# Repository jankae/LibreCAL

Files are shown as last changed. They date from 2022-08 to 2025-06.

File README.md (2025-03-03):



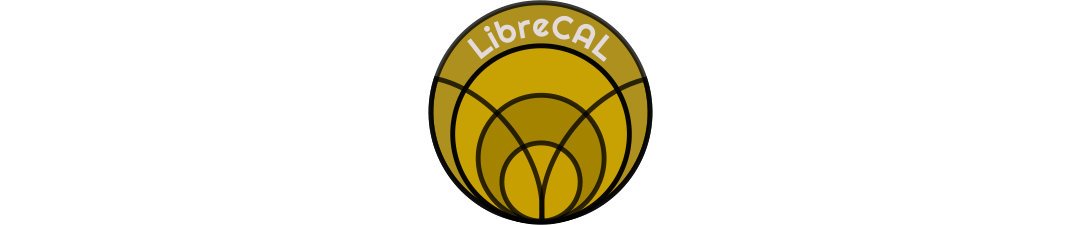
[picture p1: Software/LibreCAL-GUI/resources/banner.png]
LibreVNA


# LibreCAL
**4-port, 9kHz to 6GHz eCal module for VNAs**

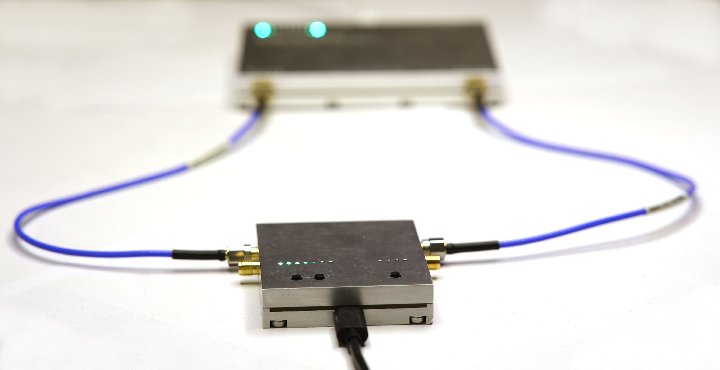
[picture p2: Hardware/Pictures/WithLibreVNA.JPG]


<p float="center">
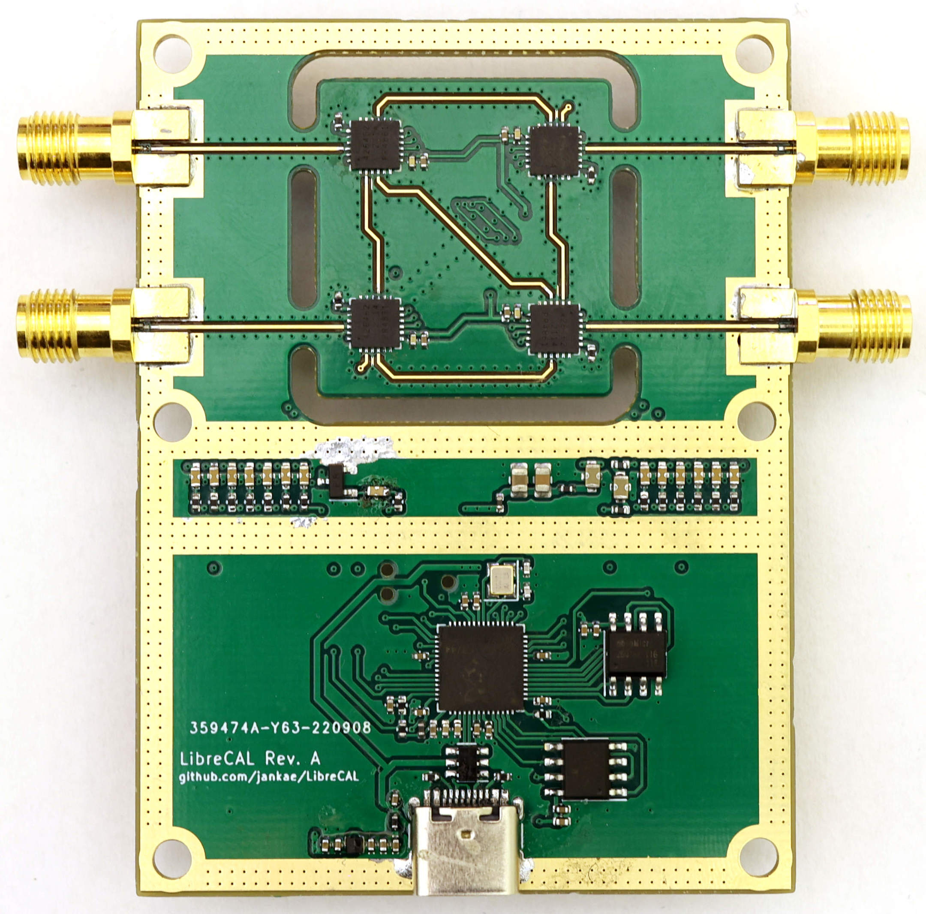
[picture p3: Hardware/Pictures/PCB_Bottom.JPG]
  
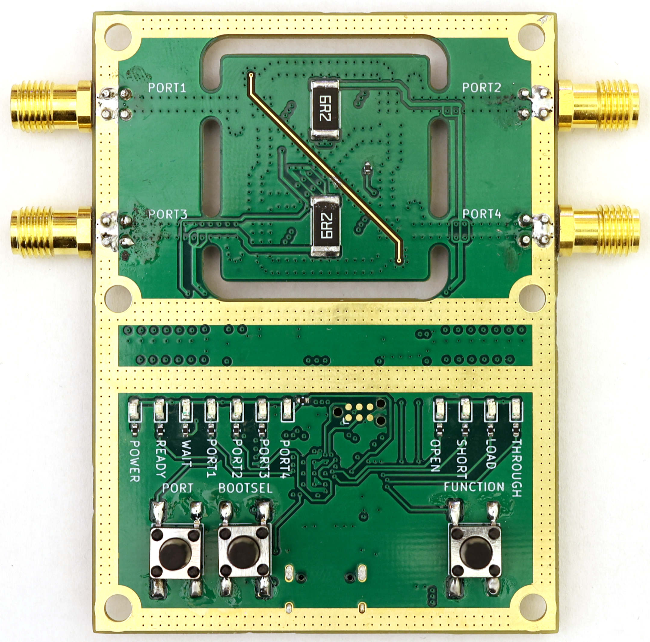
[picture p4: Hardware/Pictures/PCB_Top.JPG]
   
</p>

## Quick Start
* You can find released versions of the GUI application and the device firmware [here](https://github.com/jankae/LibreCAL/releases).
* You do *not* need the LibreCAL-GUI if you are controlling the device manually, via a script or through the [LibreVNA-GUI](https://github.com/jankae/LibreVNA).
* If you would like to try out the newest features, the compiled versions of each commit can be found [here](https://github.com/jankae/LibreCAL/actions) (but keep in mind that some features might be unstable or incomplete).
* Please see the [user manual](Documentation/manual.pdf) for details of operation.
* If you would like to control the LibreCAL with a script, see the [SCPI API](Documentation/SCPI_API.pdf).

## Factory calibration
* All LibreCAL devices are preprogrammed with individually measured factory calibration coefficients (if you build one yourself, you need a way to measure them)
* These coefficients are important, without them the LibreCAL is nothing more than an ordinary RF switch matrix
* If the coefficients have been lost, you can download them [here](https://librecal.kaeberich.com/) (based on the serial number of your LibreCAL). If no coefficients for your LibreCAL are available, it could be a clone (not produced through official channels)

## Installation

All of the following steps are only required if you plan to use the LibreCAL-GUI. If you plan to control the LibreCAL manually with the buttons, through a script or the LibreVNA-GUI, there is no need to download the LibreCAL-GUI (but you should still install the udev rule on Linux systems).

### Windows
* Download the latest [Release](https://github.com/jankae/LibreCAL/releases) and unpack the zip file
* Start the included LibreCAL-GUI.exe
* No installation or driver is required, simply move the extracted folder somewhere convenient

### Ubuntu
* Download the latest [Release](https://github.com/jankae/LibreCAL/releases) and unpack the zip file
* Install the required libraries:
```console
sudo apt install libqt6widgets6 libqt6charts6 libqt6svg6
```
* Install the udev rule (otherwise you don't have the permissions to access the USB device):
```console
wget https://raw.githubusercontent.com/jankae/LibreCAL/main/Software/52-LibreCAL.rules
sudo cp 52-LibreCAL.rules /etc/udev/rules.d
```
* Either reboot or reload the udev rules manually:
```console
sudo udevadm control --reload-rules
sudo udevadm trigger
```
* You can now start GUI:
```console
cd $UNPACKED_ZIP_FOLDER$
./LibreCAL-GUI
```

### MacOS
* Download the latest [Release](https://github.com/jankae/LibreCAL/releases)
  * If you are using MacOS 14+ use the release with `latest` in the name.
  * If you are using MacOS >13.7 use the release with  `13.7` in the name.
* Unpack the zip file and move LibreCAL-GUI.app to your `/Applications` folder.
* Start LibreCAL-GUI.app and add a security exception to allow the Mac to run the app with an "untrusted" signing key.
* Launch app again.

## How does it work?
The LibreCAL is just a switch-matrix with additional options to terminate each port into an open, short or 50 Ohm connection:



While the blockdiagram is small and simple, the tricky part of any eCal module is repeatability. The LibreCAL contains an integrated heater and temperature sensor to keep the critical parts at a constant temperature during operation. Furthermore, high quality SMA connectors are used to ensure good return loss.

The coefficients of the calibration standards are stored in standard touchstone format on the device. They must be measured and written once after assembling the PCB and housing.

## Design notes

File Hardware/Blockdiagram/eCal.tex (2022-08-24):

\documentclass[border=10pt]{standalone}  
\usepackage{tikz}
\usepackage[european,siunitx,rotatelabels]{circuitikzgit}
\usetikzlibrary{arrows,calc,positioning}
\usetikzlibrary{arrows.meta,decorations.markings}

  \tikzset{
         Heat/.style={
         draw=none,
         inner color=red,%you can erase this line
         outer color=yellow, %you can erase this line
            postaction={
                decorate,
                rounded corners=2pt,
                decoration={
                    markings,
                    mark=between positions 6pt and 55pt step 9pt
                    with {
                        \draw[-Triangle,red,line width=0.5pt](0,0)
                            --++(0.1,0.1)
                            --++(-0.2,0.1)
                            --++(0.1,0.1)
                            --++(0,0.2);
                    }
                }
            }
      }
  }

\begin{document} 

\begin{circuitikz}
% switches
\node[rotary switch <->=6 in 90 wiper 0, anchor=out 1](switch1) at (-3,3) {};
\node[rotary switch <->=6 in 90 wiper 0, anchor=out 1, xscale =-1](switch2) at (3,3){};
\node[rotary switch <->=6 in 90 wiper 0, anchor=out 1](switch3) at (-3,-3){};
\node[rotary switch <->=6 in 90 wiper 0, anchor=out 1, xscale =-1](switch4) at (3,-3){};
\node at (1.6,-0.75){4x PE426462};

% Ports
\draw (switch1.in) to[short,-o] ++(-2,0) node[left]{Port 1};
\draw (switch2.in) to[short,-o] ++(2,0) node[right]{Port 2};
\draw (switch3.in) to[short,-o] ++(-2,0) node[left]{Port 3};
\draw (switch4.in) to[short,-o] ++(2,0) node[right]{Port 4};

% Throughs
\draw (switch1.out 6)--(switch3.out 1);
\draw (switch2.out 6)--(switch4.out 1);
\draw (switch1.out 1)|-++(0,0.5)-|(switch2.out 1);
\draw (switch3.out 6)|-++(0,-0.5)-|(switch4.out 6);
\draw (switch1.out 5)--(switch4.out 2);
\draw (switch2.out 5)--(switch3.out 2);

% Shorts
\draw (switch1.out 3)-|++(0.5, -0.5) node[ground]{};
\draw (switch2.out 3)-|++(-0.5, -0.5) node[ground]{};
\draw (switch3.out 4)-|++(0.5, -0.1) node[ground]{};
\draw (switch4.out 4)-|++(-0.5, -0.1) node[ground]{};

% Loads
\draw (switch1.out 2) to[R, l=$50\Omega$] ++(2,0) -| ++(0,-0.2) node[ground]{};
\draw (switch2.out 2)++(-2,-0.2) node[ground]{}|-++(0,0.2) to[R, l=$50\Omega$] ++(2,0);
\draw (switch3.out 3) to[R, l=$50\Omega$] ++(2,0) -| ++(0,-0.2) node[ground]{};
\draw (switch4.out 3)++(-2,-0.2) node[ground]{}|-++(0,0.2) to[R, l=$50\Omega$] ++(2,0);

% Thermal control
\node[draw,dashed, minimum width=8cm,minimum height=12cm](thermal) at (0,-2){};
\node[anchor=south] at (thermal.north) {Dashed part is thermally isolated};
\node[draw,minimum width=8cm, minimum height=2cm](rp) at (0,-10){RP2040/Flash/Power supply};
\draw (rp.north)++(-3,0)--++(0,2) to[thRn=$NTC$] ++(2,0) --++(0,-2);
\draw (rp.north)++(1,0)--++(0,2) to[R,l_=$Heater$,n=heater] ++(2,0) --++(0,-2);
\draw[Heat](heater.north west) -- (heater.north east);

% USB
\draw (rp.south) to[short,-o]++(0,-1) node[below]{USB};

\end{circuitikz}
\end{document}

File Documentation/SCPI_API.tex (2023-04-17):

\documentclass[a4paper,11pt]{article}

\usepackage[utf8]{inputenc}
\usepackage[T1]{fontenc} % LY1 also works
\usepackage[margin=1in]{geometry}

%% Font settings suggested by fbb documentation.
\usepackage{textcomp} % to get the right copyright, etc.
\usepackage[lining,tabular]{fbb} % so math uses tabular lining figures
\usepackage[scaled=.95,type1]{cabin} % sans serif in style of Gill Sans
\usepackage[varqu,varl]{zi4}% inconsolata typewriter
\useosf % change normal text to use proportional oldstyle figures
%\usetosf would provide tabular oldstyle figures in text

\usepackage{svg}

\usepackage{enumitem}
\usepackage{longtable}
\setitemize{noitemsep,topsep=0pt,parsep=0pt,partopsep=0pt}
\setlist{leftmargin=*}
\usepackage{listings}
\definecolor{darkgreen}{RGB}{0,140,0}
\lstset{
	basicstyle=\ttfamily,
	frame=single,
	breaklines=true,
	morecomment=[l][\color{darkgreen}]{\#},
}
\lstnewenvironment{example}{\lstset{
    ,frame=single
    ,xleftmargin=2em
    ,xrightmargin=2em
   % ,backgroundcolor=\color{lightgray}
    ,title=Example
}}{}
\usepackage{makecell}
\usepackage{hyperref}

\newcommand{\dev}{LibreCAL}
\newcommand{\gui}{\dev{}-GUI}

\newcommand{\screenshot}[2]{\begin{center}

\end{center}}

\newcommand{\event}[3]{
\noindent\textbf{Event:}
\begin{longtable}{p{.15\textwidth} | p{.80\textwidth} } 
\hline
\textbf{Effect:} & #1 \\ \hline
\textbf{Syntax:} & #2 \\ \hline 
\textbf{Parameters:} & \makecell[Xl]{#3} \\ \hline
\end{longtable}
}
\newcommand{\query}[4]{
\noindent\textbf{Query:}
\begin{longtable}{p{.15\textwidth} | p{.80\textwidth} } 
\hline
\textbf{Effect:} & #1 \\ \hline
\textbf{Syntax:} & #2 \\ \hline 
\textbf{Parameters:} & \makecell[tl]{#3} \\ \hline
\textbf{Return value:} & \makecell[tl]{#4} \\ \hline
\end{longtable}
}

\title{\dev{} SCPI Programming Guide}
\begin{document}
\maketitle

\setcounter{tocdepth}{3}
\tableofcontents

\clearpage

\section{Introduction}
The \dev{} firmware contains its own SCPI parser. The \gui{} is not necessary to use the SCPI commands.

There are two ways to send SCPI commands:
\begin{itemize}
\item \textbf{Virtual COM Port (VCP):} The \dev{} implements a VCP over which SCPI commands can be received.
\item \textbf{Custom USB interface:} The \dev{} implements a custom USB interface over which SCPI commands can be received.
\end{itemize}
Only one of these options should be used at a time. The advantage of the VCP is ease of use (any terminal will work), while the custom interface provides easier device identification (no need to manually assign COM ports) and is used by the \gui{}.

\section{General Syntax}
The syntax follows most SCPI rules:
\begin{itemize}
\item Arguments are case \textbf{sensitive}. While non-standard, this allows for more flexibility when naming coefficients. The command is still case \textbf{insensitive}.
\item The command tree is organized in branches, separated by a colon:
\begin{lstlisting}
:TEMPerature:STABLE?
\end{lstlisting}
\item Branches and commands can be abbreviated by using only the uppercase part of their name, the following commands are identical:
\begin{lstlisting}
:HEATer:POWer?
:HEAT:POW?
\end{lstlisting}
\item Every command generates a (possibly empty) response, terminated with a newline character.
\item Some commands require additional arguments that have to be passed after the command (separated by spaces):
\begin{lstlisting}
:TEMPerature 35
\end{lstlisting}
\item Two types of commands are available:
\begin{itemize}
\item \textbf{Events} change a setting or trigger an action. They usually have an empty response (unless there was an error).
\item \textbf{Queries} request information. They end with a question mark.
\end{itemize}
Some commands are both events and queries, depending on whether the question mark is present:
\begin{lstlisting}
:PORT? 1 # Returns the currently used standard at port 1
:PORT 1 OPEN # Configures port 1 to use the OPEN standard
\end{lstlisting}
\item Multiple commands per line (separated by a semicolon) are \textbf{not} supported.
\end{itemize}
\section{Commands}
\subsection{General Commands}
\subsubsection{*IDN}
\query{Returns the identifications string}{*IDN?}{None}{LibreCAL,LibreCAL,<serial>,<firmware\_version>}
\subsubsection{*LST}
\query{Lists all available commands}{*LST?}{None}{List of commands, separated by newline}
\subsubsection{:FIRMWARE}
\query{Returns the firmware version}{:FIRMWARE?}{None}{<major>.<minor>.<patch>}
\subsubsection{:BOOTloader}
\event{Reboots and enters the bootloader mode}{:BOOTloader}{None}
This is equivalent to pressing the "BOOTSEL" button when applying power.

\subsubsection{:DATE\_TIME}
\event{Sets local Date Time with UTC offset}{:DATE\_TIME <DATE> <TIME> <UTC>}{<DATE>Format YYYY/MM/DD\\<TIME>Format hh:mm:ss\\<UTC>Format UTC+/-hh:mm}
\query{Returns the local Date Time with UTC offset}{:DATE\_TIME?}{NONE}{local Date Time with UTC offset}

Example: Date Time with UTC offset(France):
\begin{lstlisting}
2023/03/20 17:06:58 UTC+01:00
\end{lstlisting}

\subsection{Port Control Commands}
This section contains commands to control and check the configuration of the ports.
\subsubsection{:PORTS}
\query{Returns the number of available ports}{:PORTS?}{None}{Number of ports, usually 4}
\subsubsection{:PORT}
\event{Set a port standard}{:PORT <port> <standard> [<dest>]}{<port> Port number, 1-4\\<standard> Selected standard, one of:\\OPEN\\SHORT\\LOAD\\THROUGH\\NONE\\<dest> Destination port of other the end, 1-4 (only required for THROUGH)\\}
When a port is set to through, <dest> is automatically also set to through (with <port> as its <dest>). Setting a port that is currently set to through to any other standard, sets the <dest> of that port to NONE.

Example:
\begin{lstlisting}
# Sets port 1 to LOAD standard
:PORT 1 LOAD
# Creates a through between port 2 and 3. This configures both ports
# as THROUGH with each other as the destination ports
:PORT 2 THROUGH 3 
# Returns "THROUGH 2" because port 3 was also configured by the
# previous command
:PORT? 3
# Sets port 2 to SHORT standard. Because it was previously
# configured as THROUGH to port 3, port 3 will be set to NONE
:PORT 2 SHORT
# Returns "NONE"
:PORT? 3
\end{lstlisting}
\query{Returns the currently used standard at a port}{:PORT? <port>}{<port> Port number}{Standard, one of:\\OPEN\\SHORT\\LOAD\\THROUGH <dest>\\NONE}

\subsection{Temperature Control Commands}
This section contains commands related to the temperature regulation of the \dev{}. While it is possible to change the target temperature, this is not recommended as calibration coefficients will no longer be accurate due to temperature drift.
\subsubsection{:TEMPerature}
\event{Sets the target temperature}{:TEMPerature <temp>}{<temp> Target temperature in celsius}
\query{Returns the measured temperature}{:TEMPerature?}{NONE}{float value, current temperature in celsius}
\subsubsection{:TEMPerature:STABLE}
\query{Checks whether the target temperature has been reached}{:TEMPerature:STABLE?}{NONE}{TRUE or FALSE}
\subsubsection{:HEATer:POWer}
\query{Returns the currently used power by the heater}{:HEATer:POWer?}{NONE}{float value, heater power in watt}

\subsection{Coefficient Commands}
This section containg commands related to reading, creating and deleting calibration coefficients.

Some definitions:
\begin{itemize}
\item \textbf{Coefficient data:} S parameters for a specific standard at a given port and selected frequency. It consists of one complex value for reflection standards (open, short, load) and four complex values for transmission standards (through).
\item \textbf{Coefficient:} A list of coefficient data, containing multiple points over a frequency range. Each coefficient within a coefficient set is identified by its coefficient name. This name can be any of the following:
\begin{itemize}
\item P1\_OPEN
\item P1\_SHORT
\item P1\_LOAD
\item P2\_OPEN
\item P2\_SHORT
\item P2\_LOAD
\item P3\_OPEN
\item P3\_SHORT
\item P3\_LOAD
\item P4\_OPEN
\item P4\_SHORT
\item P4\_LOAD
\item P12\_THROUGH
\item P13\_THROUGH
\item P14\_THROUGH
\item P23\_THROUGH
\item P24\_THROUGH
\item P34\_THROUGH
\end{itemize}
\item \textbf{Coefficient set:} A named set of coefficients, contains all the different coefficients that are required to cover every port setting. The coefficient set is identified by its set name.
\end{itemize}
\subsubsection{:COEFFicient:LIST}
\query{Returns the names of all available coefficient sets}{:COEFFicient:LIST?}{NONE}{comma-separated list of coefficient set names}
\subsubsection{:COEFFicient:DELete}
\event{Deletes a calibration coefficient}{:COEFFicient:DELete <set name> <coefficient name>}{<set name> Name of the coefficient set\\<coefficient name> Name of the coefficient}
\subsubsection{:COEFFicient:NUMber}
\query{Returns the number of data points within a coefficient}{:COEFFicient:NUMber? <set name> <coefficient name>}{<set name> Name of the coefficient set\\<coefficient name> Name of the coefficient>}{Integer, number of data points in coefficient}
\subsubsection{:COEFFicient:GET}
\query{Returns coefficient data from a coefficient}{:COEFFicient:GET? <set name> <coefficient name> <index>}{<set name> Name of the coefficient set\\<coefficient name> Name of the coefficient>\\<index> Data point number}{comma-separated list of float values}
The first value returned is the frequency (in GHz), followed by the S parameters. Each S parameter is split into two float values, the first value is the real part, the second value the imaginary part. For reflection standards, only one S parameter is returned (S11). For transmission standards, four S parameters are returned in S11, S21, S12, S22 order.
\subsubsection{:COEFFicient:CREATE}
\event{Creates a new calibration coefficient}{:COEFFicient:CREATE <set name> <coefficient name>}{<set name> Name of the coefficient set\\<coefficient name> Name of the coefficient}
If the coefficient already exists, it will be deleted first (along with all its coefficient data). Afterwards, a new and empty coefficient will be created.

This command should be used in conjunction with :COEFFicient:ADD\_COMMENT, :COEFFicient:ADD and :COEFFicient:FINish.
\subsubsection{:COEFFicient:ADD\_COMMENT}
\event{Add ASCII text comment before to add coefficient datapoint}{:COEFFicient:ADD\_COMMENT <ASCII text comment>}{<ASCII text comment> add an ASCII text comment with size up to 120chars\\if the comment exceed 120 characters it will be truncated to 120 characters}

This command should be used only after :COEFFicient:CREATE as it is intended to add comment before to add any datapoint (:COEFFicient:ADD).

There is a limitation of maximum 100 comments per calibration coefficient (:COEFFicient:CREATE)(if there is more comment the command will return an error and comment will be not added).
\subsubsection{:COEFFicient:ADD}
\event{Add a datapoint to an existing coefficient}{:COEFFicient:ADD <frequency> <S parameters>}{<frequency> Frequency of the datapoint, in GHz\\
<S parameters> S parameters, split into real and imaginary parts}
This command should be used in conjunction with :COEFFicient:CREATE and :COEFFicient:FINish. It must only be used after a coefficient has been created using :COEFFicient:CREATE and before the coefficient has been completed by :COEFFicient:FINish.

The order of values in the S parameter argument is the same as for the :COEFFicient:GET command, except that values are separated by spaces instead of a comma. Reflection standard require one S parameter (two arguments), transmission standards require four S parameters (eight arguments).
\subsubsection{:COEFFicient:FINish}
\event{Completes the creation of a coefficient}{:COEFFicient:FINish}{None}
This command should be used in conjunction with :COEFFicient:CREATE and :COEFFicient:Add. It must be used after all data has been added to the coefficient.

\subsubsection{:FACTory:ENABLEWRITE}
The default coefficient set ("FACTORY") is read-only to prevent accidentally overwriting or deleting these important coefficients. Unless you are building your own \dev{}, you should never change these coefficients!

This command makes all coefficient sets writable. DO NOT USE UNLESS YOU KNOW WHAT YOU ARE DOING!

Once issued, the default coefficient set stays writable until the next reboot.

\event{Make all coefficient sets writable}{:FACTory:ENABLEWRITE <key>}{<key> Prevents accidental usage, set to "I\_AM\_SURE"}
\end{document}

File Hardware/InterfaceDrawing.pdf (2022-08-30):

1 A 2 3 4 5 6 7 8 1 2 3 4 5 6 7 8 FEDCB FEDCBA Dept. Technical reference Created by Approved by Title DWG No. Document type Document status Rev. Date of issue Sheet 30/08/2022 1/1 LibreCAL Jan Käberich Port 4 Port 2 Port 1 Port 3 Bootsel: Press while connecting USB to enter bootloader USB connector (open, short, load, through) at the selected port Function select: Press to toggle between modes Port select: Press to toggle between ports when manually selecting the switch state Port 2 LED: on when port 2 is selected Port 1 LED: on when port 1 is selected Port 4 LED: on when port 4 is selected Port 3 LED: on when port 3 is selected Power LED: on whenever USB power is available Ready LED: on when stable temperature has been reached Wait LED: on while temperature is unstable active at the selected port Load LED: on when "load" standard is is active at the selected port Through LED: on when "through" standard active at the selected port Short LED: on when "short" standard is active at the selected port Open LED: on when "open" standard is

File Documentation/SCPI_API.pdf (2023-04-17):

## LibreCAL SCPI Programming Guide

March 21, 2023

## Contents

1 Introduction | 2
2 General Syntax | 2
3 Commands | 2

## 1 Introduction

The LibreCAL firmware contains its own SCPI parser. The LibreCAL-GUI is not necessary to use the SCPI commands.
There are two ways to send SCPI commands:
- Virtual COM Port (VCP): The LibreCAL implements a VCP over which SCPI commands can be received.
- Custom USB interface: The LibreCAL implements a custom USB interface over which SCPI commands can be received.
Only one of these options should be used at a time. The advantage of the VCP is ease of use (any terminal will work), while the custom interface provides easier device identification (no need to manually assign COM ports) and is used by the LibreCAL-GUI.

## 2 General Syntax

The syntax follows most SCPI rules:
- Arguments are case sensitive. While non-standard, this allows for more flexibility when naming coefficients. The command is still case insensitive.
- The command tree is organized in branches, separated by a colon:

: TEMPerature : STABLE ?

- Branches and commands can be abbreviated by using only the uppercase part of their name, the following commands are identical:

: HEATer : POWer ?
: HEAT : POW ?
- Every command generates a (possibly empty) response, terminated with a newline character.
- Some commands require additional arguments that have to be passed after the command (separated by spaces):

: TEMPerature 35

- Two types of commands are available:
– Events change a setting or trigger an action. They usually have an empty response (unless there was an error).
– Queries request information. They end with a question mark.
Some commands are both events and queries, depending on whether the question mark is present:

: PORT ? 1 # Returns the currently used standard at port 1
: PORT 1 OPEN # Configures port 1 to use the OPEN standard
- Multiple commands per line (separated by a semicolon) are not supported.

## 3 Commands

### 3.1 General Commands

3.1.1 *IDN
Query:
Effect: | Returns the identifications string
Syntax: | *IDN?

Parameters: | None
Return value: | LibreCAL,LibreCAL,<serial>,<firmware_version>

3.1.2 *LST
Query:
Effect: | Lists all available commands
Syntax: | *LST?
Parameters: | None
Return value: | List of commands, separated by newline

3.1.3 :FIRMWARE
Query:
Effect: | Returns the firmware version
Syntax: | :FIRMWARE?
Parameters: | None
Return value: | <major>.<minor>.<patch>

3.1.4 :BOOTloader
Event:
Effect: | Reboots and enters the bootloader mode
Syntax: | :BOOTloader
Parameters: | None

This is equivalent to pressing the "BOOTSEL" button when applying power.

3.1.5 :DATE_TIME
Event:
Effect: | Sets local Date Time with UTC offset
Syntax: | :DATE_TIME <DATE> <TIME> <UTC>
Parameters: | <DATE>Format YYYY/MM/DD <TIME>Format hh:mm:ss <UTC>Format UTC+/-hh:mm

Query:

Effect: | Returns the local Date Time with UTC offset
Syntax: | :DATE_TIME?
Parameters: | NONE
Return value: | local Date Time with UTC offset

Example: Date Time with UTC offset(France):

2023/03/20 17:06:58 UTC +01:00

### 3.2 Port Control Commands

This section contains commands to control and check the configuration of the ports.

3.2.1 :PORTS
Query:
Effect: | Returns the number of available ports
Syntax: | :PORTS?
Parameters: | None
Return value: | Number of ports, usually 4

3.2.2 :PORT
Event:
Effect: | Set a port standard
Syntax: | :PORT <port> <standard> [<dest>]

Parameters:

<port> Port number, 1-4
<standard> Selected standard, one of: OPEN
SHORT
LOAD
THROUGH
NONE
<dest> Destination port of other the end, 1-4 (only required for THROUGH)

When a port is set to through, <dest> is automatically also set to through (with <port> as its <dest>). Setting a port that is currently set to through to any other standard, sets the <dest> of that port to NONE.
Example:

# Sets port 1 to LOAD standard

: PORT 1 LOAD
# Creates a through between port 2 and 3. This configures both ports # as THROUGH with each other as the destination ports

: PORT 2 THROUGH 3
# Returns " THROUGH 2" because port 3 was also configured by the

# previous command

: PORT ? 3
# Sets port 2 to SHORT standard . Because it was previously

# configured as THROUGH to port 3 , port 3 will be set to NONE : PORT 2 SHORT

# Returns " NONE "

: PORT ? 3

Query:

Effect: | Returns the currently used standard at a port
Syntax: | :PORT? <port>
Parameters: | <port> Port number

Return value: | Standard, one of:
| OPEN SHORT LOAD THROUGH <dest>
| NONE

### 3.3 Temperature Control Commands

This section contains commands related to the temperature regulation of the LibreCAL. While it is possible to change the target temperature, this is not recommended as calibration coefficients will no longer be accurate due to temperature drift.

3.3.1 :TEMPerature
Event:
Effect: | Sets the target temperature
Syntax: | :TEMPerature <temp>
Parameters: | <temp> Target temperature in celsius

Query:

Effect: | Returns the measured temperature
Syntax: | :TEMPerature?
Parameters: | NONE
Return value: | float value, current temperature in celsius

3.3.2 :TEMPerature:STABLE
Query:
Effect: | Checks whether the target temperature has been reached
Syntax: | :TEMPerature:STABLE?
Parameters: | NONE
Return value: | TRUE or FALSE

3.3.3 :HEATer:POWer
Query:
Effect: | Returns the currently used power by the heater
Syntax: | :HEATer:POWer?
Parameters: | NONE
Return value: | float value, heater power in watt

### 3.4 Coefficient Commands

This section containg commands related to reading, creating and deleting calibration coefficients. Some definitions:
- Coefficient data: S parameters for a specific standard at a given port and selected frequency. It consists of one complex value for reflection standards (open, short, load) and four complex values for transmission standards (through).
- Coefficient: A list of coefficient data, containing multiple points over a frequency range. Each coefficient within a coefficient set is identified by its coefficient name. This name can be any of the following:
– P1_OPEN
– P1_SHORT
– P1_LOAD
– P2_OPEN
– P2_SHORT
– P2_LOAD
– P3_OPEN
– P3_SHORT
– P3_LOAD
– P4_OPEN
– P4_SHORT
– P4_LOAD
– P12_THROUGH
– P13_THROUGH
– P14_THROUGH
– P23_THROUGH
– P24_THROUGH
– P34_THROUGH
- Coefficient set: A named set of coefficients, contains all the different coefficients that are required to cover every port setting. The coefficient set is identified by its set name.

3.4.1 :COEFFicient:LIST
Query:
Effect: | Returns the names of all available coefficient sets
Syntax: | :COEFFicient:LIST?
Parameters: | NONE
Return value: | comma-separated list of coefficient set names

3.4.2 :COEFFicient:DELete
Event:
Effect: | Deletes a calibration coefficient
Syntax: | :COEFFicient:DELete <set name> <coefficient name>
Parameters: | <set name> Name of the coefficient set <coefficient name> Name of the coefficient

3.4.3 :COEFFicient:NUMber
Query:
Effect: | Returns the number of data points within a coefficient
Syntax: | :COEFFicient:NUMber? <set name> <coefficient name>
Parameters: | <set name> Name of the coefficient set <coefficient name> Name of the coefficient>
Return value: | Integer, number of data points in coefficient

3.4.4 :COEFFicient:GET
Query:
Effect: | Returns coefficient data from a coefficient
Syntax: | :COEFFicient:GET? <set name> <coefficient name> <index>
Parameters: | <set name> Name of the coefficient set <coefficient name> Name of the coefficient> <index> Data point number
Return value: | comma-separated list of float values

The first value returned is the frequency (in GHz), followed by the S parameters. Each S parameter is split into two float values, the first value is the real part, the second value the imaginary part. For reflection standards, only one S parameter is returned (S11). For transmission standards, four S parameters are returned in S11, S21, S12, S22 order.

3.4.5 :COEFFicient:CREATE
Event:
Effect: | Creates a new calibration coefficient
Syntax: | :COEFFicient:CREATE <set name> <coefficient name>
Parameters: | <set name> Name of the coefficient set <coefficient name> Name of the coefficient

If the coefficient already exists, it will be deleted first (along with all its coefficient data). Afterwards, a new and empty coefficient will be created.
This command should be used in conjunction with :COEFFicient:ADD_COMMENT, :CO-EFFicient:ADD and :COEFFicient:FINish.

3.4.6 :COEFFicient:ADD_COMMENT
Event:
Effect: | Add ASCII text comment before to add coefficient datapoint
Syntax: | :COEFFicient:ADD_COMMENT <ASCII text comment>
Parameters: | <ASCII text comment> add an ASCII text comment with size up to 120chars if the comment exceed 120 characters it will be truncated to 120 characters

This command should be used only after :COEFFicient:CREATE as it is intended to add comment before to add any datapoint (:COEFFicient:ADD).
There is a limitation of maximum 100 comments per calibration coefficient (:COEFFicient:CREATE)(if there is more comment the command will return an error and comment will be not added).

3.4.7 :COEFFicient:ADD
Event:
Effect: | Add a datapoint to an existing coefficient
Syntax: | :COEFFicient:ADD <frequency> <S parameters>
Parameters: | <frequency> Frequency of the datapoint, in GHz <S parameters> S parameters, split into real and imaginary parts

This command should be used in conjunction with :COEFFicient:CREATE and :COEFFicient:FINish. It must only be used after a coefficient has been created using :COEFFicient:CREATE and before the coefficient has been completed by :COEFFicient:FINish.
The order of values in the S parameter argument is the same as for the :COEFFicient:GET command, except that values are separated by spaces instead of a comma. Reflection standard require one S parameter (two arguments), transmission standards require four S parameters (eight arguments).

3.4.8 :COEFFicient:FINish
Event:
Effect: | Completes the creation of a coefficient
Syntax: | :COEFFicient:FINish
Parameters: | None

This command should be used in conjunction with :COEFFicient:CREATE and :COEFFicient:Add. It must be used after all data has been added to the coefficient.

3.4.9 :FACTory:ENABLEWRITE

The default coefficient set ("FACTORY") is read-only to prevent accidentally overwriting or deleting these important coefficients. Unless you are building your own LibreCAL, you should never change these coefficients!
This command makes all coefficient sets writable. DO NOT USE UNLESS YOU KNOW WHAT YOU ARE DOING!
Once issued, the default coefficient set stays writable until the next reboot.
Event:
Effect: | Make all coefficient sets writable
Syntax: | :FACTory:ENABLEWRITE <key>
Parameters: | <key> Prevents accidental usage, set to "I_AM_SURE"

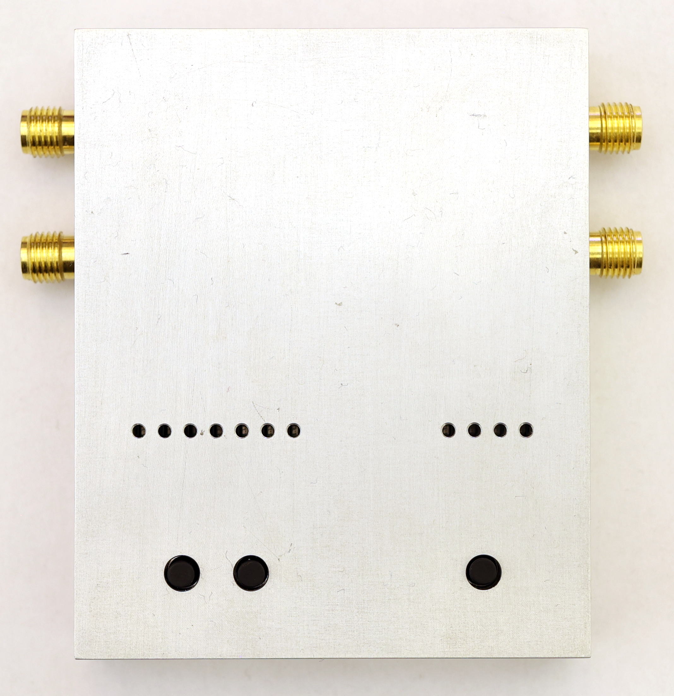
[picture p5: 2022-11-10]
Hardware/Pictures/Top.JPG

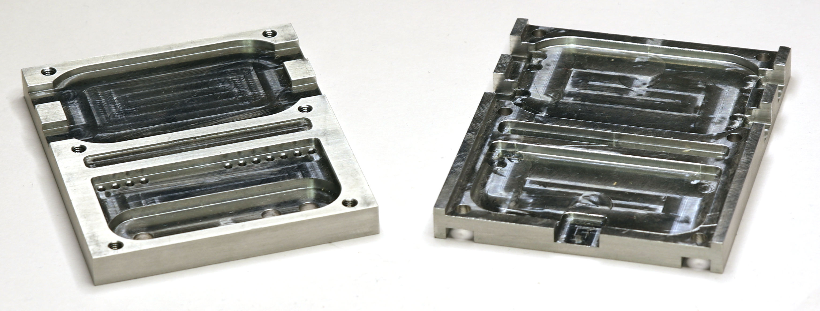
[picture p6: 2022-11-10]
Hardware/Pictures/Cover.JPG

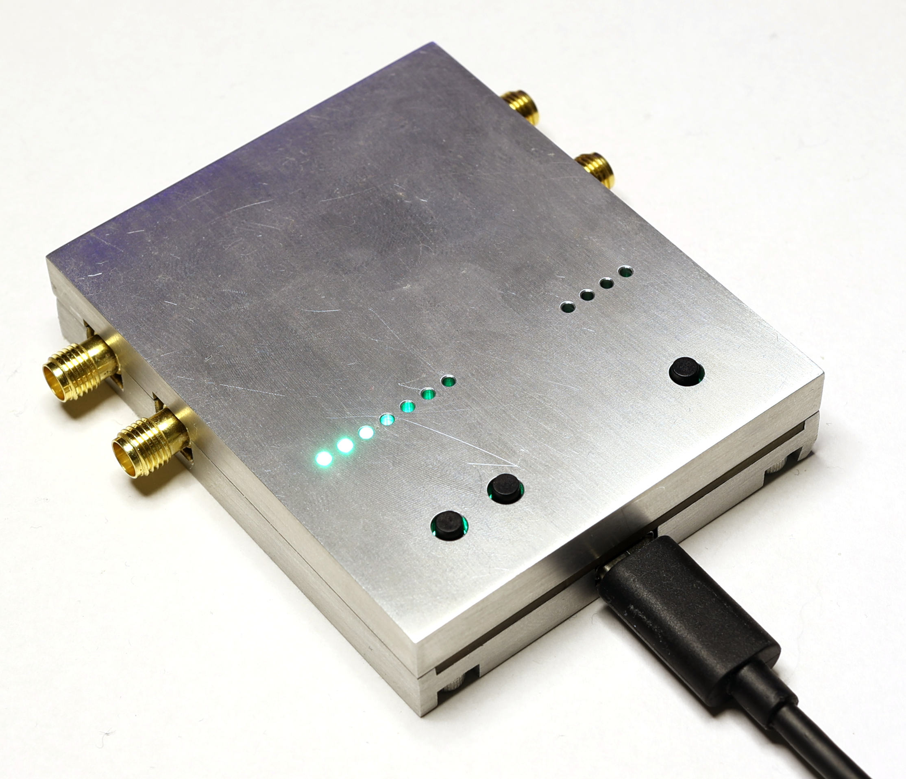
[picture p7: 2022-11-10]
Hardware/Pictures/Top2.JPG

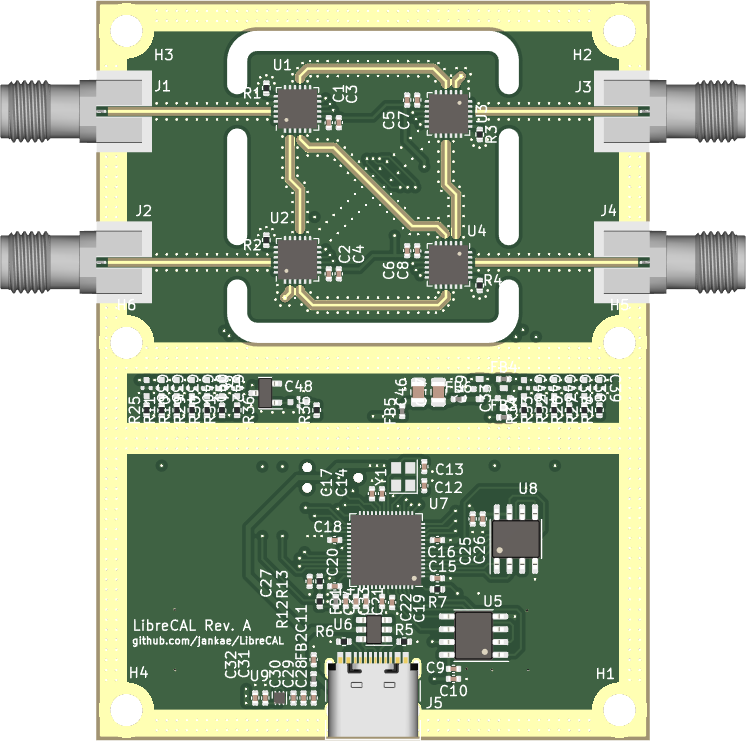
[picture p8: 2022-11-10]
Hardware/LibreCAL.png

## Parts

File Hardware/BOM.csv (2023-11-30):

Source: | /home/jan/Projekte/LibreCAL/Hardware/LibreCAL/LibreCAL.kicad_sch
Date: | Do 30 Nov 2023 18:18:11 CET
Tool: | Eeschema 7.0.8-7.0.8~ubuntu22.04.1
Generator: | /usr/share/kicad/plugins/bom_csv_grouped_by_value_with_fp.py
Component Count: | 123
Ref | Qnty | Value | Cmp name | Footprint | Description | Vendor | DNP
C1, C2, C7, C8 | 4 | 10n | C | Capacitor_SMD:C_0402_1005Metric | Unpolarized capacitor
C3, C4, C5, C6, C9, C11, C14, C15, C16, C17, C18, C19, C20, C22, C26, C30, C31 | 17 | 100n | C | Capacitor_SMD:C_0402_1005Metric | Unpolarized capacitor
C10, C21, C23, C24, C25, C27, C28, C29, C32 | 9 | 2u2 | C | Capacitor_SMD:C_0402_1005Metric | Unpolarized capacitor
C12, C13 | 2 | 12p | C | Capacitor_SMD:C_0402_1005Metric | Unpolarized capacitor
C33, C49 | 2 | NFM21PC475B1A3D | C_Feedthrough | LibreCAL:NFM21PC | Feedthrough capacitor
C34, C35, C36, C37, C38, C39, C40, C41, C42, C43, C44, C45, C48, C50 | 14 | NFM18CC223R1C3D | C_Feedthrough | LibreCAL:NFM18CC | Feedthrough capacitor
C46, C47 | 2 | 22u | C | Capacitor_SMD:C_0805_2012Metric | Unpolarized capacitor
D1, D2, D4, D5, D6, D7, D8, D9, D10, D11 | 10 | Green | LED | LED_SMD:LED_0603_1608Metric | Light emitting diode
D3 | 1 | Red | LED | LED_SMD:LED_0603_1608Metric | Light emitting diode
FB1, FB2, FB5, FB6 | 4 | MMZ1005S121CTD25 | FerriteBead_Small | Inductor_SMD:L_0402_1005Metric | Ferrite bead, small symbol
FB3, FB4 | 2 | MMZ1005A222ET000 | FerriteBead_Small | Inductor_SMD:L_0402_1005Metric | Ferrite bead, small symbol
J1, J2, J3, J4 | 4 | 901-10510-2 | 901-10510-2 | LibreCAL:901-10510-2 | High quality SMA connector, Amphenol
J5 | 1 | USB_C_Receptacle_USB2.0 | USB_C_Receptacle_USB2.0 | Connector_USB:USB_C_Receptacle_HRO_TYPE-C-31-M-12 | USB 2.0-only Type-C Receptacle connector
Q1 | 1 | IRLML2060 | IRLML2060 | Package_TO_SOT_SMD:SOT-23 | 1.2A Id, 60V Vds, 480mOhm Rds, N-Channel HEXFET Power MOSFET, SOT-23
R1, R2, R3, R4 | 4 | CH0402-50RGFTA | R | Resistor_SMD:R_0402_1005Metric | Resistor
R5, R6 | 2 | 5k1 | R | Resistor_SMD:R_0402_1005Metric | Resistor
R7 | 1 | 1k | R | Resistor_SMD:R_0402_1005Metric | Resistor
R8, R9 | 2 | 6R2 | R | Resistor_SMD:R_2512_6332Metric | Resistor
R10, R11, R25, R26, R27, R28, R29, R30, R31, R32, R33, R34, R35 | 13 | 47k | R | Resistor_SMD:R_0402_1005Metric | Resistor
R12, R13 | 2 | 10k | R | Resistor_SMD:R_0402_1005Metric | Resistor
R14, R15, R16, R17, R18, R19, R20, R21, R22, R23, R24 | 11 | 330 | R | Resistor_SMD:R_0402_1005Metric | Resistor
R36 | 1 | 100 | R | Resistor_SMD:R_0402_1005Metric | Resistor
SW1 | 1 | TL3301NF160QG | SW_MEC_5E | LibreCAL:TL3301N-J | MEC 5E single pole normally-open tactile switch
SW2, SW3 | 2 | TL3301CF160QG | SW_MEC_5E | LibreCAL:TL3301C-J | MEC 5E single pole normally-open tactile switch
TH1 | 1 | ERT-J0ER103J | Thermistor_NTC | Resistor_SMD:R_0402_1005Metric | Temperature dependent resistor, negative temperature coefficient
U1, U2, U3, U4 | 4 | PE426462 | PE426462 | Package_DFN_QFN:QFN-24-1EP_4x4mm_P0.5mm_EP2.7x2.7mm
U5 | 1 | W25Q16JVSNIQ | W25Q16JVSNIQ | Package_SO:SOIC-8_3.9x4.9mm_P1.27mm
U6 | 1 | IP4234CZ6 | IP4234CZ6 | Package_TO_SOT_SMD:SOT-23-6
U7 | 1 | RP2040 | RP2040 | LibreCAL:RP2040 | A microcontroller by Raspberry Pi
U8 | 1 | W25Q128JVSIQ | W25Q16JVSNIQ | Package_SO:SOIC-8_5.23x5.23mm_P1.27mm
U9 | 1 | MIC5528-3.3YMT-TR | MIC5528 | LibreCAL:DFN-6-1EP_1.2x1.2mm_P0.4mm_EP0.3x0.94mm | LDO
Y1 | 1 | ECS-120-8-36-CKM-TR3 | Crystal_GND24 | Crystal:Crystal_SMD_2520-4Pin_2.5x2.0mm | Four pin crystal, GND on pins 2 and 4

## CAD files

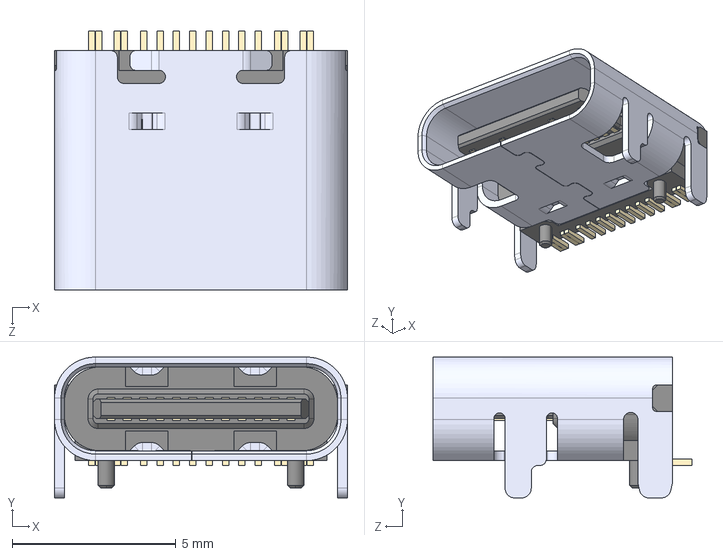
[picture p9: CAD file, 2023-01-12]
Hardware/LibreCAL/KiCad3DFiles/HRO_TYPE-C-31-M-12.step
8.94 x 4.30 x 7.90 mm

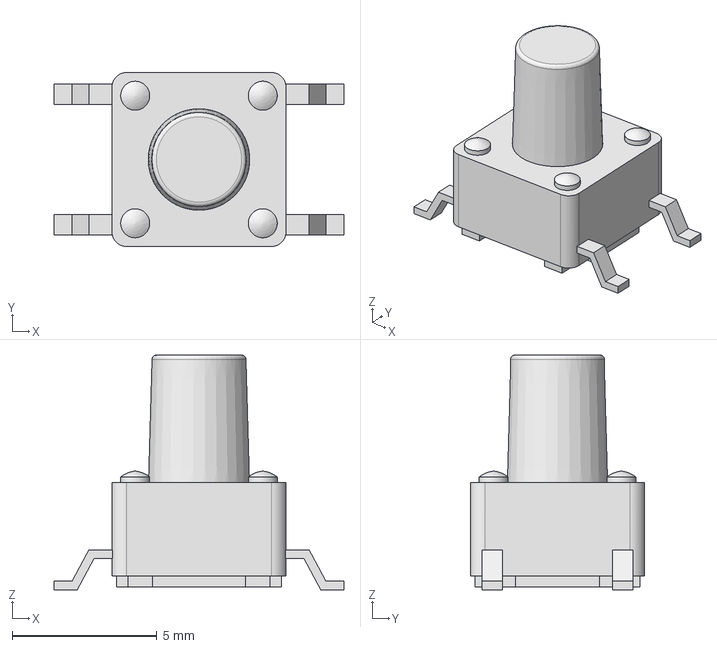
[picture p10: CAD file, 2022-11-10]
Hardware/LibreCAL/KiCad3DFiles/TactileSwitch8mm.stp
10.00 x 6.00 x 8.10 mm

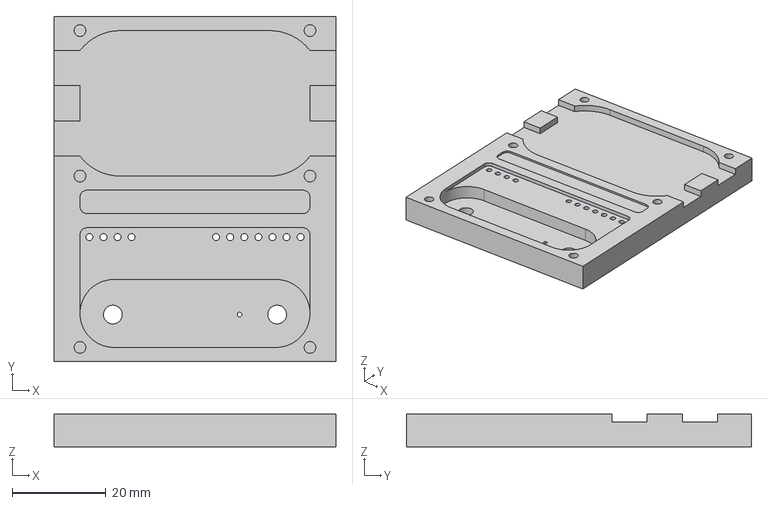
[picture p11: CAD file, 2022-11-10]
Hardware/TopCover.step
60.0 x 73.5 x 7.00 mm

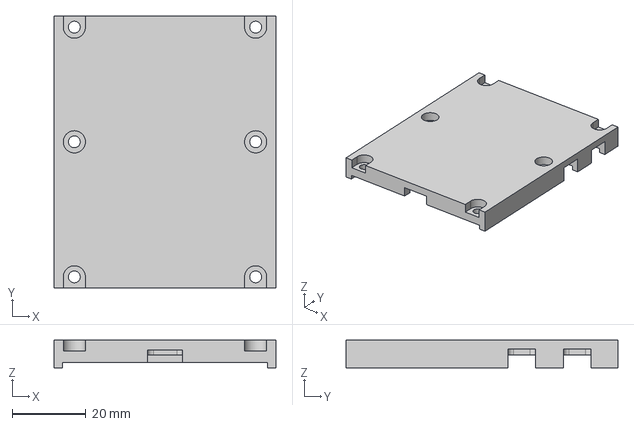
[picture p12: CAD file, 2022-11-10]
Hardware/BottomCover.step
60.0 x 73.5 x 7.50 mm

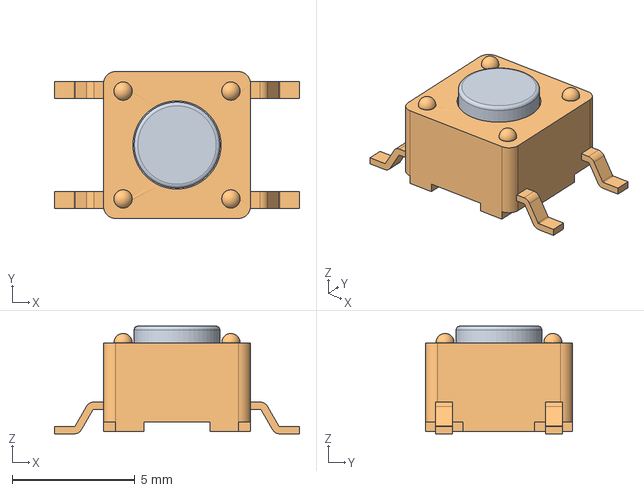
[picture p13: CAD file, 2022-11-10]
Hardware/LibreCAL/KiCad3DFiles/TactileSwitch4_3mm.stp
10.0 x 6.00 x 4.40 mm

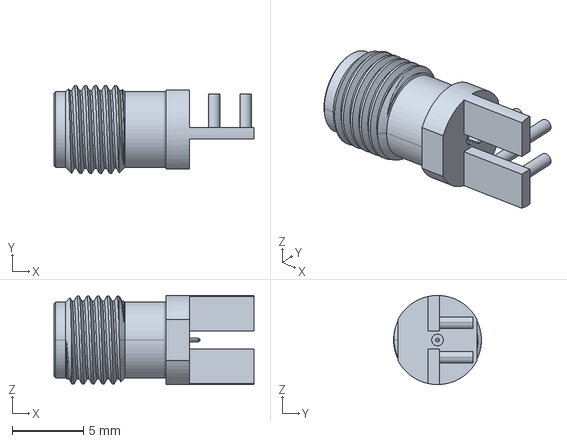
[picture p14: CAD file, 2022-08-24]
Hardware/LibreCAL/KiCad3DFiles/901-10510-2.stp
14.1 x 6.19 x 6.27 mm

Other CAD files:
Hardware/TopCover_2D_TextLaserEngraving.FCStd
Hardware/TopCover_2D_TextLaserEngraving.dxf

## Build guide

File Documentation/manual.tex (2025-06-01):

\documentclass[a4paper,11pt]{article}

\usepackage[utf8]{inputenc}
\usepackage[T1]{fontenc} % LY1 also works
\usepackage[margin=1in]{geometry}

%% Font settings suggested by fbb documentation.
\usepackage{textcomp} % to get the right copyright, etc.
\usepackage[lining,tabular]{fbb} % so math uses tabular lining figures
\usepackage[scaled=.95,type1]{cabin} % sans serif in style of Gill Sans
\usepackage[varqu,varl]{zi4}% inconsolata typewriter
\useosf % change normal text to use proportional oldstyle figures
%\usetosf would provide tabular oldstyle figures in text

\usepackage{microtype}
\usepackage{siunitx}
\DeclareSIUnit{\belmilliwatt}{Bm}
\DeclareSIUnit{\dBm}{\deci\belmilliwatt}
\sisetup{range-phrase=--, range-units=single, binary-units = true}
\usepackage{graphicx}
\usepackage{tikz}
\usepackage{svg}
\usetikzlibrary{arrows, shadows}
\tikzset{%
  cascaded/.style = {%
    general shadow = {%
      shadow scale = 1,
      shadow xshift = -1ex,
      shadow yshift = 1ex,
      draw,
      thick,
      fill = white},
    general shadow = {%
      shadow scale = 1,
      shadow xshift = -.5ex,
      shadow yshift = .5ex,
      draw,
      thick,
      fill = white},
    fill = white, 
    draw,
    thick,
    minimum width = 1.5cm,
    minimum height = 2cm}}
    
\usepackage{enumitem}
\setitemize{noitemsep,topsep=0pt,parsep=0pt,partopsep=0pt}
\setlist{leftmargin=*}
\usepackage{listings}
\definecolor{darkgreen}{RGB}{0,140,0}
\lstset{
	basicstyle=\ttfamily,
	frame=single,
	breaklines=true,
	morecomment=[l][\color{darkgreen}]{\#},
}
\usepackage[os=win]{menukeys}
\renewmenumacro{\keys}[+]{shadowedroundedkeys}

\usepackage{booktabs,caption}
\usepackage[flushleft]{threeparttable}
\newcolumntype{L}[1]{>{\raggedright\let\newline\\\arraybackslash\hspace{0pt}}m{#1}}
\newcolumntype{C}[1]{>{\centering\let\newline\\\arraybackslash\hspace{0pt}}m{#1}}
\newcolumntype{R}[1]{>{\raggedleft\let\newline\\\arraybackslash\hspace{0pt}}m{#1}}
\usepackage{tabularx} 

\usepackage{stackengine}
\usepackage{scalerel}
\usepackage{xcolor,mdframed}

\newcommand\danger[1][5ex]{%
  \renewcommand\stacktype{L}%
  \scaleto{\stackon[1.3pt]{\color{red}$\triangle$}{\tiny !}}{#1}%
}

\newenvironment{important}[1][]{%
   \begin{mdframed}[%
      backgroundcolor={red!15}, hidealllines=true,
      skipabove=0.7\baselineskip, skipbelow=0.7\baselineskip,
      splitbottomskip=2pt, splittopskip=4pt, #1]%
   \makebox[0pt]{% ignore the withd of !
      \smash{% ignor the height of !
         %\fontsize{32pt}{32pt}\selectfont% make the ! bigger
         \hspace*{-45pt}% move ! to the left
         \raisebox{-5pt}{% move ! up a little
            {\danger}% type the bold red !
         }%
      }%
   }%
}{\end{mdframed}}

\newcommand\info[1][5ex]{%
  \renewcommand\stacktype{L}%
  \scaleto{\stackon[1.2pt]{\color{blue}$\bigcirc$}{\raisebox{-1.5pt}{\small i}}}{#1}%
}

\newenvironment{information}[1][]{%
   \begin{mdframed}[%
      backgroundcolor={blue!15}, hidealllines=true,
      skipabove=0.7\baselineskip, skipbelow=0.7\baselineskip,
      splitbottomskip=2pt, splittopskip=4pt, #1]%
   \makebox[0pt]{% ignore the withd of !
      \smash{% ignor the height of !
         %\fontsize{32pt}{32pt}\selectfont% make the ! bigger
         \hspace*{-45pt}% move ! to the left
         \raisebox{-5pt}{% move ! up a little
            {\info}% type the bold red !
         }%
      }%
   }%
}{\end{mdframed}}

\usepackage{makecell}
\usepackage{hyperref}
\newcommand{\dev}{LibreCAL}

\newcommand{\screenshot}[2]{\begin{center}

\end{center}}

\title{\dev{} User Manual}
%\author{Jan Käberich (\url{j.kaeberich@gmx.de})}
\begin{document}
\maketitle

\setcounter{tocdepth}{3}
\tableofcontents
\clearpage

\section{Overview}

\begin{tikzpicture}
\begin{scope}[xshift=1.5cm]
    \node[anchor=south west,inner sep=0] (image) at (0,0) {};
    \begin{scope}[x={(image.south east)},y={(image.north west)}]
		\node [anchor=east, align=center] (port1) at (-0.2,0.95) {Port 1};
		\node [anchor=west, align=center] (port2) at (1.2,0.95) {Port 2};
		\node [anchor=east, align=center] (port3) at (-0.2,0.7) {Port 3};
		\node [anchor=west, align=center] (port4) at (1.2,0.7) {Port 4};
		\node [anchor=west, align=center] (leds1) at (-0.3,0.3) {LEDs\\ \footnotesize Left-to-right:\\ \footnotesize Power\\ \footnotesize Ready\\ \footnotesize Wait\\ \footnotesize Port 1\\ \footnotesize Port 2\\ \footnotesize Port 3\\ \footnotesize Port 4};
		\node [anchor=north, align=center] (usb) at (0.5,-0.2) {USB};
		\node [anchor=north, align=center] (portsel) at (-0.25,-0.2) {Port Select};
		\node [anchor=north, align=center] (bootsel) at (0.25,-0.2) {Bootsel};
		\node [anchor=north, align=center] (functionsel) at (1,-0.2) {Function Select};
		\node [anchor=east, align=center] (leds2) at (1.3,0.3) {LEDs\\ \footnotesize Left-to-right:\\ \footnotesize Open\\ \footnotesize Short\\ \footnotesize Load\\ \footnotesize Through};

        \draw [-*, ultra thick, gray] (port1) to[] (0.02,0.85);
        \draw [-*, ultra thick, gray] (port2) to[] (0.98,0.85);
        \draw [-*, ultra thick, gray] (port3) to[] (0.02,0.64);
        \draw [-*, ultra thick, gray] (port4) to[] (0.98,0.64);
        \draw [-*, ultra thick, gray] (usb) to[] (0.5,0.02);
        \draw [-*, ultra thick, gray] (portsel) to[] (0.28,0.15);
        \draw [-*, ultra thick, gray] (bootsel) to[] (0.378,0.156);
        \draw [-*, ultra thick, gray] (functionsel) to[] (0.725,0.153);
        \draw [-*, ultra thick, gray] (leds1) to[] (0.18,0.36);
        \draw [-*, ultra thick, gray] (leds2) to[] (0.82,0.36);
    \end{scope}
\end{scope}
\end{tikzpicture}%

\subsection{Ports}
The four calibration ports use SMA connectors.

\subsection{Heater}
The critical components are kept at a constant temperature with a resistive heater. The heater is working whenever the \dev{} is powered and can not be disabled.

\subsection{Buttons}
There are three buttons available:
\begin{itemize}
\item \textbf{Port Select:} Selects the port when manually changing calibration standards.
\item \textbf{Bootsel:} When pressed while applying power, the \dev{} enters the bootloader mode for firmware updates.
\item \textbf{Function Select:} Selects the standard when manually changing calibration standards.
\end{itemize}

\subsection{LEDs}
\begin{itemize}
\item \textbf{Power:} Always on.
\item \textbf{Ready:} On or blinking when the heater has reached the required temperature.
\item \textbf{Wait:} On or blinking while temperature has not yet settled. Do not make calibration measurements while this LED is on.
\item \textbf{Port[1-4]:}
\begin{itemize}
\item \textbf{While manually changing settings:} The LED corresponding to the currently selected port flashes.
\item \textbf{Any other time:} LED is on for any port that is active (has a standard enabled)
\end{itemize}
\item \textbf{Open,Short,Load,Through:}
\begin{itemize}
\item \textbf{While manually changing settings:} The LEDs show the selected standard of the currently selected port.
\item \textbf{Any other time:} Each LED is on if the corresponding standard is used at any port.
\end{itemize}
\end{itemize}

\subsection{USB}
The \dev{} uses a USB-C connector as the power supply and for data transmission. It requires \SI{5}{\volt} and draws up to \SI{0.5}{\ampere} of current.

\section{Firmware Update}
The \dev{} uses the RP2040 microcontroller and its USB bootloader. To enter the bootloader, hold the "Bootsel" button pressed down while applying power. The \dev{} will show up as a mass storage device. Copy the firmware file to the mass storage and wait for \dev{} to reboot.

\section{Manual control}
The \dev{} is most useful when automatically controlled by the LibreVNA-GUI or a script. However, it is also possible to configure the calibration standards for each port manually using the "Port Select" and "Function Select" buttons.

\begin{enumerate}
\item Press "Port Select" to start the manual mode. The LED of the selected port will start flashing and if the port has a calibration standard defined, the corresponding LED will also light up.
\item Press "Port Select" to switch the port you want to change.
\item Press "Function Select" to change the calibration standard of the selected port.
\item After not pressing any button for 3 seconds, the \dev{} will leave manual mode. Changes made in the manual mode are persistent until they are overwritten through USB or a reboot is performed.
\end{enumerate}

\section{USB control}
Please see the SCPI API\footnote{\url{https://github.com/jankae/LibreCAL/blob/main/Documentation/SCPI_API.pdf}} for detailed information.

\section{Calibration coefficients}
For accurate calibrations, the \dev{} provides the calibration coefficients for all calibration standards. There is one default set of calibration coefficients ("FACTORY") as well as the option to add your own (useful if you have additional components permanently mounted to the \dev{} such as port savers).

Each coefficient set consists of a name and the calibration coefficients (as S-parameters) for every reflection and transmission standard. In total there are 18 different coefficients for every coefficient set:
\begin{itemize}
\item P1\_OPEN
\item P1\_SHORT
\item P1\_LOAD
\item P2\_OPEN
\item P2\_SHORT
\item P2\_LOAD
\item P3\_OPEN
\item P3\_SHORT
\item P3\_LOAD
\item P4\_OPEN
\item P4\_SHORT
\item P4\_LOAD
\item P12\_THROUGH
\item P13\_THROUGH
\item P14\_THROUGH
\item P23\_THROUGH
\item P24\_THROUGH
\item P34\_THROUGH
\end{itemize}

\paragraph{There are three ways to read calibration coefficients:}
\begin{itemize}
\item Read them through the SCPI API.
\item Use the \dev{}-GUI to extract them and export them as touchstone files (uses the SCPI API internally).
\item Read the touchstone files directly from the \dev{}.
\end{itemize}

For the last option, the \dev{} shows up as two mass storage devices: "\mbox{LIBRECAL\_R}" and "\mbox{LIBRECAL\_R}W". \mbox{LIBRECAL\_R} is read-only and is reserved for the factory calibration coefficient set. User-defined calibration coefficient sets can be found in \mbox{LIBRECAL\_R}W. 

\subsection{Adding user-defined coefficients}
User-defined calibration coefficient sets can be added in the \mbox{LIBRECAL\_R}W mass storage device. Each coefficient set must reside in its own folder. The name of the folder will be used as the coefficient set name and the folder must be in the root directory of \mbox{LIBRECAL\_R}W.

The coefficient set folder should include all required coefficients as touchstone files, file naming must follow these names:
\begin{itemize}
\item P1\_OPEN.s1p
\item P1\_SHORT.s1p
\item P1\_LOAD.s1p
\item P2\_OPEN.s1p
\item P2\_SHORT.s1p
\item P2\_LOAD.s1p
\item P3\_OPEN.s1p
\item P3\_SHORT.s1p
\item P3\_LOAD.s1p
\item P4\_OPEN.s1p
\item P4\_SHORT.s1p
\item P4\_LOAD.s1p
\item P12\_THROUGH.s2p
\item P13\_THROUGH.s2p
\item P14\_THROUGH.s2p
\item P23\_THROUGH.s2p
\item P24\_THROUGH.s2p
\item P34\_THROUGH.s2p
\end{itemize}

\begin{information}
Files may be omitted if the corresponding ports are never going to be used (e.g. when only using two ports of the \dev{}).
\end{information}

\begin{important}
The touchstone format of all files must use the following settings:
\begin{itemize}
\item Frequency in GHz
\item S-parameters
\item S-parameter data in real/imag form
\item 50 Ohm reference impedance
\end{itemize}
\end{important}
In other words, the touchstone option line must be
\begin{lstlisting}
# GHz S RI R 50.0
\end{lstlisting}
If the touchstone file uses any other format, it must either be converted before copying it to \mbox{LIBRECAL\_R}W or the \dev{}-GUI must be used to import the touchstone file and create the coefficient from that.

\section{USB modes}
The \dev{} is primarely used to calibrate the LibreVNA with the functions and protocol described in this document. VNAs from other manufacturers usually have their own proprietary protocol and will not detect the \dev{}. However, for some VNAs and protocols it is possible to reverse engineer their functions and add an emulation mode to the \dev{}. That way, it can be used to automatically calibrate these VNAs as well.

To enable an emulation mode, the calibration coefficients must be stored on the LibreCAL in the reverse engineered format. This can be achieved with the supplied scripts\footnote{\url{https://github.com/jankae/LibreCAL/blob/main/Software/Scripts}}.

When the \dev{} starts and detects this data, it will automatically enter the corresponding emulation mode. This is indicated by a blinking wait or ready LED (which would be constantly on in the default mode). When an emulation mode is active, the \dev{} will not be recognized by the \dev{}-GUI or LibreVNA-GUI anymore. You can press and hold the function button while applying power to force the \dev{} into its default mode.

Currently emulation modes for the following VNAs from other manufacturers are supported:
\begin{itemize}
\item Siglent SVA1000X series
\item Siglent SNA5000A series
\end{itemize}
If you have access to electronic calibration modules from unsupported manufacturers and the capability to reverse engineer their protocols please get in touch to extend this list.

\end{document}

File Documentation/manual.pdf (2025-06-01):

## LibreCAL User Manual

June 1, 2025

## Contents

1 Overview | 2
2 Firmware Update | 3
3 Manual control | 3
4 USB control | 3
5 Calibration coefficients | 3
6 USB modes | 5

## 1 Overview

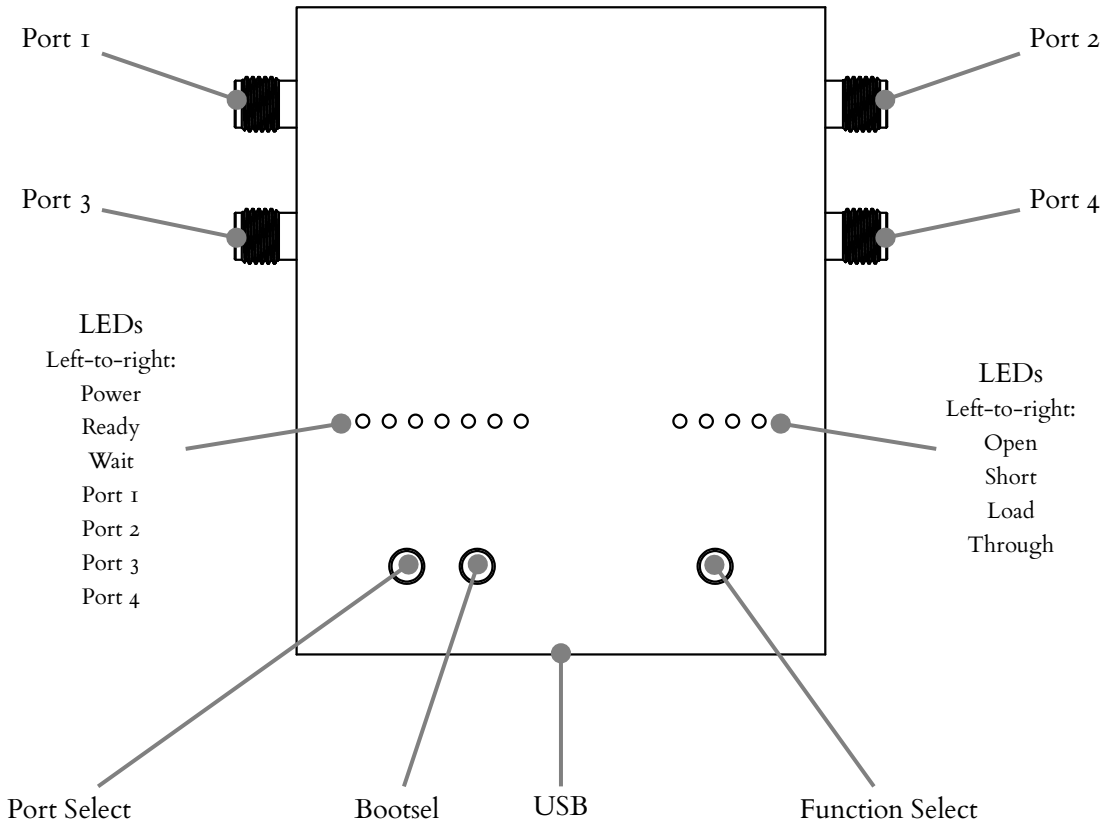
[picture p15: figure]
Port 1; Port 2; Port 3; Port 4; LEDs; Left-to-right:; Power Ready; Wait Port 1; Port Select; Bootsel; USB; Function Select; Open Short; Load; Through

### 1.1 Ports

The four calibration ports use SMA connectors.

### 1.2 Heater

The critical components are kept at a constant temperature with a resistive heater. The heater is working whenever the LibreCAL is powered and can not be disabled.

### 1.3 Buttons

There are three buttons available:
- Port Select: Selects the port when manually changing calibration standards.
- Bootsel: When pressed while applying power, the LibreCAL enters the bootloader mode for firmware updates.
- Function Select: Selects the standard when manually changing calibration standards.

### 1.4 LEDs

- Power: Always on.
- Ready: On or blinking when the heater has reached the required temperature.
- Wait: On or blinking while temperature has not yet settled. Do not make calibration measurements while this LED is on.
- Port[1-4]:

– While manually changing settings: The LED corresponding to the currently selected port flashes.
– Any other time: LED is on for any port that is active (has a standard enabled)
- Open,Short,Load,Through:
– While manually changing settings: The LEDs show the selected standard of the currently selected port.
– Any other time: Each LED is on if the corresponding standard is used at any port.

### 1.5 USB

The LibreCAL uses a USB-C connector as the power supply and for data transmission. It requires 5 V and draws up to 0.5 A of current.

## 2 Firmware Update

The LibreCAL uses the RP2040 microcontroller and its USB bootloader. To enter the bootloader, hold the "Bootsel" button pressed down while applying power. The LibreCAL will show up as a mass storage device. Copy the firmware file to the mass storage and wait for LibreCAL to reboot.

## 3 Manual control

The LibreCAL is most useful when automatically controlled by the LibreVNA-GUI or a script. However, it is also possible to configure the calibration standards for each port manually using the "Port Select" and "Function Select" buttons.

1. Press "Port Select" to start the manual mode. The LED of the selected port will start flashing and if the port has a calibration standard defined, the corresponding LED will also light up.
2. Press "Port Select" to switch the port you want to change.
3. Press "Function Select" to change the calibration standard of the selected port.
4. After not pressing any button for 3 seconds, the LibreCAL will leave manual mode. Changes made in the manual mode are persistent until they are overwritten through USB or a reboot is performed.

## 4 USB control

Please see the SCPI API¹
for detailed information.

## 5 Calibration coefficients

For accurate calibrations, the LibreCAL provides the calibration coefficients for all calibration standards. There is one default set of calibration coefficients ("FACTORY") as well as the option to add your own (useful if you have additional components permanently mounted to the LibreCAL such as port savers).
Each coefficient set consists of a name and the calibration coefficients (as S-parameters) for every reflection and transmission standard. In total there are 18 different coefficients for every coefficient set:

1
https://github.com/jankae/LibreCAL/blob/main/Documentation/SCPI_API.pdf

- P1_OPEN
- P1_SHORT
- P1_LOAD
- P2_OPEN
- P2_SHORT
- P2_LOAD
- P3_OPEN
- P3_SHORT
- P3_LOAD
- P4_OPEN
- P4_SHORT
- P4_LOAD
- P12_THROUGH
- P13_THROUGH
- P14_THROUGH
- P23_THROUGH
- P24_THROUGH
- P34_THROUGH

There are three ways to read calibration coefficients:
- Read them through the SCPI API.
- Use the LibreCAL-GUI to extract them and export them as touchstone files (uses the SCPI API internally).
- Read the touchstone files directly from the LibreCAL.
For the last option, the LibreCAL shows up as two mass storage devices: "LIBRECAL_R" and "LIBRECAL_RW". LIBRECAL_R is read-only and is reserved for the factory calibration coefficient set. User-defined calibration coefficient sets can be found in LIBRECAL_RW.

### 5.1 Adding user-defined coefficients

User-defined calibration coefficient sets can be added in the LIBRECAL_RW mass storage device. Each coefficient set must reside in its own folder. The name of the folder will be used as the coefficient set name and the folder must be in the root directory of LIBRECAL_RW.
The coefficient set folder should include all required coefficients as touchstone files, file naming must follow these names:
- P1_OPEN.s1p
- P1_SHORT.s1p
- P1_LOAD.s1p
- P2_OPEN.s1p
- P2_SHORT.s1p
- P2_LOAD.s1p
- P3_OPEN.s1p
- P3_SHORT.s1p
- P3_LOAD.s1p
- P4_OPEN.s1p
- P4_SHORT.s1p
- P4_LOAD.s1p
- P12_THROUGH.s2p
- P13_THROUGH.s2p
- P14_THROUGH.s2p
- P23_THROUGH.s2p

- P24_THROUGH.s2p
- P34_THROUGH.s2p
⃝i
Files may be omitted if the corresponding ports are never going to be used (e.g. when only using two ports of the LibreCAL).

△! The touchstone format of all files must use the following settings: • Frequency in GHz • S-parameters • S-parameter data in real/imag form • 50 Ohm reference impedance In other words, the touchstone option line must be # GHz S RI R 50.0 If the touchstone file uses any other format, it must either be converted before copying it to LIBRECAL_RW or the LibreCAL-GUI must be used to import the touchstone file and create the coefficient from that.

## 6 USB modes

| The LibreCAL is primarely used to calibrate the LibreVNA with the functions and protocol described in this document. VNAs from other manufacturers usually have their own proprietary protocol and will not detect the LibreCAL. However, for some VNAs and protocols it is possible to reverse engineer their functions and add an emulation mode to the LibreCAL. That way, it can be used to automatically calibrate these VNAs as well. To enable an emulation mode, the calibration coefficients must be stored on the LibreCAL in the reverse engineered format. This can be achieved with the supplied scripts²
| When the LibreCAL starts and detects this data, it will automatically enter the corresponding emulation mode. This is indicated by a blinking wait or ready LED (which would be constantly on in the default mode). When an emulation mode is active, the LibreCAL will not be recognized by the LibreCAL-GUI or LibreVNA-GUI anymore. You can press and hold the function button while applying power to force the LibreCAL into its default mode. Currently emulation modes for the following VNAs from other manufacturers are supported: • Siglent SVA1000X series • Siglent SNA5000A series If you have access to electronic calibration modules from unsupported manufacturers and the capability to reverse engineer their protocols please get in touch to extend this list.

2
https://github.com/jankae/LibreCAL/blob/main/Software/Scripts

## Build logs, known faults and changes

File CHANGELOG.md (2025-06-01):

# Changelog

## v0.3.0

- add emulation mode for use with Siglent VNAs
- update to Pico SDK 2.1.1 (improves USB stability)
- fix intermittent deadlock during USB communication
- fix timing of CS pin to flash chip which can lead to failed writes
- accept \\r\\n and \\n as line endings for SCPI commands 

## v0.2.3

- minor error recovery improvements for USB connection problems
- add option to write factory coefficients (either from file or from server)
- format partition when deleting factory coefficients

## v0.2.2

- Replace forward slahes (`/`) in the serial number with `_` to fix factory calibration problems

## v0.2.1

First public release

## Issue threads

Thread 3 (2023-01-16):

Log RF switch cycle count

bvernoux, 2023-01-16:
A good feature could be to log RF switch cycle count for each switch

jankae, 2023-01-16:
What would be the reason for that? They are solid state switches, unlike relays they don't get "used up" by switching them.

Closed 2023-01-23.

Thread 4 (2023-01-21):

Questions about Manual control use case with Port Select Port1/2/3/4 & Function Select Through

bvernoux, 2023-01-21:
Today it is not very clear how work the Manual control towards Through Function selection and Port Select Port1/2/3/4 (checked also in latest documentation https://github.com/jankae/LibreCAL/blob/main/Documentation/manual.pdf October 3, 2022)
If I want to do manual calibration all is clear for Port Select of PORT1/2/3/4 and Function Select for Open/Short/Load
But it is not clear for Through especially as Through requires to know Source & Destination Port and it is not clear how we can select that in Manual control.

Could you clarify how it works with Manual control ?
Case Port1 & Through:
- I have Port Select => Port1
- I have Function Select => Through
- Does it imply Through is between Port1 and Port2 ? (I suspect it is default case to be confirmed)
- How does it is displayed with LEDs ?
  - Does Both Port1 & Port2 LEDs are blinking or fix... to clearly show that the Through will be between those 2 ports ?

Case Port2 & Through:
- I have Port Select => Port2
- I have Function Select => Through
- Does it imply Through is between Port2 and Port1 ? (I suspect it is default case to be confirmed)
- How does it is displayed with LEDs ?
  - Does Both Port1 & Port2 LEDs are blinking or fix... to clearly show that the Through will be between those 2 ports ?

Case Port3 & Through:
- I have Port Select => Port3
- I have Function Select => Through
- Does it imply Through is between Port3 and Port4 ? (I suspect it is default case to be confirmed)
- How does it is displayed with LEDs ?
  - Does Both Port3 & Port4 LEDs are blinking or fix... to clearly show that the Through will be between those 2 ports ?

Case Port4 & Through:
- I have Port Select => Port4
- I have Function Select => Through
- Does it imply Through is between Port4 and Port3 ? (I suspect it is default case to be confirmed)
- How does it is displayed with LEDs ?
  - Does Both Port3 & Port4 LEDs are blinking or fix... to clearly show that the Through will be between those 2 ports ?

Now the question does it is possible to select the Port Source & Port Destination for Through in Manual control ?
See following cases:
- Port1 => Through => Port3
- Port1 => Through => Port4
- Port2 => Through => Port3
- Port2 => Through => Port4
It can be interesting to use the eCal as a Switch or to calibrate manually 4 Ports VNA

jankae, 2023-01-21:
> Now the question does it is possible to select the Port Source & Port Destination for Through in Manual control ?

Yes, just set the two ports you wish to connect both to the through standard. As long as only one port is set to through, no connection will be made.

> How does it is displayed with LEDs ?

While in manual mode: the LED of the selected port is blinking and if the port is currently set to a standard, the corresponding standard LED is on.

While in normal operating mode (assuming a through connection between two ports and no other configured standards): through LED is on and the port LEDs of both ports as well.

> Port1 => Through => Port3

1. set port 1 to through
2. Set port 3 to through

You can also have two through connections at the same time, as long as there is no overlap between the ports (e.g. 1<->3 and 2<->4). Throughs are connected in the order they are created. So for this example:

1. Set port 1 to through (no actual switching yet)
2. Set port 3 to through (completes the connection between port 1 and 3)
3. Set port 2 to through (no actual switching yet)
4. Set port 4 to through (completes the connection between port 2 and 4)

bvernoux, 2023-01-21:
Thanks a lot for the clarification

Closed 2023-01-21.

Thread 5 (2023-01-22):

Is it possible to make a duplicate firmware for LibreCal in case of replacing pe426462 with pe42482?

YuryW, 2023-01-22:
Hi Jankae,
Judging by the layout of the printed circuit board, there will be physical changes only in the fact that in the case of the truth table Off, all switches will not be disabled, since V4 is connected to GND without reworking the board, and RFC needs to be switched to the RF1 output, which remains not connected anywhere.
The changes are as follows - instead of RF4 and RF6 in pe426462, you now need to switch RF6 and RF8 in pe42482, respectively. In the truth tables in the new version, it will look like this:

Connection P1V1 | P1V2 | P1V3 | P2V1 | P2V2 | P2V3 | P3V1 | P3V2 | P3V3 | P4V1 | P4V2 | P4V3
Through_12     0         1          0         1           0         1         X         X          X         X          X         X
Through_13     1         0          1         X           X         X         0         0          1         X          X         X
Through_14    0         0          1         X           X         X         X        X          X         0          0         1
Through_23     X         X         X         0           1         0          0         1          0         X          X         X
Through_24     X         X         X         0           0         1          X         X         X         1          0         1
Through_34     X         X         X         X           X         X         1         0          1         0          1         0

Instead of RF4 (011) now RF6 (101).

Connection | V1 | V2 | V3 |
Load               1     1     1  (instead of RF6 (101) now RF8 (111) )
Off                  0     0     0  (instead of disabling all switches (110) now switching RFC to RF1 (000) ).

Best regards.

jankae, 2023-01-23:
It is technically possible but I believe it would cause more confusion than it would solve problems:
- There are no plans to produce a version with PE426482
- If there were two different versions, the user needs to flash the correct firmware update (the hardware is unable to determine whether a PE4264**6**2 or PE4264**8**2 is populated). If the user flashes the wrong firmware by mistake, some functions would not work properly

If you yourself are building a version with the PE4264**8**2, I suggest you fork the repository and do the changes yourself for your special version of the device. You won't even have to set up the toolchain, just pushing the changes in your fork should get you a compiled firmware.

YuryW, 2023-01-23:
> I suggest you fork the repository and do the changes yourself for your special version of the device.

Hi Jankae,
Thanks a lot for developing LibreVNA and LibreCal. But I don’t have enough knowledge yet to do it myself or work fully with github. The main thing is that you have confirmed that such a replacement is, in principle, possible. Not in vain wasted time on datasheets. Perhaps this will someday help someone in the case when they assemble the device themselves or for some reason replace the switch chips. We close the question.
Best wishes.

Closed 2023-01-23.

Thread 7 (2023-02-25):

Update LibreCAL-GUI & firmware version to v0.1.1

bvernoux, 2023-02-25:
I see you have pushed some precious fixes / improvements in latest LibreCAL-GUI & LibreCAL firmware commit from Jan 23 & 24, 2023 but unfortunately the LibreCAL-GUI & firmware version have not changed and they are still v0.1.0
It will be great to update them to 0.1.1 to avoid confusion with previous firmware/LibreCAL-GUI ...

LibreCAL-GUI change:
- https://github.com/jankae/LibreCAL/commit/1f512ad95bb842af440e329ada94a683d7dc7734 "Fix expected *IDN? response"

LibreCAL firmware changes:
- https://github.com/jankae/LibreCAL/commit/2410e343ae689072236260943ba30a07f0889d49 "SCPI API adjustments"
- https://github.com/jankae/LibreCAL/commit/b41dedec7b12fbbe7c6b08205d45196db9a4527e "Allow higher I term for temperature control in colder environments"

Especially the firmware change https://github.com/jankae/LibreCAL/commit/b41dedec7b12fbbe7c6b08205d45196db9a4527e
- With that change it improve a lot the time to reach the 35°C temperature when the board is quite cold <= 20°C (or even outside case)

jankae, 2023-02-25:
I don't really intend to increase the version number for small changes in commits. I will however increase the version number for every release. Since this project does not have any releases yet (still in prototype stage), it is still at the starting version number of 0.1.0

The LibreCAL-GUI also shows the commit hash when checking the version, so there shouldn't be any confusion there. And if you have a different firmware than from a official release you must have either compiled it yourself or downloaded it from the action tab of the repository - in both cases I assume you know enough about what you are doing and specifically want a development version of the firmware that hasn't been released yet (and doesn't have a unique version number).

Closed 2023-02-25.

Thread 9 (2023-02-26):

Add SCPI command to READ/WRITE Date & Time

bvernoux, 2023-02-26:
A good improvement will be to add a SCPI command to retrieve and use PC date/time
This will be a great addition to have correct date/time on files created for example to create *.snp files for calibration (Factory or users)
As today we see file date time of 2020/01/01
It seems possible to use internal RTC for that
https://www.raspberrypi.com/documentation/pico-sdk/hardware.html#hardware_rtc
http://elm-chan.org/fsw/ff/doc/fattime.html

Even if after each power off of the LibreCAL the Date/Time will be lost the idea it to update it each time it is connected to the PC when required with the SCPI API

Proposal SCPI command `:DATE_TIME` with parameter format `YYYY/MM/DD HH:MM:SS UTC offset` ([UTC offset](https://en.wikipedia.org/wiki/UTC_offset))
- Example to set Date & Time over SCPI: `:DATE_TIME 2023/03/01 10:05:48 UTC+01:00` for France Time
- Example to get Date & Time over SCPI: `:DATE_TIME?` will return for example `2023/03/01 10:05:48 UTC+01:00`

bvernoux, 2023-03-14:
@jankae Are you ok for that proposal ? as I plan to implement it (and do a PR after)

bvernoux, 2023-03-22:
I'm waiting your feedback on my PR https://github.com/jankae/LibreCAL/pull/15

Closed 2023-03-28.

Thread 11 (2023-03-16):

LibreCAL EmbeddedFirmware USB issue with pico-sdk 1.5 (LibreCAL-GUI impossible to connect)

bvernoux, 2023-03-16:
With recent build of the firmware even on old code the LibreCAL GUI freeze during connection and USB connection is lost after few seconds.
Issue description on recent Firmware built:
- The issue can be clearly seen when launching official LibreCAL GUI on Windows10 [APP](https://github.com/jankae/LibreCAL/suites/10538920932/artifacts/523918071) when it connect to the LibreCAL it freeze and the USB connection is lost, so it is impossible to use the firmware with LibreCAL GUI on Windows10 (potentially also LibreCAL GUI for Linux to be tested)

Investigation comparison with working/reference LibreCAL Firmware:
- I have rebuilt the firmware with original source code from https://github.com/jankae/LibreCAL/tree/main/Software/LibreCAL (https://github.com/jankae/LibreCAL/commit/1f512ad95bb842af440e329ada94a683d7dc7734) and it is the same LibreCAL GUI on Windows10 freeze (it report 0 VNA port...) then USB connection is lost (It seems it is related to USB error/timeout), I cannot reproduce that issue when sending SCPI commands with Python3 script.
    - To build the Firmware I'm using Ubuntu 20.04 LTS and I'm following the steps done with the https://github.com/jankae/LibreCAL/blob/main/.github/workflows/Build.yml#L155 A strange things is my generated LibreCAL.uf2 have not the same size 368640 bytes
      - Reference working LibreCAL firmware is here https://github.com/jankae/LibreCAL/actions/runs/3991398790 (EmbeddedFirmware--v0.1.0-2023-01-23-23-14-27.zip / LibreCAL.uf2) with size 366592 bytes using git commit https://github.com/jankae/LibreCAL/commit/1f512ad95bb842af440e329ada94a683d7dc7734
        - Wireshark USB OK capture for reference [LibreCAL-GUI_Windows10_EmbeddedFirmware-v0.1.0-2023-01-23-23-14-27_USB_OK_pcapng.zip](https://github.com/jankae/LibreCAL/files/10998967/LibreCAL-GUI_Windows10_EmbeddedFirmware-v0.1.0-2023-01-23-23-14-27_USB_OK_pcapng.zip)

      - Build version done later 18 Feb 2022 the Firmware is built exactly with same steps and same source code but it is different and have issue see **Issue description on recent Firmware built** (like my own built version) see built version here https://github.com/bvernoux/LibreCAL/actions/runs/4210635144 (EmbeddedFirmware--v0.1.0-2023-02-18-09-54-00.zip) with exactly same git commit https://github.com/bvernoux/LibreCAL/commit/1f512ad95bb842af440e329ada94a683d7dc7734 (but build in February) size 368640 bytes this firmware have same issue as in Issue description.
        - Wireshark USB KO capture with SCPI FIRMWARE & IDN command with no answer [LibreCAL-GUI_Windows10_EmbeddedFirmware-v0.1.0-2023-02-18-09-54-00_USB_KO_pcapng.zip](https://github.com/jankae/LibreCAL/files/10998991/LibreCAL-GUI_Windows10_EmbeddedFirmware-v0.1.0-2023-02-18-09-54-00_USB_KO_pcapng.zip)

jankae, 2023-03-17:
So you are suspecting that something in the toolchain has changed and it breaks? Not sure if I understood everything correctly...
I'll try to replicate that.

bvernoux, 2023-03-17:
Could you just try to force rebuild to check the binary/uf2 output (on same actual code) ?
Do you reproduce the issue described (with latest pico-sdk) on your side too ?

jankae, 2023-03-17:
I didn't compare the binaries but with the 1.5.0 SDK I could reproduce the same problem

bvernoux, 2023-03-18:
I confirm that using pico-sdk 1.4.0 (sudo git -C /opt/pico-sdk checkout 1.4.0) fix the issue
For information on my side I have tried several intermediate pico-sdk version without success (with same USB issue) and I have not identified the commit which break the USB...
pico-sdk commit tested with USB broken:
- sudo git -C /opt/pico-sdk checkout -b c578422528d91da8f9ae80b8446889b6e3224d26
  - This corresponds to pico-sdk commit on **24 Jan 2023** Remove PLL postdiv assert. Fixes https://github.com/raspberrypi/pico-sdk/issues/1047 (https://github.com/raspberrypi/pico-sdk/pull/1189)

- sudo git -C /opt/pico-sdk checkout -b 8b8778c59b3db9fb201172d0837b5dac1cf8065e
  - This corresponds to pico-sdk commit on **20 Jan 2023** compile issue seems to have snuck thru (https://github.com/raspberrypi/pico-sdk/pull/1184)

- sudo git -C /opt/pico-sdk checkout -b 488bd66eb3977bb79d4e5891071a67437180dfc0
  - This corresponds to pico-sdk commit on **9 Jan 2023** Fix conflicting C++ linkage for pico_lwip panic() (https://github.com/raspberrypi/pico-sdk/pull/1167)

So it will be interesting to understand what happen (and which commit break the USB) between working USB on pico-sdk 14.0 up to pico-sdk 1.5.0 with non working USB.

bvernoux, 2024-02-12:
A new warning about that issue as I have discovered that if building LibreCAL with pico-sdk 1.4.0 on Ubuntu 22.04 LTS (instead of Ubuntu 20.04 LTS) produce broken Firmware which seems to be related to the GCC ARM of Ubuntu 22.04 LTS...

jankae, 2024-09-25:
It has been a while but I finally updated the SDK to the newest version (2.0.0 at the moment). Still not sure what the issue was with 1.5.0 but so far I have not detected any problems with 2.0.0

Closed 2024-09-25.

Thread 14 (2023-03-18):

LibreCAL Embedded Firmware improvement limit calibration points per file

bvernoux, 2023-03-18:
My proposal for LibreCAL Embedded Firmware is to add a limit of 10001 or 5001 calibration points per *.snp file.
That limit shall allow in worst case to create all 4 ports calibration files with enough space in flash (limited to 748KB today).

Actual limitation with default 16Mbits (2MBytes) SPI Flash for calibration:
- After some internal tests with actual default SPI Flash 16Mbits (2MBytes) with 1MBytes for each partition (LIBRECAL_R & LIBRECAL_RW) we do not have enough space to do a full calibration for the 4 ports with 1601pts and 100 comments per snp file.
  - With my test full 4 ports calibration create 18x snp files which requires a total of 1369626 bytes about 1.3MBytes when there is only 748KB available, so that means we are limited to max 801pts per *.snp file
  - For information with 1601 pts each s1p file size is about 47KB and s2p files are 131KB.

jankae, 2023-03-26:
I would rather not restrict the number of points to a specific value. Someone might want more points but e.g. only store coefficients for ports 1 and 2 (in case of a two port VNA). What I would much prefer is using a bigger SPI Flash. The software already supports up to 128Mbits (with the W25Q128JV). Even larger devices could be added in the future but I believe they would require a new layout (using a different package).

bvernoux, 2023-03-26:
Yes let's keep it like that, I have tested that in worst case during creation of the snp file if there is not enough space in SPI Flash that will return an error

Closed 2023-03-26.

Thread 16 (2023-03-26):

Expensive SMA connectors

sebgus, 2023-03-26:
Considering this design only goes up to 6 GHz, why not use cheaper SMA connectors?

E.g. the Linx CONSMA003.062 (18 GHz, €4) vs Amphenol 901-10510-2 (26.5 GHz, €11.5).

sebgus, 2023-03-26:
My apologies, I saw now that the return loss on the Amphenol connector is very good.

Maybe the 50 Ohm termination resistor could be replaced by a 0201 50 Ohm or two 0402 100 Ohm resistors in parallel to improve the design further? At 6 GHz the impedance of a regular 0402 50 Ohm could be as high as 60 Ohm due to parasitic inductance.

jankae, 2023-03-26:
Yes, I selected these connectors due to their good return loss (and the easy transition to GCPW in the layout due to the small center pin).
Maybe a 0201 termination resistor could improve things, but I have managed to get 20dB return loss with a 0402 as well and the additional return loss from the switches (and the layout surrounding them) dominate the return loss anyway. I don't think any significant return loss improvements are possible by adjusting the resistor.

But then again, this project is still in an early prototype state (I got distracted by other things for a while now), so I haven't done an extensive evaluation.

Closed 2024-09-25.

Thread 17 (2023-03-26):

LibreCAL-GUI Coefficient -> Load From Device crash at end

bvernoux, 2023-03-26:
How to reproduce the issue:

- When we have some coefficients in LibreCAL and we call in LibreCAL-GUI `Coefficient -> Load From Device` we have an application crash at end of the coefficient loading

This issue is triggered when `appwindow.cpp AppWindow::loadCoefficients()` => call the code `delete d;` due to the fact some threads are not finished and report updated progress ... to QProgressDialog and it is deleted.

- Quick fix for that is to avoid doing `delete d;` and create the QProgressDialog only one time (and destruct it when closing the application)

jankae, 2023-03-26:
Thank you very much for tracking down the issue. I couldn't replicate it and think the code should be working because all connected lambdas that are handling code for ```d``` also have ```d``` as the receiver for the slot. This should prevent the slot from being executed after ```d``` has been deleted.
But maybe I did miss something and depending on the thread timing it can still crash. I also think your proposed solution is an easy way to avoid this problem altogether, so I implemented it with 0ccba625
Please let me know if this fixes the crash for you.

Closed 2023-03-26.

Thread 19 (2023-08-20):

Transparent Emulation mode for common commercial e-Cal

bvernoux, 2023-08-20:
It will be great to study and implement an emulation mode for following commercial standard E-Cal:
- PicoVNA E-Cal 8.5 GHz Automated calibration kits, 2-Port (even if we are limited to <8GHz Max)
   - https://www.picotech.com/accessories/cal-and-check-standards/picovna-e-cal
- Keysight N7551A Electronic Calibration Module, DC to 6.5 GHz, 2-Port
   - https://www.keysight.com/fr/en/product/N7551A/electronic-calibration-module-ecal-dc-6-5-ghz-2-port.html
- Keysight N443x Electronic Calibration Module, DC to 13.5 GHz, 4-Port (even if we are limited to <8GHz Max)
   - https://www.keysight.com/fr/en/product/N4431D/rf-electronic-calibration-module-ecal-dc-13-5-ghz-4-ports.html
   - https://www.keysight.com/fr/en/product/N4432D/rf-electronic-calibration-module-ecal-dc-300-khz-18-ghz-4-ports.html
   - https://www.keysight.com/fr/en/product/N4433D/rf-electronic-calibration-module-ecal-dc-300khz-26-5ghz-4-ports.html
- Rohde & Schwarz R&S ZN-Z5x automatic calibration units Models up to 50 GHz,  with 2 and 4 ports, configurable ports
   - https://www.rohde-schwarz.com/us/products/test-and-measurement/electronic-and-inline-calibration-units/rs-zn-z5x-automatic-calibration-units_63493-418496.html
- Other TBD ? (the most used by priority with guys which can test / validate and own the hardware)

The immediate interest will be to fully emulate other e-CAL to replace them transparently with cheaper fully open source / open hardware LibreCAL which can support up to 4-Port e-CAL

jankae, 2023-09-05:
Hi, thanks for the suggestion. At the moment there are a couple of things that prevent me from even attempting this:

- I couldn't find the required documentation of the protocols used by these e-Cals (I would need a very detailed description of the USB protocol, down to the USB endpoints)
- I don't own any of these or any equipment that supports these e-Cals, so I wouldn't be able to test anything
- The companies might not react kindly to replicating their protocols and essentially pretending to be their e-Cal

So for now, I don't think there is anything that can be done here.

Closed 2023-09-05.

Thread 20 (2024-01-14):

Question about low frequency performance of the PE426462

miek, 2024-01-14:
Hi,

I'm looking to build a LibreCAL for myself and, looking through the bill of materials, I noticed that the PE426462 switch is only specified down to 10 MHz despite the overall project going down to 9 kHz. I wonder if that is an error, or do you find that the switch performs well at lower frequencies anyway despite its specs? Would you be able to share S-parameters for any prototypes, just to get an idea of how it performs?

Thanks!
Mike

jankae, 2024-01-14:
Yes, the PE426462 is used beyond its spec here. In my experience this is usually possible with a lot of switches and some tests have confirmed this so far. And of course I might adjust the spec if it turns out that 9 kHz was a bit too optimistic. Here are example measurements from a LibreCAL prototype:
[ExampleCoefficients.zip](https://github.com/jankae/LibreCAL/files/13932879/ExampleCoefficients.zip)
They are not ideal for this question because they cover 9 kHz to 8.5 GHz with only 1001 points -> frequency steps are too wide to really cover the region of interest between 9 kHz and 10 MHz. Also, ignore P2_SHORT which is obviously wrong (seems to be an OPEN, likely some issue with my prototype)

cstarkjp, 2024-01-16:
Would the PE42562 switch work? It spans 9kHz-8GHz. It's _almost_ pin compatible – just pin 7 VSS_EXT is different.

jankae, 2024-01-16:
Thanks for the partnumber, that could be a good alternative if the original part would degrade performance below 10 MHz too much (although it is a bit more expensive). I think this would even be completely pin compatible: Pin 7 of the PE426462 is GND and if you connect VSS_EXT to GND on the PE42562, it is using its integrated negative voltage generator.

miek, 2024-01-20:
Thanks! Sounds like it works well despite the spec so I'll go ahead and try it out, and report back if I have any interesting test results.
I was considering the PE426462 too, but it seemed to be quite a lot more expensive so it'd be nice to avoid if possible.

Closed 2024-01-20.

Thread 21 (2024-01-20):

GCPW dimensions don't match the net class specs due to zone clearance

miek, 2024-01-20:
I noticed that the GCPW is specified as 0.295/0.2mm trace/space (which is very to close to JLC's calculator), but in practice it comes out differently because the zone clearance is set to 0.36mm. I'm not sure if that'll cause a big difference and clearly it's worked so far, but I thought I'd just let you know.

I'm planning to go ahead and get boards with the 0.295/0.2 spec and I'll post TDR/VNA measurements when I get them.

jankae, 2024-01-21:
Yep, you are right that there is a difference to what the calculator says. I guess the data in the KiCad files is a bit confusing because of these PRs: #2 and #8

What I have observed experimentally is that the originally chosen width and distance (0.3mm and 0.36mm) works very well in the LibreVNA. #2 changed the trace width to 0.295 which I didn't mind (such a small change). I didn't merge #8 because I wanted to keep the distance to GND at 0.36mm (despite the calculator saying this is wrong). In the end it doesn't really matter here (at least in my opinion):
- traces are very short
- errors from transitions to connectors/switch ICs will dominate reflections and losses (never mind the inherent FR4 losses)
- the calibration standards are far from ideal anyway and this will be compensated for by the calibration coefficients

It really comes down to me being unwilling to change a proven and working design. Getting consistent trace impedances on FR4 is always a bit of a gamble.

miek, 2024-01-21:
Ah right, I didn't realise that the net class was introduced in those PRs and I was also confused because 0.18mm spacing was mentioned as the intended value previously, but if 0.36mm was intended then fair enough!

Closed 2024-01-21.

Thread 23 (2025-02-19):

Bad factory calibration coefficients

jankae, 2025-02-19:
## What happened?

The LibreCAL only works because each individual unit is measured and has the results from the measurement stored (the factory calibration coefficients).
The measurement is done by a [script](https://github.com/jankae/LibreCAL/blob/main/Software/Scripts/FactoryCoefficients/createFactoryCoefficients.py) which not only takes these measurements but also checks some limits and writes them to the LibreCAL.

And unfortunately these limit checks were not sufficient and quite a few LibreCAL devices were send out with wrong factory calibration coefficients. Here are the details:

- Each LibreCAL is measured by a 4-port VNA to characterize it
- This VNA needs to be calibrated before the measurement
- The calibration kit definition in the VNA did not match the actual calibration kit used. This means that the calibration of the VNA was not correct and these errors transfer to the LibreCAL
- This was not immediately obvious, because the calibration kit definition was only wrong in one spot: the delay of the THRU standard

As a consequence, there are LibreCALs out there which have the wrong THRU standard delay as well. So far the bad news. The good news: the amount of this error is precisely known and the factory calibration coefficients can be corrected without needing to measure each LibreCAL again.

## How can I check if my LibreCAL is affected?

Depending on how meticulous you verify your calibration, you may not have noticed the mistake so far. It only affects transmission measurements, reflection measurements were always correct.

Starting from version 0.2.3, the LibreCAL-GUI will notify you about the bad coefficients if you connect to an affected LibreCAL. But if you want to check based on your own measurements, this is how to do it:

1. Calibrate the VNA with the LibreCAL
2. Connect both ports to each other with a known through connector (you need to know the delay of it). You may see something like this:
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
The phase value is rising towards higher frequencies. This would indicate a connector with negative delay which is of course impossible. The error comes from the bad LibreCAL factory coefficients. If your through connector is too long, it may still show up with a falling phase. In this case, you need to know the actual delay of your through connector to check:
    1. Add a port extension to port 1 and enter the delay of your through connector
    2. If your calibation is good, you should have a constant phase value of zero (or very close to it):
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
If your calibration is bad, your phase will either rise or fall towards higher frequencies.

Summary:
1. Connect a short through connector after the calibration
2. If the phase goes positive -> your LibreCAL is affected
3. If the phase goes negative -> your LibreCAL might be affected, check with the port extension if you know the delay of your connector

## What was done to prevent something like this from happening again?

The error in the calibration kit definition has been identified and corrected. Additionally, the factory calibration scripts have been adjusted to catch something like this in the future.

## How can I fix my LibreCAL?

Thankfully it was possible to identify the exact error and calculate new factory calibration coefficients based on the bad coefficients and the known error. To fix your LibreCAL, you just need to update the factory calibration coefficients stored on it. To do that, follow these steps:

1. Download the latest version of the LibreCAL-GUI and the LibreCAL firmware (at the time of writing this issue, that is version 0.2.3)
2. Update the LibreCAL firmware
3. Start the LibreCAL-GUI and connect to your LibreCAL
4. If your LibreCAL has bad factory coefficients, this window will pop up:
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
5. Click `yes`. The factory coefficient update window will open:
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
6. Keep `Update coefficients from manufacturing server` selected
7. Click `Update Factory Coefficients`
8. The corrected coefficients will be downloaded from the server and written to your LibreCAL:
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

Updating the factory coefficients at any point (even if your LibreCAL was not affected) is possible over here:
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

You can also download the factory coefficients as a Zip file directly from the server [here](https://librecal.kaeberich.com/).

I am sorry for having missed the problem until now and hope that it has not caused any serious issues.

Closed 2025-03-03.

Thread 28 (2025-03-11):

Unable to load factory coefficients on macOS

nall, 2025-03-11:
On macOS I get errors when trying to load the factory coefficients to my LibreCAL. It looks like the current code attempts to extract the zip files containing factory coefficients to a non-writable location on macOS.

Downloading from the server results in an error:
```
Looking up factory coefficient data...
Factory coefficients downloaded...
Failed to create folder for zipped data
```

Attempting to use a local zip file results in:
```
Unzipping file...
Extracting zip file failed
```

Attached is a patch that addresses this by initializing a new variable`CalDevice::tmpDir` in the constructor to a value returned from `QStandardPaths::writableLocation(QStandardPaths::TempLocation)`. This variable is then used when extracting both the downloaded and local zip files. With this patch I no longer see the errors and the coefficients are applied to the device successfully.

[LibreCAL-GUI-macOS-extract-zip-permissions.diff.zip](https://github.com/user-attachments/files/19172610/LibreCAL-GUI-macOS-extract-zip-permissions.diff.zip)

Closed 2025-03-11.

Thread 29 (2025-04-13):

LibreCAL does not appear in programs

la3pna, 2025-04-13:
I have a LibreCAL and it does not appear in the LibreCAL or LibreVNA gui.

It appears as 2 drives, and a serial port as usual, and when sending *IDN?\r\n I get:
`LibreCAL,LibreCAL,5mNkR0uHIyoA,0.2.3<\r><\n>`

But it does not appear in the LibreVNA 1.6.2, nor in Librecal 0.2.3. I upgraded the firmware to 0.2.3 on the device to see if that would help, but I still do not get the cal to appear in the GUI:

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

Any help appreciated.

jankae, 2025-04-13:
Are you by any chance using Linux and have forgotten to set up the udev rule? That would explain the problem.
But your screenshot looks very much like Windows.

la3pna, 2025-04-13:
This is in Windows.

With Best regards, Thomas S. Knutsen.

 Please  avoid sending  me  Word  or  PowerPoint  attachments.

søn. 13. apr. 2025 kl. 17:20 skrev Jan Käberich ***@***.***>:

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

jankae, 2025-04-13:
Which Windows version?

The LibreCAL uses WCID to automatically load the correct driver (Winusb). For older windows versions this feature does not always work.

Does the LibreCAL show up in the device manager?

You could also try installing the Winusb driver manually for the LibreCAL using Zadig: https://zadig.akeo.ie/

jankae, 2025-04-16:
Did you manage to solve this?

la3pna, 2025-04-20:
> Did you manage to solve this?

Not been able to solve this. Computer is Win10,  I have re-installed the driver, and downloaded new versions of the LibreVNA GUI and LibreCAL GUI without any sucess. It works correctly on a win11 computer.

jankae, 2025-04-20:
This is quite strange. Does the LibreCAL show up in the device manager?

la3pna, 2025-04-20:
It shows up as 3 devices as far as I can determine:
- USB composite device
- USB mass storage device
- USB Serial device (com port)

There is no difference between my win10 computer where it does not work, and my win10 computer where it works when it comes to how it appears in device manager.

jankae, 2025-04-21:
It should show up 4x in total in the device manager.

2x as a mass storage device:
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

1x as a virtual COM port:
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

1x as a vendor specific (custom) USB device:
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

The last one is the important entry because both GUIs connect to it.

la3pna, 2025-05-21:
I'm lacking the vendor spesific USB device. I have not been able to fix that with reinstall. Any suggestion on how to install it manualy?

jankae, 2025-05-22:
Okay, at least that explains why the programs do not find the LibreCAL. I have to admit that I do not really have any idea why the vendor specific USB device is not showing up. The other USB devices are being detected, so the USB enumeration must work. And even if you do not have a driver installed it should still show up as a USB device (maybe with some indication that Windows does not know what to do with it).

If you were on Linux I would ask for the `lsusb -v` output. Maybe you can find something equivalent for Windows?

Or maybe try another Windows machine if you have access to one? Just to check if that makes any difference.

jankae, 2025-07-19:
Closing due to inactivity. If there is new information, I am happy to re-open

Closed 2025-07-19.

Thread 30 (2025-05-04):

USB not recognized after intermittent overflow

nateof8, 2025-05-04:
The USB connection fails intermittently (more often than not) while trying to load coefficients from the LibreCAL.   I've narrowed the issue down to the LibreCAL embedded software, although initial discovery of this issue was using the LibreVNA app v1.6.2 during calibration on a Windows 11 machine using the factory provided USB cable.  My LibreCAL was delivered with firmware v0.2.1 and calibration completed successfully several times through the LibreVNA app.  I noticed that the calibration seemed a bit off, so I updated the firmware to v0.2.3 and completed the update of my Factory calibration files per https://github.com/jankae/LibreCAL/issues/23.  This all worked fine, but I was unable to run calibration through the LibreVNA app after that which led me down this path of troubleshooting.

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

To isolate the issue, I tried using the LibreCAL app v0.2.3 to load FACTORY coefficients from the device (LibreCAL embedded software was also at v0.2.3).  The coefficient loading process began, started to lag, and eventually reached 100%, but only some of the coefficients are loaded.  Upon failure the LibreCAL app loses connection to the LibreCAL and Windows indicates that the USB device is not recognized.  This failure was also replicated on an additional Windows 10 machine and a known good USB cable (the USB-C to USB-C cable used to run the LibreVNA).

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

To further isolate , I used the virtual COM port interface, Tera Term and the SCPI command ":COEFFicient:GET? FACTORY P1_OPEN."  This command worked, but intermittently fails during the response after a few repeated requests.  Commands with shorter responses never fail (i.e. ":COEFFicient:NUMber? FACTORY P1_OPEN" or ":FIRMWARE?') even when using a Tera Term macro to send the requests repeatedly (every 10-100 ms) for more than 10 minutes.

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

I suspected some sort of buffer overflow during USB tx, so I tried to isolate the issue in code by adding some debug output to the Touchstone::PrintFile() function, but the issue persisted and I don't see a clear connection to the USB buffer status.

```
static void debug_log(const char* msg) {
    tud_cdc_write_str(msg);
    tud_cdc_write_flush();
}

if(br > 0) {
    char logbuf[64];
    snprintf(logbuf, sizeof(logbuf), "[f_read br=%d]\r\n", br);
    debug_log(logbuf);

    snprintf(logbuf, sizeof(logbuf), "[usb available=%d]\r\n", tud_cdc_write_available());
    debug_log(logbuf);

    debug_log("[tx_func start]\r\n");
    tx_func(buffer, br, interface);
    debug_log("[tx_func end]\r\n");

    vTaskDelay(1);
}
if(br < sizeof(buffer)) {
    break;
}
```

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

I made several captures in Wireshark and have saved the log files, but apparently can't share them on Github.  Here is a screenshot of one of the captures while I was using Tera Term to troubleshoot.

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

I'm happy to continue to troubleshoot, but am sort of at a loss as to what to try next.  I thought I would share my findings and hope someone has some ideas.

jankae, 2025-05-06:
Thank you for all the work and narrowing it down. You mentioned that you updated to firmware 0.2.3 but have you tried the latest development version as well? (download here: https://github.com/jankae/LibreCAL/actions/runs/13782279765).

I do remember seeing occasional USB issues which stopped after I updated the Pico SDK in 4e90efacc2aa6cb49272e5c4a0247e08cd54e76b. With a bit of luck this already solves your problem and if that is the case it is really time for a 0.2.4 release.

jankae, 2025-05-12:
Any luck with the development version of the LibreCAL?

jankae, 2025-05-30:
There are some issues in the toolchain which I can not quite figure out yet. Switching to SDK version 2.1.1 made it much more stable for me but then Github deprecated the Ubuntu 20.04 runner (which was building the embedded firmware). The 22.04 or 24.04 runners updated GCC from version 9.3 to 10.3.

And for some reason building the exact same code with 10.3 results in a firmware that crashes/throws errors when reading and/or writing calibration coefficients. Even newer GCC versions also exhibit problems although the exact symptom varies. I am bit clueless right now because I do not really believe in a compiler bug but have no better explanation.

For now I am manually installing and using GCC 9.3 in the CI/CD which seems to be a feasible workaround. Could you please try the firmware from this build? https://github.com/jankae/LibreCAL/actions/runs/15323882295

bvernoux, 2025-05-30:
@jankae Do you have tested **toolchainVersion 14_2_Rel1** (it is based on arm-none-eabi v14.2.1) used by Pico SDK 2.1.1 for Visual Studio ([Raspberry Pi Pico Visual Studio Code extension](https://marketplace.visualstudio.com/items?itemName=raspberry-pi.raspberry-pi-pico) in VS Code) ?

jankae, 2025-05-30:
Yes I did and the problems changed but did not disappear.

But I believe I finally found something (turns out that attaching a debugger and adding UART output actually helps). So far I have identified two different problems:

**Problem 1:**
Two different tasks call functions from the TinyUSB library: `defaultTask` and `TinyUSB`. TinyUSB can be configured to use FreeRTOS mutexes with the option `OPT_OS_FREERTOS` which would use a FreeRTOS mutex for access control to USB endpoint streams. But apparently that option is hardcoded to `OPT_OS_PICO` in the SDK/TInyUSB:
[Some](https://www.eevblog.com/forum/microcontrollers/rp2040-how-to-use-freertos-with-tinyusb/) [links](https://github.com/hathach/tinyusb/discussions/1951) [with explanations](https://github.com/raspberrypi/pico-sdk/issues/1326)

And the mutex implementation with that option has no concept of task priorities. If the lower priority task (which is `TinyUSB`) grabs the mutex first and then the higher priority task tries to lock it, that higher priority task prevents the lower priority task from ever unlocking it and we have a deadlock.

The only solution (apart from changing to `OPT_OS_FREERTOS` in the SDK/TinyUSB which I apparently can not do from my code if I want to keep using the standard toolchain) is to give all tasks the same priority (and having preemption turned on in FreeRTOS).

With that change I no longer observe any deadlock but they were reasonable infrequent before so I do not fully trust the solution yet.

**Problem 2:**
With newer compiler versions writing to the Flash sometimes fails (which then escalates to a fatfs error and ultimately an error response on the SCPI interface). The problem is the timing of the CS pin: The CS release between the command `Write Enable Latch` and an erase or write operation is very short (8-10ns). The flash chip requires a longer time. Adding a `sleep_us(1)` there seems to solve the issue.

I guess both problems are ultimately down to timing and that can obviously change if newer compiler versions are able to optimize more.

I am cautiously optimistic that I have now identified the root causes and can use newer toolchain versions. Commits of these changes will follow.

jankae, 2025-06-01:
Code changes are added, please test again with [v0.3.0](https://github.com/jankae/LibreCAL/releases/tag/v0.3.0)

nateof8, 2025-06-01:
Jan...I've tested v0.3.0 and can confirm it has fixed all of the issues that I was experiencing.  Thanks for taking the time to figure it out.

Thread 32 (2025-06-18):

Calibration lock if Wait/Heater has not yet reached the temperature

dh5dan, 2025-06-18:
I have a feature request for LibreCal.
I noticed in this video that a calibration was performed even though the Wait LED for the heater was still red.

This is about the video here:
https://www.youtube.com/watch?v=H64bFWH6v2k

Can a calibration lock be implemented to prevent this from happening?

Calibration is completely invalid if the process is not followed. This would also explain in the video why the value in the Smith chart wasn't completely at 0, even though it should have been.

Regards Chris

miek, 2025-06-18:
> Calibration is completely invalid if the process is not followed. This would also explain in the video why the value in the Smith chart wasn't completely at 0, even though it should have been.

It shouldn't be at 0. If you calibrate to the reference plane of a male SMA connector then disconnect everything and measure the bare connector, the centre pin protrudes past the reference plane so you have a few mm of transmission line then an open with some fringing capacitance. Both of those effects contribute to showing some clockwise rotation from the open point at higher frequencies.

miek, 2025-06-19:
> But I'm wondering why the S21's line isn't at 0, but rather about 1-2 dB lower. My guess is that this is the internal attenuation of the LibreCal, since you can't calibrate it out. So if you connect a pass-through adapter, you should get 0. I hope that's the case.

Yep, the through path of any eCal will have some loss. It's not really about whether it can be calibrated out, it's just that now you're calibrated to the ends of the SMA cables and you're measuring that loss directly. If you connected a pass-through adapter instead you'd get *almost* 0, though it's still going to have a tiny bit of loss.

In general there's quite a bit of misinformation out there about what to expect after calibration. If you re-measure the standards after calibration, you should measure whatever their characteristics are defined to be. It's quite rare for calibration standards to be ideal, so usually you shouldn't see perfect dots at the open/short point or zero-loss thrus.

> I just noticed something else. Is it correct that eCal lists 8.5 GHz as the stop frequency? The SVA can only go up to 3.2 GHz. But I think this is just a cosmetic display error, because the SNA5000 is supposed to work with it, and it can run at 8.5 GHz.

This is just saying that the calibration data stored in the eCal is valid within the range from 9 kHz to 8.5 GHz, so yeah, it can be used on other VNAs with a larger frequency range.

jankae, 2025-06-23:
> Can a calibration lock be implemented to prevent this from happening?
>
> Calibration is completely invalid if the process is not followed.

You are correct, for best results the LibreCAL should only be used when its temperature has stabilized. But the data does not shift that much even for slightly different temperatures and I do not want to force the user to wait if he want to use it immediately.

Especially in the video you mentioned (when being used with a Siglent VNA), I _couldn't_ even force the user to wait. The Siglent VNA just tells the eCal which standard it wants at which port but it never queries the temperature. The only thing I could do here is turn off USB completely while the temperature is not stable (which would result in the VNA not detecting the LibreCAL at all). But I do not think this is a very user friendly solution.

In my mind it is okay to pass this responsibility off to the user. In the overall scheme of mistakes you can make while using a VNA, waiting for a ready LED to turn on seems to be one of the easier tasks.

jankae, 2025-06-23:
Got it and thank you for the suggestion. I will likely implement such a function when using the LibreCAL with the LibreVNA-GUI but for Siglent VNAs there is nothing I can do.

jankae, 2025-06-24:
The LibreVNA-GUI now has an option to enforce waiting for LibreCAL temperature stabilization: https://github.com/jankae/LibreVNA/commit/b3eb1735cc24cfa1b26778661b6e378afffe6d0b

It can be found in the preferences under Acquisition:
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

If checked (default setting), the behavior is as before.

If unchecked, the electronic calibration can only be started once the LibreCAL temperature is stable.

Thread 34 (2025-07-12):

Latest 0.3.0 macOS version crashes on run.

vsilves, 2025-07-12:
The newest version  0.3.0 of LibreCal-GUI latest app for macOS crashes on run.  Tried on macOS  Sequoia 15.5 using MacBook Pro M1.  Clearing extended attributes with xattr (of course), ad-hoc signing, or using my developer signature did not help.  I had to boot a Windows 11 virtual machine in VM Ware (yes ARM version) and the windows version did work there (probably emulated by Windows 11).

Not digitally signed even ad-hoc and unable to digitally sign it ad-hoc.

See below the full crash report from running the macOS latest version.

Here if I check the digital signature I get:
Executable=/Volumes/Data/Applications/LibreCAL-GUI.app/Contents/MacOS/LibreCAL-GUI
Identifier=LibreCAL-GUI
Format=app bundle with Mach-O thin (arm64)
CodeDirectory v=20400 size=4901 flags=0x20002(adhoc,linker-signed) hashes=150+0 location=embedded
Hash type=sha256 size=32
CandidateCDHash sha256=6a07824a862033566efa5d7f9dd65d4d4922d54f
CandidateCDHashFull sha256=6a07824a862033566efa5d7f9dd65d4d4922d54fac19a5373b92de94a45a4f6a
Hash choices=sha256
CMSDigest=6a07824a862033566efa5d7f9dd65d4d4922d54fac19a5373b92de94a45a4f6a
CMSDigestType=2
CDHash=6a07824a862033566efa5d7f9dd65d4d4922d54f
Signature=adhoc
Info.plist=not bound
TeamIdentifier=not set
Sealed Resources=none
Internal requirements=none
LibreCAL-GUI.app: code has no resources but signature indicates they must be present
--

If I try to ad-hoc sign the app I get:
Executable=/Volumes/Data/Applications/LibreCAL-GUI.app/Contents/MacOS/LibreCAL-GUI
Identifier=com.yourcompany.LibreCAL-GUI
Format=app bundle with Mach-O thin (arm64)
CodeDirectory v=20400 size=5013 flags=0x2(adhoc) hashes=150+3 location=embedded
Hash type=sha256 size=32
CandidateCDHash sha256=d3696f6dbf6db81b2de0bc800e90b8d2a3091e09
CandidateCDHashFull sha256=d3696f6dbf6db81b2de0bc800e90b8d2a3091e09a60fa75ea1f294073b2efa84
Hash choices=sha256
CMSDigest=d3696f6dbf6db81b2de0bc800e90b8d2a3091e09a60fa75ea1f294073b2efa84
CMSDigestType=2
CDHash=d3696f6dbf6db81b2de0bc800e90b8d2a3091e09
Signature=adhoc
Info.plist entries=11
TeamIdentifier=not set
Sealed Resources version=2 rules=13 files=64
Internal requirements count=0 size=12
LibreCAL-GUI.app: invalid or unsupported format for signature
In subcomponent: /Volumes/Data/Applications/LibreCAL-GUI.app/Contents/PlugIns/imageformats/libqmng.dylib
---

So fails to sign libqmng.dylib.  If I remove that file, the it will fail to sign the next one in that same subfolder.

---
-------------------------------------
Translated Report (Full Report Below)
-------------------------------------

Process:               LibreCAL-GUI [5947]
Path:                  /Volumes/VOLUME/*/LibreCAL-GUI.app/Contents/MacOS/LibreCAL-GUI
Identifier:            com.yourcompany.LibreCAL-GUI
Version:               ???
Code Type:             ARM-64 (Native)
Parent Process:        launchd [1]
User ID:               501

Date/Time:             2025-07-11 21:13:00.9269 -0500
OS Version:            macOS 15.5 (24F74)
Report Version:        12
Anonymous UUID:        564AA5EA-742D-3779-8450-0DEEBA97A548

Sleep/Wake UUID:       83CABC98-161C-4194-99A1-0B4770308AE2

Time Awake Since Boot: 36000 seconds
Time Since Wake:       4166 seconds

System Integrity Protection: enabled

Crashed Thread:        0

Exception Type:        EXC_BAD_ACCESS (SIGKILL (Code Signature Invalid))
Exception Codes:       UNKNOWN_0x32 at 0x000000010420c000
Exception Codes:       0x0000000000000032, 0x000000010420c000

Termination Reason:    Namespace CODESIGNING, Code 2 Invalid Page

VM Region Info: 0x10420c000 is in 0x10420c000-0x104238000;  bytes after start: 0  bytes before end: 180223
      REGION TYPE                    START - END         [ VSIZE] PRT/MAX SHRMOD  REGION DETAIL
      __LINKEDIT                  1041f0000-10420c000    [  112K] r--/r-- SM=COW  /Volumes/VOLUME/*/LibreCAL-GUI.app/Contents/MacOS/LibreCAL-GUI
--->  mapped file                 10420c000-104238000    [  176K] r--/rwx SM=COW  Object_id=46705343
      GAP OF 0xd8000 BYTES
      mapped file                 104310000-104370000    [  384K] ---/--- SM=COW  Object_id=f1295c3b

Thread 0 Crashed:
0   dyld                          	       0x19cfa8278 mach_o::Header::forEachLoadCommand(void (load_command const*, bool&) block_pointer) const + 48
1   dyld                          	       0x19cfab1d4 mach_o::Header::forEachSegment(void (mach_o::Header::SegmentInfo const&, bool&) block_pointer) const + 124
2   dyld                          	       0x19cfaa604 mach_o::Header::preferredLoadAddress() const + 124
3   dyld                          	       0x19cf57290 dyld4::JustInTimeLoader::withRegions(dyld3::MachOFile const*, void (dyld3::Array<dyld4::Loader::Region> const&) block_pointer) + 52
4   dyld                          	       0x19cf57ac8 dyld4::JustInTimeLoader::makeJustInTimeLoaderDisk(Diagnostics&, dyld4::RuntimeState&, char const*, dyld4::Loader::LoadOptions const&, bool, unsigned int, mach_o::Layout const*) + 1108
5   dyld                          	       0x19cf4a8b0 dyld4::Loader::makeDiskLoader(Diagnostics&, dyld4::RuntimeState&, char const*, dyld4::Loader::LoadOptions const&, bool, unsigned int, mach_o::Layout const*) + 176
6   dyld                          	       0x19cf4c2cc invocation function for block in dyld4::Loader::getLoader(Diagnostics&, dyld4::RuntimeState&, char const*, dyld4::Loader::LoadOptions const&) + 2884
7   dyld                          	       0x19cf4afd8 dyld4::Loader::forEachResolvedAtPathVar(dyld4::RuntimeState&, char const*, dyld4::Loader::LoadOptions const&, dyld4::ProcessConfig::PathOverrides::Type, bool&, void (char const*, dyld4::ProcessConfig::PathOverrides::Type, bool&) block_pointer) + 764
8   dyld                          	       0x19cf35d60 dyld4::ProcessConfig::PathOverrides::forEachPathVariant(char const*, mach_o::Platform, bool, bool, bool&, void (char const*, dyld4::ProcessConfig::PathOverrides::Type, bool&) block_pointer) const + 556
9   dyld                          	       0x19cf4ab18 dyld4::Loader::forEachPath(Diagnostics&, dyld4::RuntimeState&, char const*, dyld4::Loader::LoadOptions const&, void (char const*, dyld4::ProcessConfig::PathOverrides::Type, bool&) block_pointer) + 260
10  dyld                          	       0x19cf4b3b0 dyld4::Loader::getLoader(Diagnostics&, dyld4::RuntimeState&, char const*, dyld4::Loader::LoadOptions const&) + 920
11  dyld                          	       0x19cf556d4 invocation function for block in dyld4::JustInTimeLoader::loadDependents(Diagnostics&, dyld4::RuntimeState&, dyld4::Loader::LoadOptions const&) + 456
12  dyld                          	       0x19cfaa2b4 invocation function for block in mach_o::Header::forEachLinkedDylib(void (char const*, mach_o::LinkedDylibAttributes, mach_o::Version32, mach_o::Version32, bool, bool&) block_pointer) const + 136
13  dyld                          	       0x19cfa8318 mach_o::Header::forEachLoadCommand(void (load_command const*, bool&) block_pointer) const + 208
14  dyld                          	       0x19cfa9fa0 mach_o::Header::forEachLinkedDylib(void (char const*, mach_o::LinkedDylibAttributes, mach_o::Version32, mach_o::Version32, bool, bool&) block_pointer) const + 160
15  dyld                          	       0x19cf553e4 dyld4::JustInTimeLoader::loadDependents(Diagnostics&, dyld4::RuntimeState&, dyld4::Loader::LoadOptions const&) + 164
16  dyld                          	       0x19cf335a8 dyld4::prepare(dyld4::APIs&, mach_o::Header const*) + 956
17  dyld                          	       0x19cf331d8 dyld4::start(dyld4::KernelArgs*, void*, void*)::$_0::operator()() const + 236
18  dyld                          	       0x19cf32b4c start + 6000

Thread 0 crashed with ARM Thread State (64-bit):
    x0: 0x000000010420c000   x1: 0x000000016bc894e8   x2: 0x0000000000000001   x3: 0x0000000000040002
    x4: 0x0000000000000003   x5: 0x0000000000000000   x6: 0x0000000000000000   x7: 0x0000000000000000
    x8: 0x000000016bc89538   x9: 0x000000016bc894f8  x10: 0x000000020c453730  x11: 0x000000000000003e
   x12: 0x000000000000003f  x13: 0x0000000000000031  x14: 0x0000000000000000  x15: 0xffffffffffffffd8
   x16: 0x000000019cfab378  x17: 0x6ae100016bc894e8  x18: 0x0000000000000000  x19: 0x000000016bc89538
   x20: 0x000000010420c000  x21: 0x000000016bc894e8  x22: 0x000000016bc8aaf0  x23: 0x0000000000000000
   x24: 0x0000000000000000  x25: 0x000000010420c000  x26: 0x000000016bc89e60  x27: 0x000000010420c000
   x28: 0x0000000000000001   fp: 0x000000016bc894d0   lr: 0x000000019cfab1d4
    sp: 0x000000016bc89450   pc: 0x000000019cfa8278 cpsr: 0x00001000
   far: 0x000000010420c000  esr: 0x92000007 (Data Abort) byte read Translation fault

Binary Images:
       0x104174000 -        0x1041e7fff com.yourcompany.LibreCAL-GUI (*) <d41ad78f-a244-34ab-83a8-a1dbf3a7cbc5> /Volumes/VOLUME/*/LibreCAL-GUI.app/Contents/MacOS/LibreCAL-GUI
       0x19cf2c000 -        0x19cfc74cf dyld (*) <9cf0401a-a938-389e-a77d-9e9608076ccf> /usr/lib/dyld
               0x0 - 0xffffffffffffffff ??? (*) <00000000-0000-0000-0000-000000000000> ???

External Modification Summary:
  Calls made by other processes targeting this process:
    task_for_pid: 0
    thread_create: 0
    thread_set_state: 0
  Calls made by this process:
    task_for_pid: 0
    thread_create: 0
    thread_set_state: 0
  Calls made by all processes on this machine:
    task_for_pid: 0
    thread_create: 0
    thread_set_state: 0

VM Region Summary:
ReadOnly portion of Libraries: Total=616.5M resident=0K(0%) swapped_out_or_unallocated=616.5M(100%)
Writable regions: Total=8272K written=96K(1%) resident=96K(1%) swapped_out=0K(0%) unallocated=8176K(99%)

                                VIRTUAL   REGION
REGION TYPE                        SIZE    COUNT (non-coalesced)
===========                     =======  =======
STACK GUARD                       56.0M        1
Stack                             8176K        1
__DATA                              27K        2
__DATA_CONST                        46K        2
__DATA_DIRTY                         7K        1
__LINKEDIT                       615.5M        2
__TEXT                            1088K        2
__TPRO_CONST                       128K        1
mapped file                        176K        1
page table in kernel                96K        1
===========                     =======  =======
TOTAL                            681.0M       14

-----------
Full Report
-----------
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

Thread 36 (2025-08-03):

Suggestion re:Windows 7

ke5fx, 2025-08-03:
You might add a line to your readme indicating that Windows 10 or later is required.  Lots of lab PCs still run Windows 7.  (Those can be 'unofficially' supported via the USB CDC driver installed by Zadig 2.9, but the Qt-based GUI still won't run.)

jankae, 2025-08-03:
Thanks, probably a good idea. I have added the supported windows version numbers: 8a9194383

Closed 2025-08-03.

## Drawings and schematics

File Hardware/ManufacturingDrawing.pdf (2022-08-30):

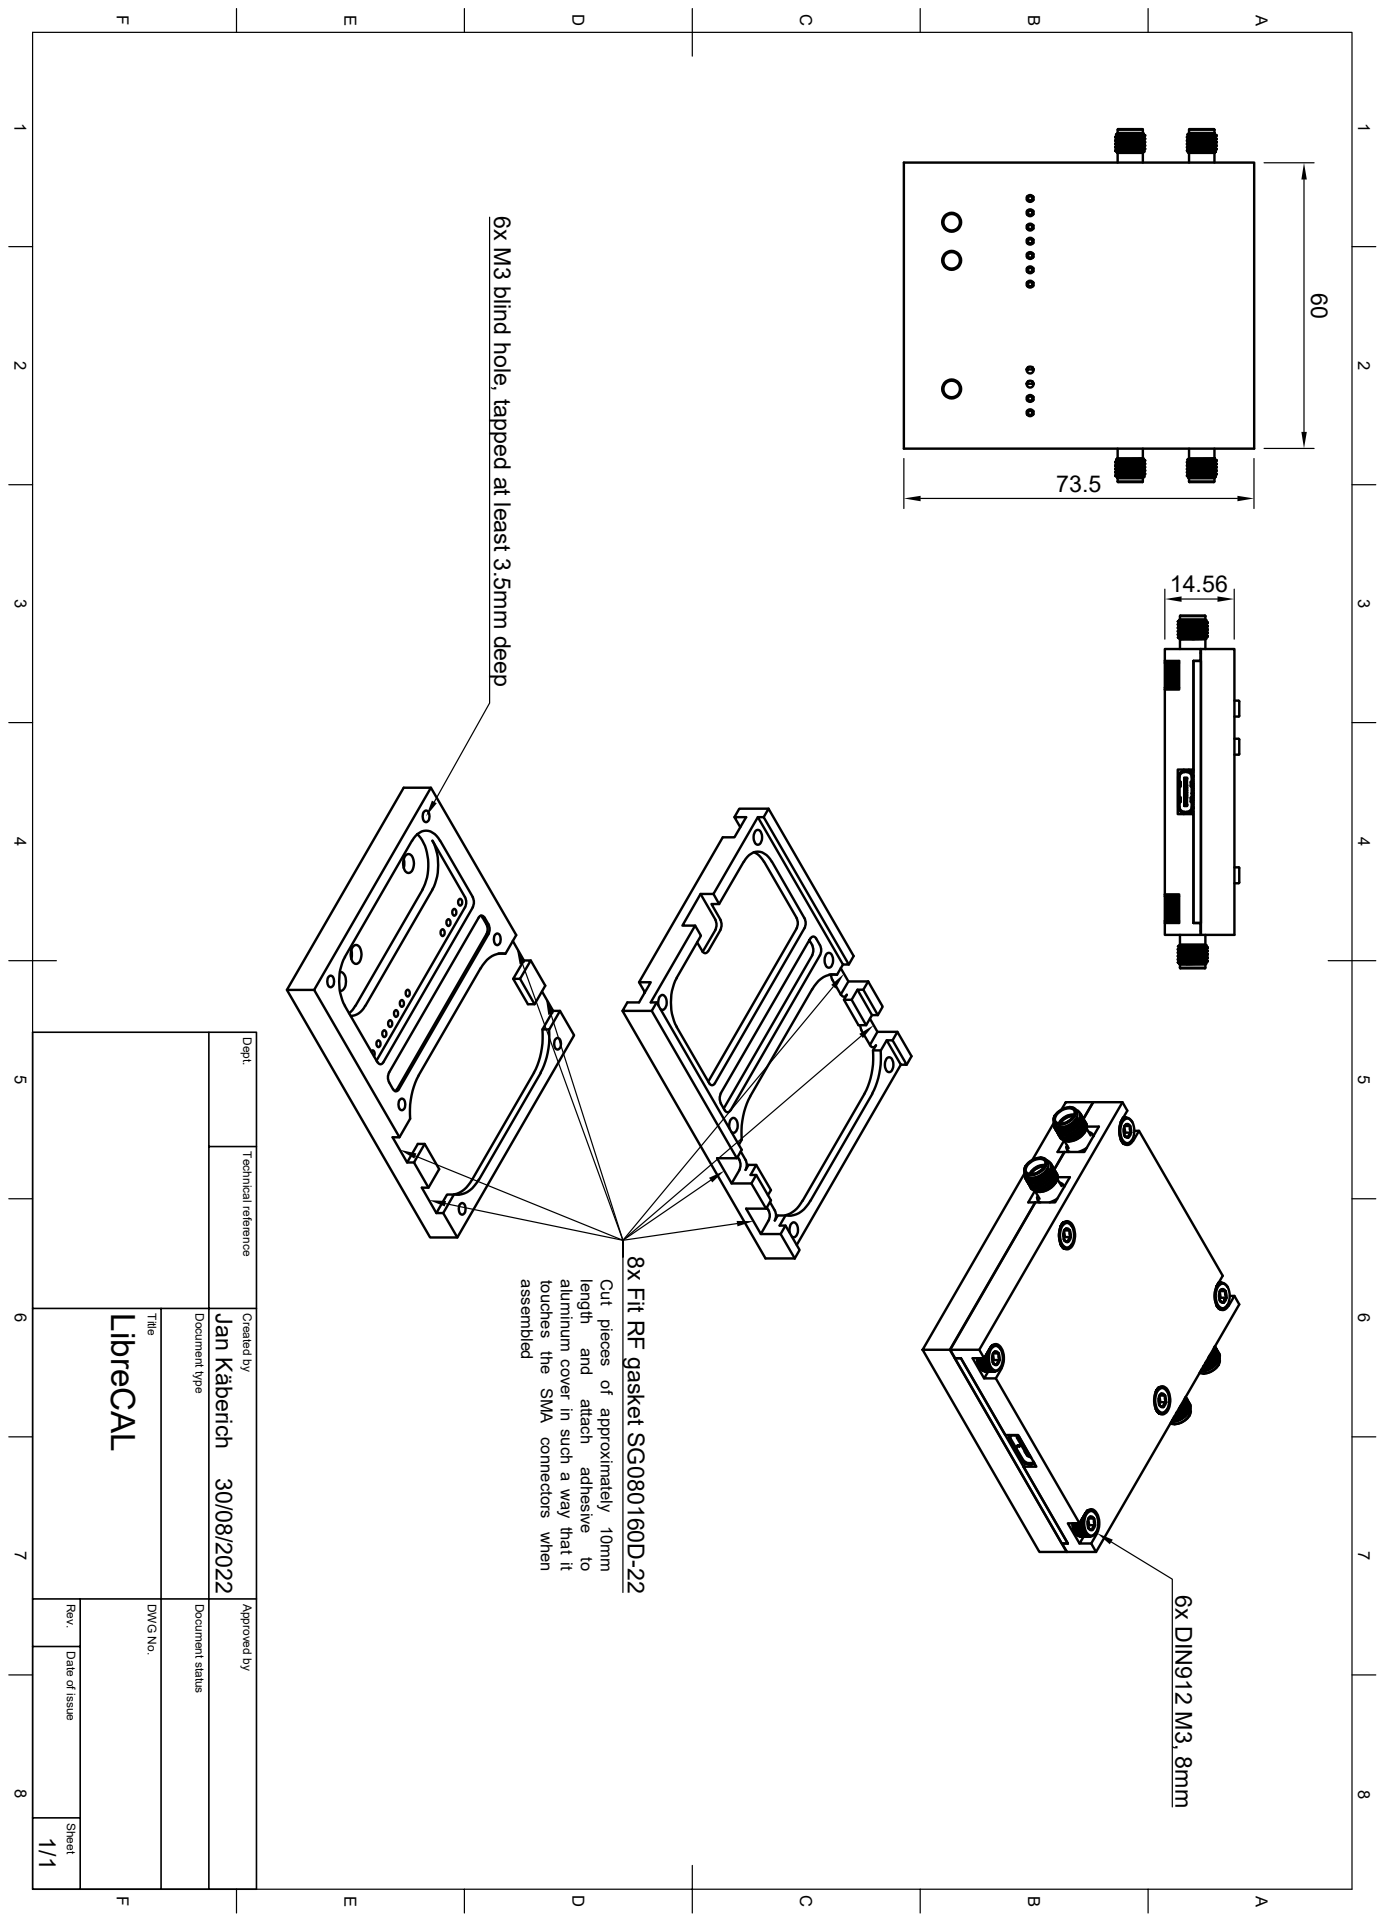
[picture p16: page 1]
14.56 6x DIN912 M3, 8mm ⁶x M3 blind hole, tapped at least 3.5mm deep; 8x Fit RF gasket SG080160D-22 assembled touches the SMA connectors when aluminum cover in such a way that it length and attach adhesive to Cut pieces of approximately 10mm

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

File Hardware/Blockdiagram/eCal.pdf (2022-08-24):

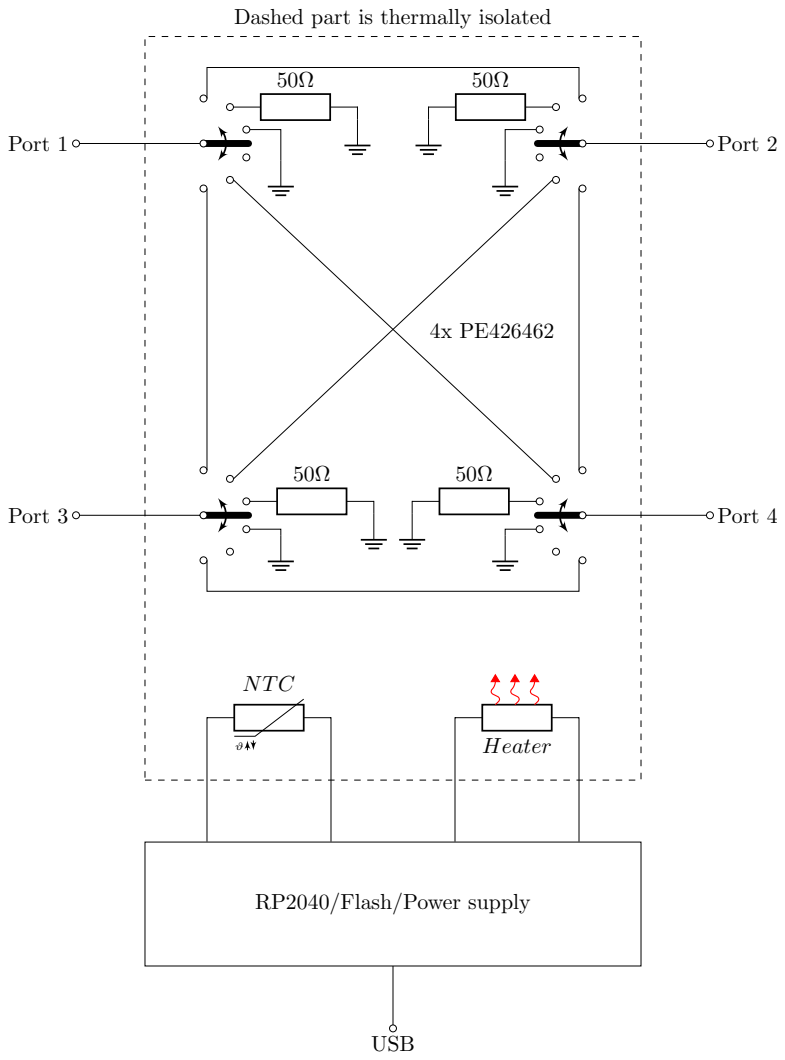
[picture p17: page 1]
Port 1; Port 2; Port 3; Port 4; Heater; USB

Dashed part is thermally isolated

RP2040/Flash/Power supply

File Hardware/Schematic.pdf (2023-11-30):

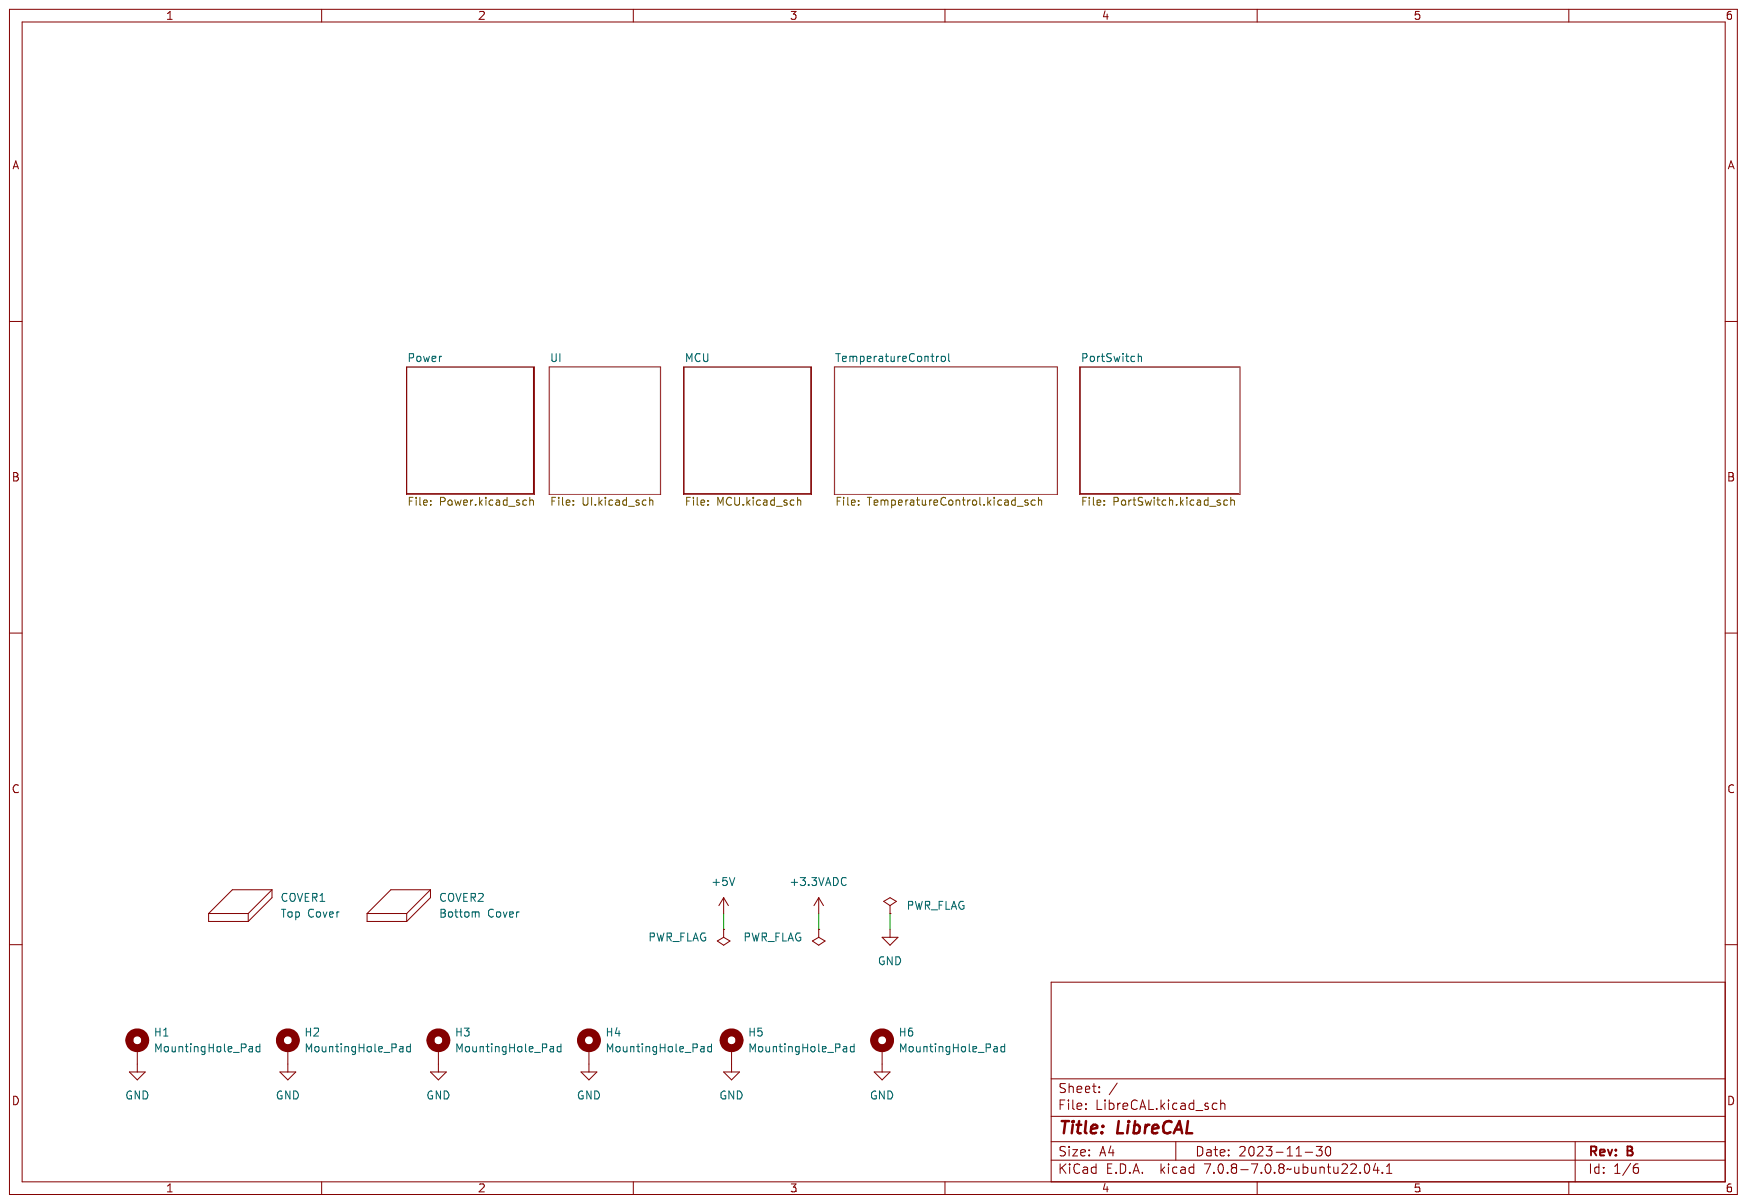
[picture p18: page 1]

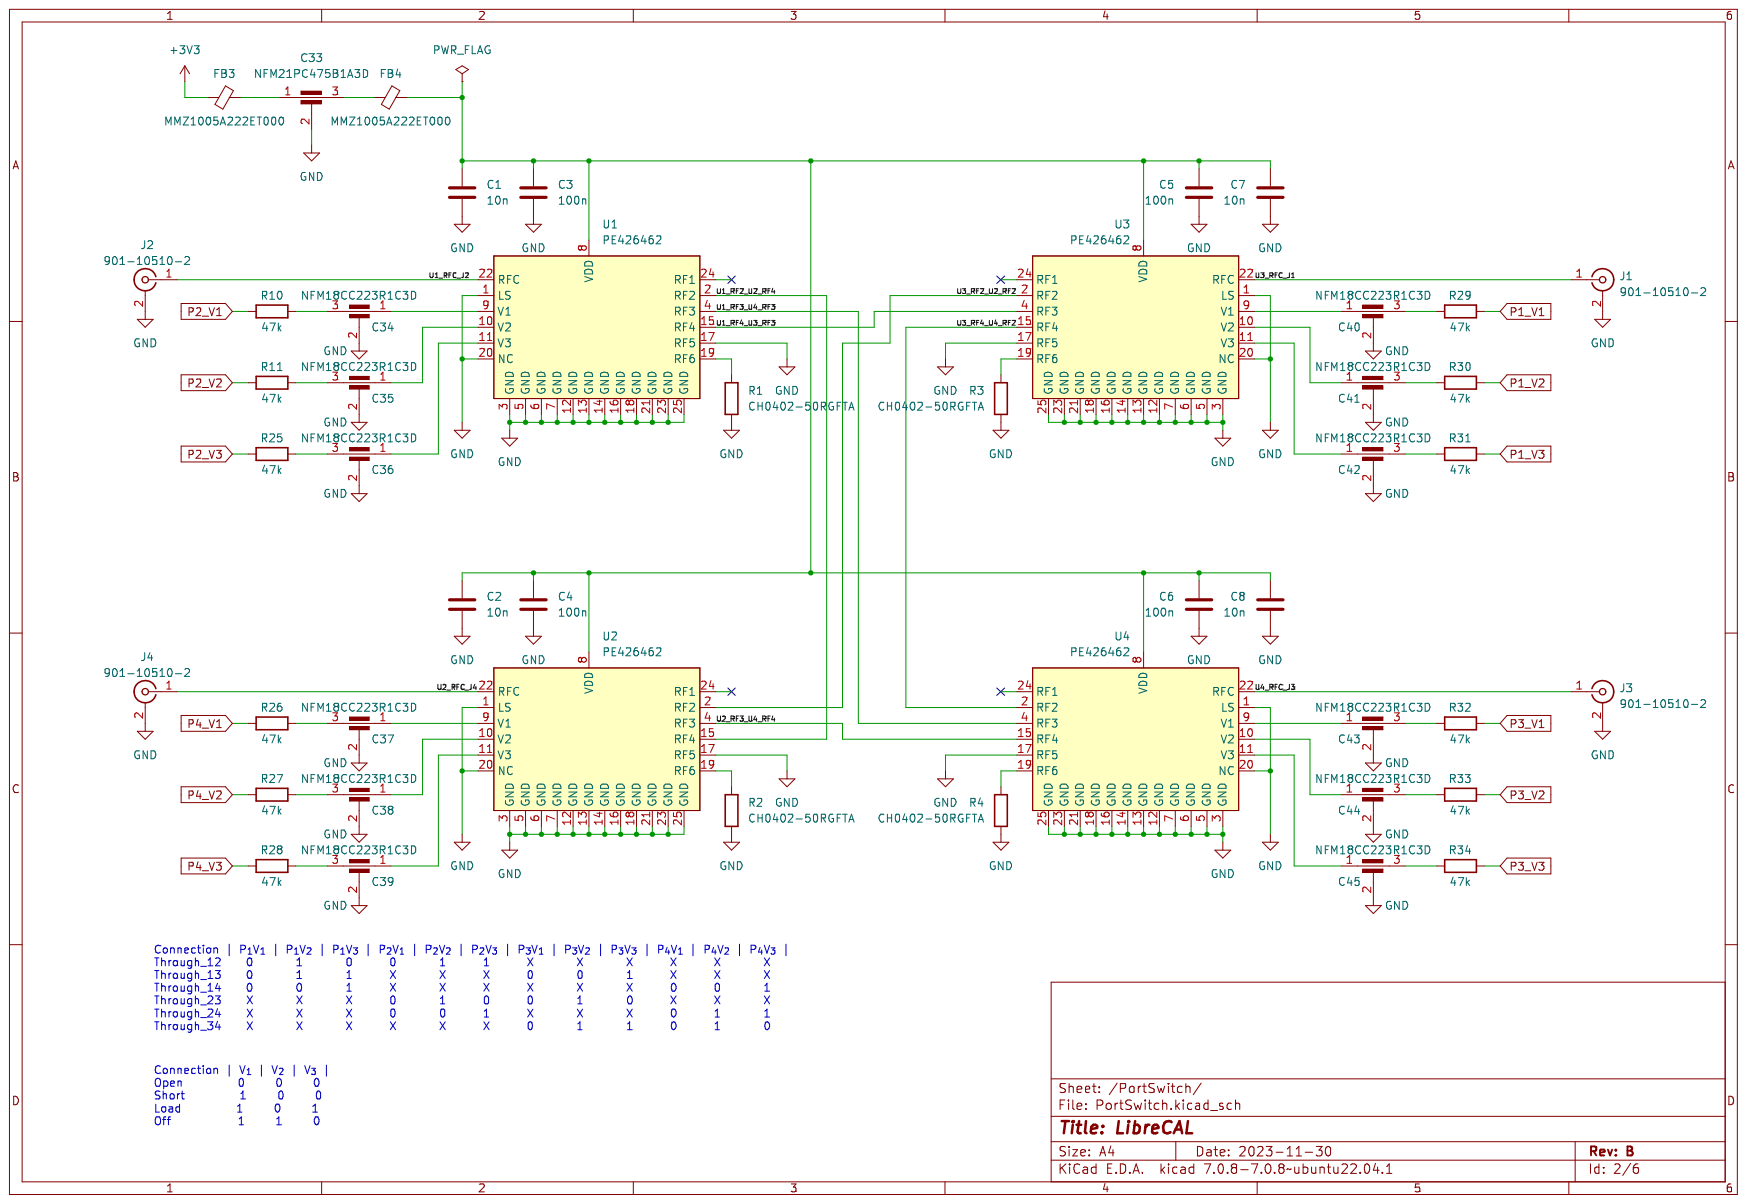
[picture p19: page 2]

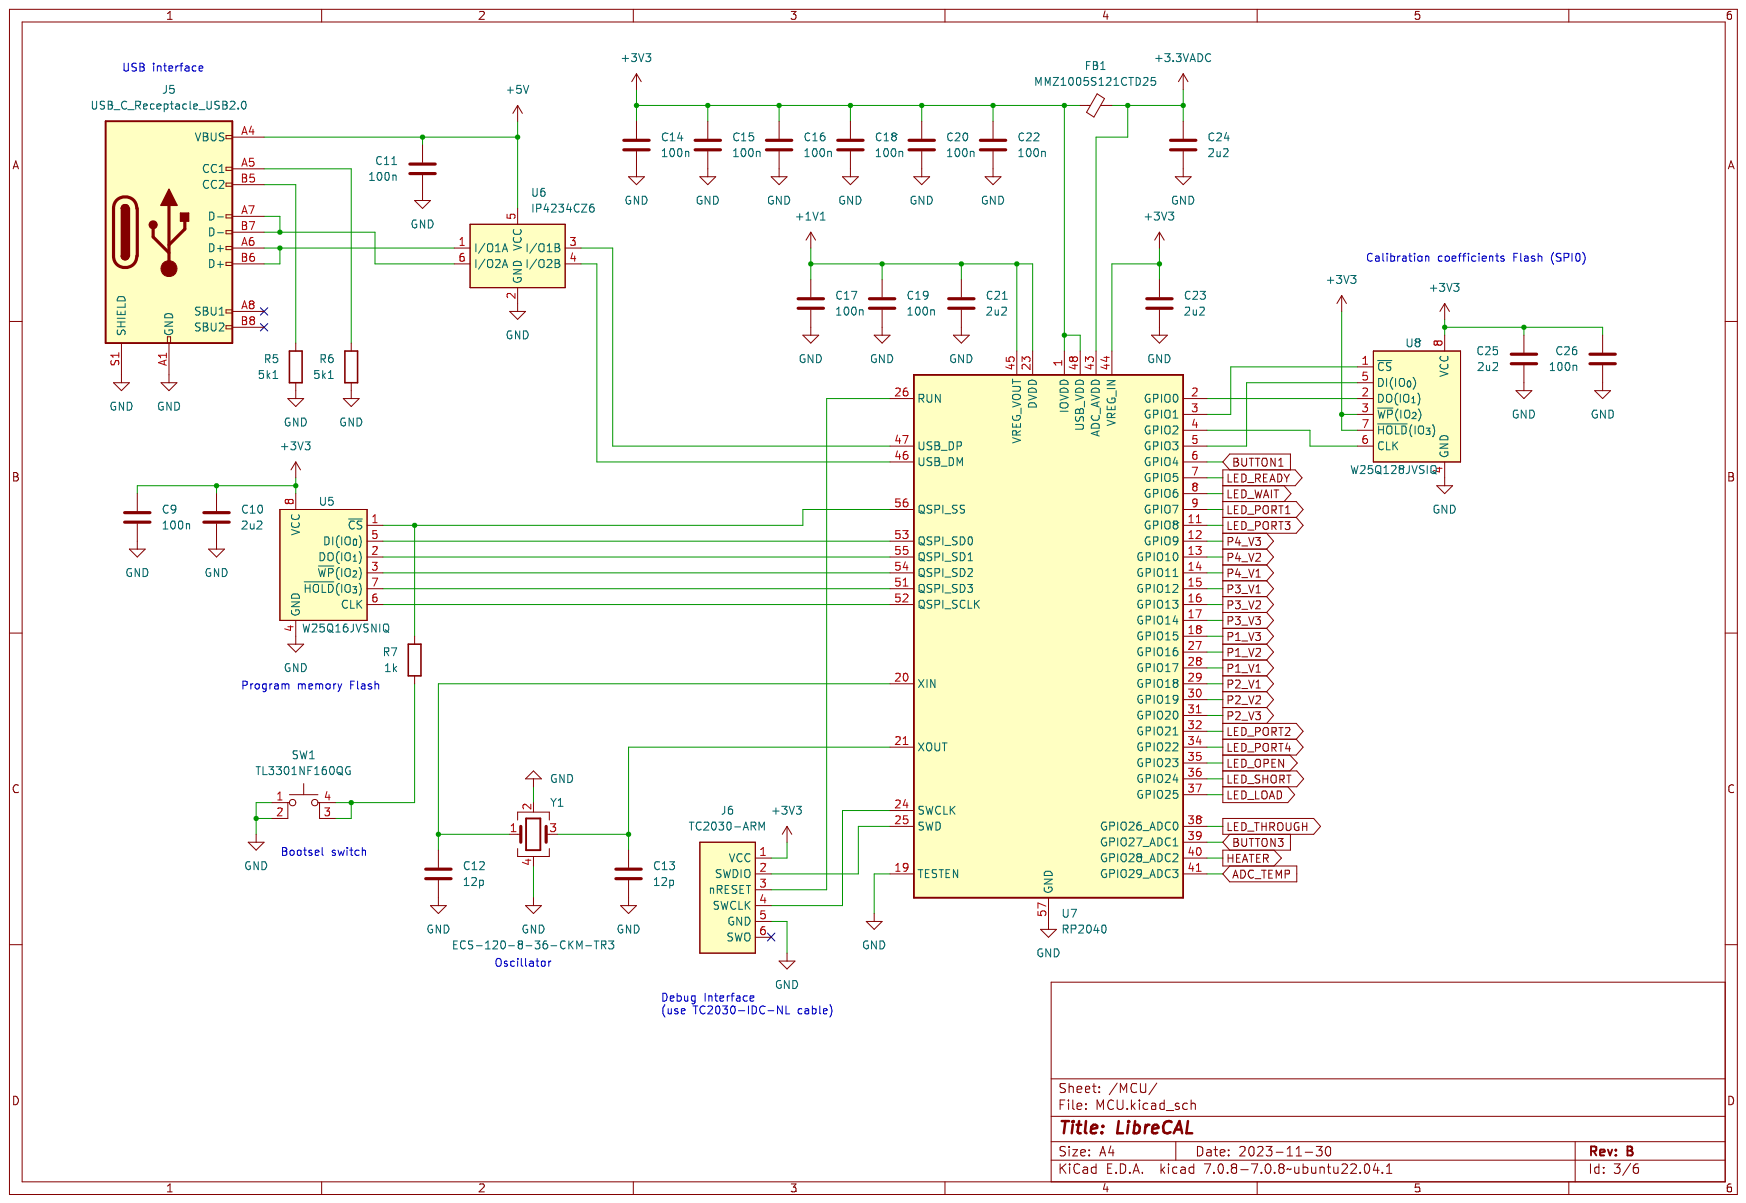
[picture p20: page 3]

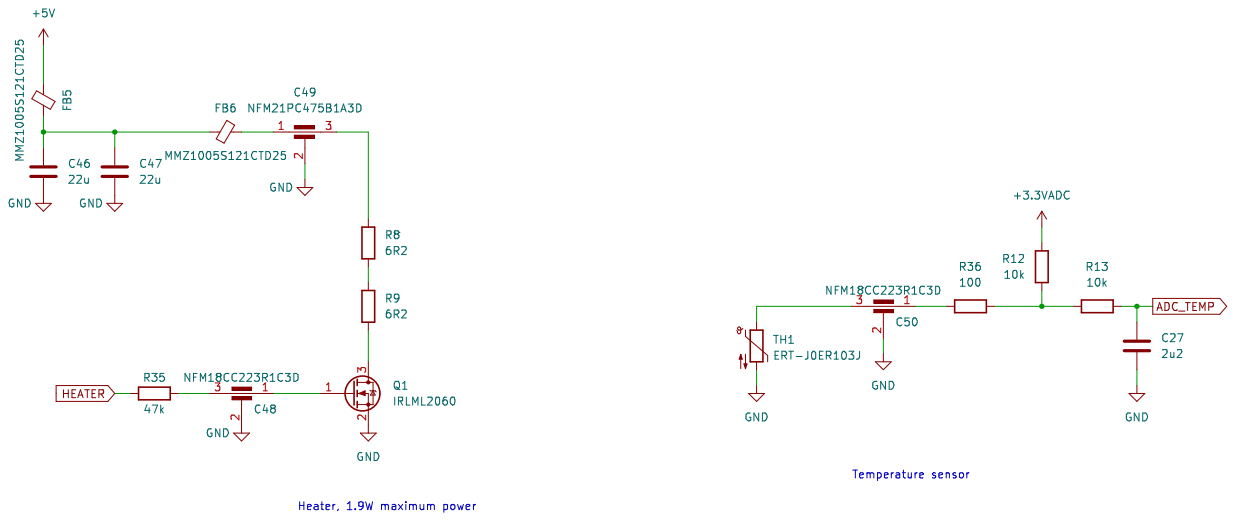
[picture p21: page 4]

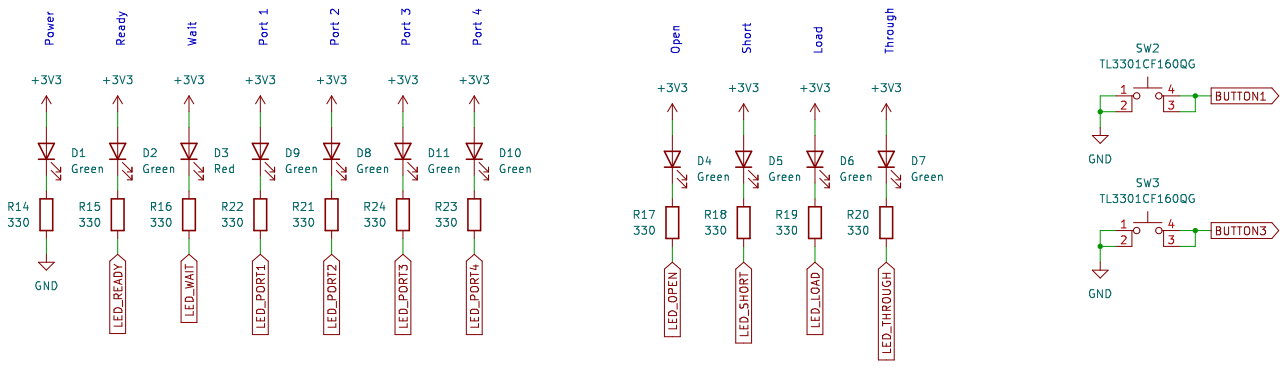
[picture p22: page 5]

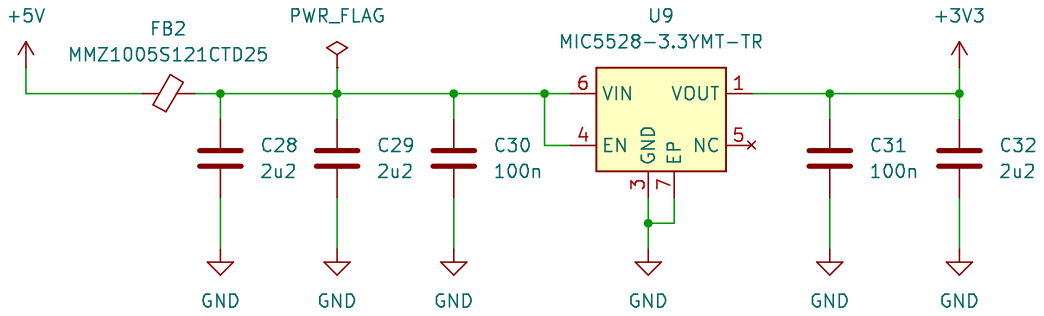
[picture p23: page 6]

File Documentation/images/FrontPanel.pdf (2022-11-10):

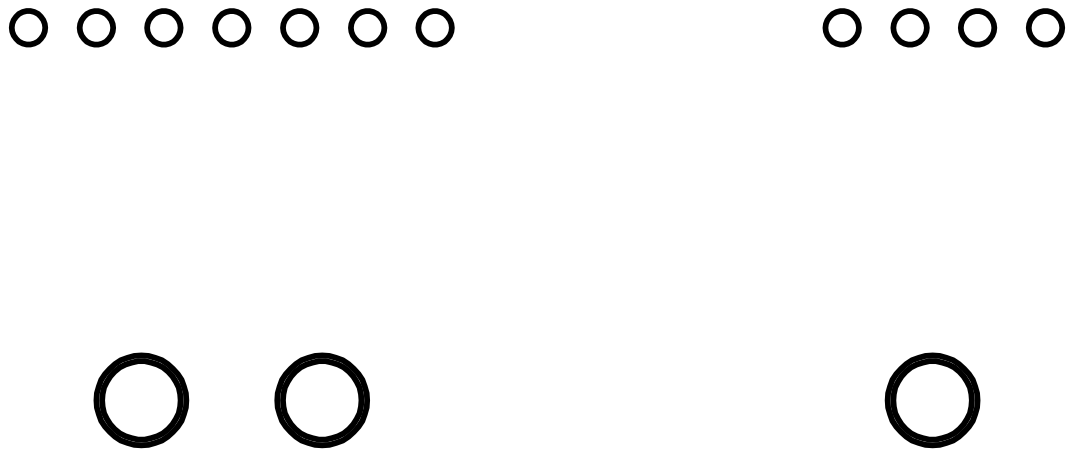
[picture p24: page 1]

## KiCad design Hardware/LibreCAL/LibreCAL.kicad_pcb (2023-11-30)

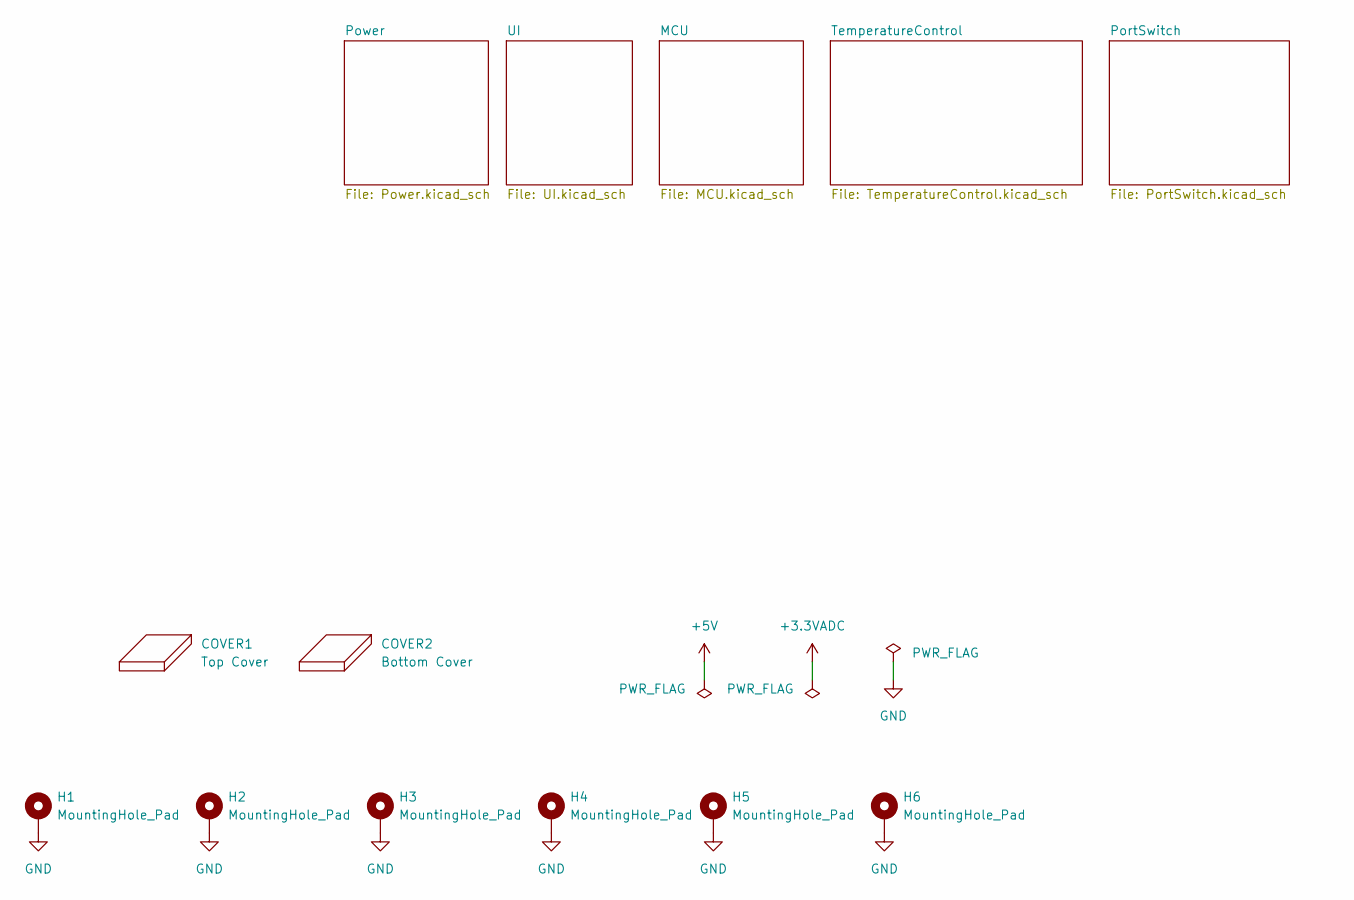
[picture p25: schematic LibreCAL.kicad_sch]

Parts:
COVER1: Top Cover; TopCover; LCSC_Part NA
COVER2: Bottom Cover; BottomCover; LCSC_Part NA
H1, H2, H3, H4, H5, H6: MountingHole_Pad; MountingHole_3.2mm_M3_ISO14580_Pad_TopBottom; LCSC_Part NA

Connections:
GND: H1.1, H2.1, H3.1, H4.1, H5.1, H6.1; also elsewhere on the board

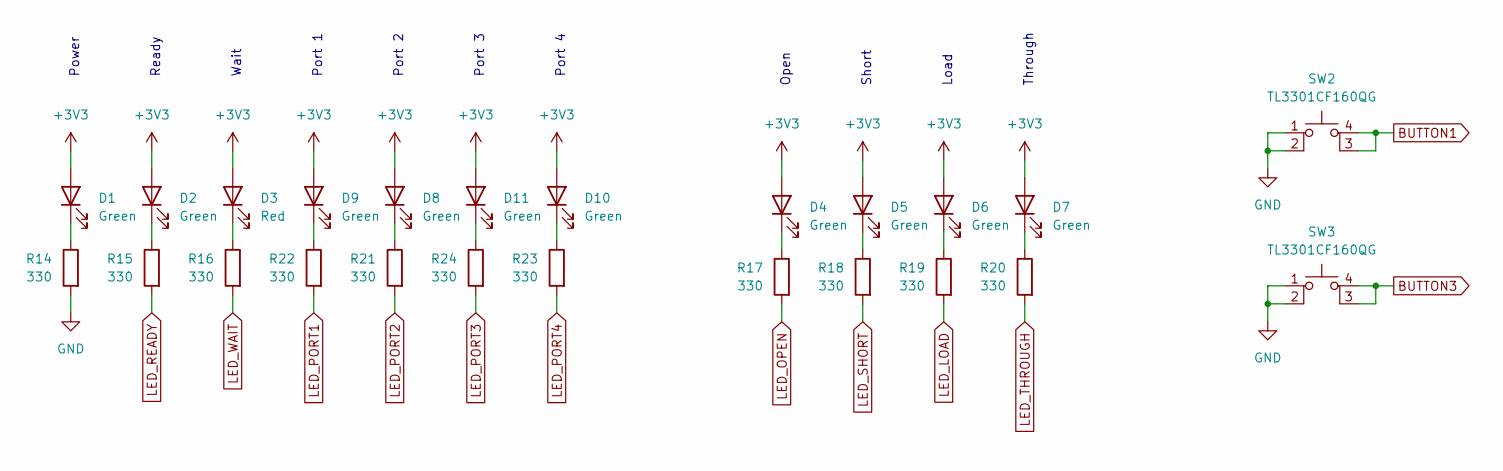
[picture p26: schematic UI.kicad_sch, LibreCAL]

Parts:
D1, D2, D4, D5, D6, D7, D8, D9, D10, D11: Green; LED_0603_1608Metric; LCSC_Part C72043
D3: Red; LED_0603_1608Metric; LCSC_Part C93128
R14, R15, R16, R17, R18, R19, R20, R21, R22, R23, R24: 330; R_0402_1005Metric; LCSC_Part C25104
SW2, SW3: TL3301CF160QG; TL3301C-J; LCSC_Part C273522

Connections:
+3V3: D1.2 (A), D2.2 (A), D3.2 (A), D4.2 (A), D5.2 (A), D6.2 (A), D7.2 (A), D8.2 (A), D9.2 (A), D10.2 (A), D11.2 (A); also elsewhere on the board
BUTTON1: SW2.3 (K), SW2.4 (A); also elsewhere on the board
BUTTON3: SW3.3 (K), SW3.4 (A); also elsewhere on the board
GND: R14.2, SW2.1, SW2.2, SW3.1, SW3.2; also elsewhere on the board
LED_LOAD: R19.2; also elsewhere on the board
LED_OPEN: R17.2; also elsewhere on the board
LED_PORT1: R22.2; also elsewhere on the board
LED_PORT2: R21.2; also elsewhere on the board
LED_PORT3: R24.2; also elsewhere on the board
LED_PORT4: R23.2; also elsewhere on the board
LED_READY: R15.2; also elsewhere on the board
LED_SHORT: R18.2; also elsewhere on the board
LED_THROUGH: R20.2; also elsewhere on the board
LED_WAIT: R16.2; also elsewhere on the board
unnamed: D1.1 (K), R14.1
unnamed: D2.1 (K), R15.1
unnamed: D3.1 (K), R16.1
unnamed: D4.1 (K), R17.1
unnamed: D5.1 (K), R18.1
unnamed: D6.1 (K), R19.1
unnamed: D7.1 (K), R20.1
unnamed: D8.1 (K), R21.1
unnamed: D9.1 (K), R22.1
unnamed: D10.1 (K), R23.1
unnamed: D11.1 (K), R24.1

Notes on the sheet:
Short
Port 3
Power
Port 1
Through
Wait
Port 2
Ready
Open
Load
Port 4

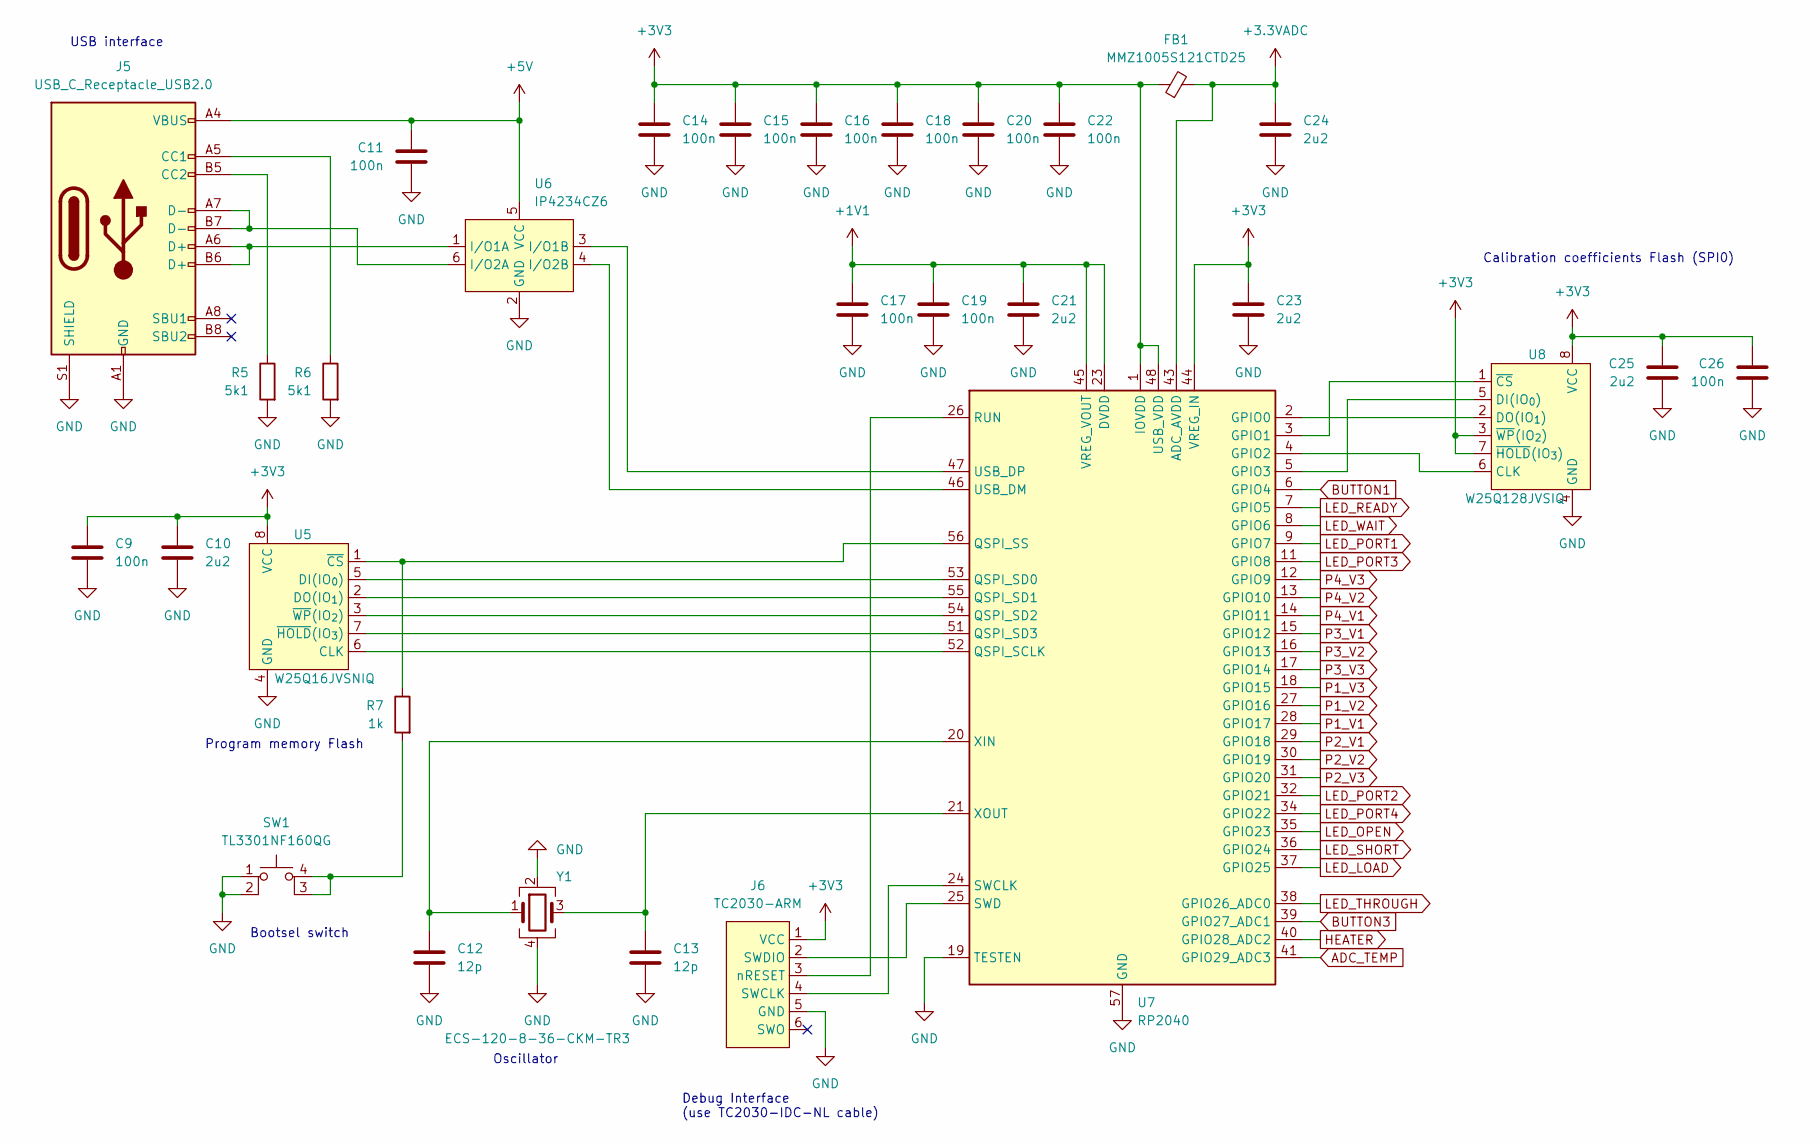
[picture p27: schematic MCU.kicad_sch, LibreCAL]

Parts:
C9, C11, C14, C15, C16, C17, C18, C19, C20, C22, C26: 100n; C_0402_1005Metric; LCSC_Part C307331
C10, C21, C23, C24, C25: 2u2; C_0402_1005Metric; LCSC_Part C307418
C12, C13: 12p; C_0402_1005Metric; LCSC_Part C76948
FB1: MMZ1005S121CTD25; L_0402_1005Metric; LCSC_Part C404693
J5: USB_C_Receptacle_USB2.0; USB_C_Receptacle_HRO_TYPE-C-31-M-12; LCSC_Part C165948
J6: TC2030-ARM; Tag-Connect_TC2030-IDC-NL_2x03_P1.27mm_Vertical; LCSC_Part NA
R5, R6: 5k1; R_0402_1005Metric; LCSC_Part C105872
R7: 1k; R_0402_1005Metric; LCSC_Part C106235
SW1: TL3301NF160QG; TL3301N-J; LCSC_Part C273527
U5: W25Q16JVSNIQ; SOIC-8_3.9x4.9mm_P1.27mm; LCSC_Part C115407
U6: IP4234CZ6; SOT-23-6; LCSC_Part C455086
U7: RP2040; LCSC_Part C2040
U8: W25Q128JVSIQ; SOIC-8_5.23x5.23mm_P1.27mm; LCSC_Part C115407
Y1: ECS-120-8-36-CKM-TR3; Crystal_SMD_2520-4Pin_2.5x2.0mm; LCSC_Part C5349079

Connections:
+1V1: C17.1, C19.1, C21.1, U7.23 (DVDD), U7.45 (VREG_VOUT), U7.50 (DVDD)
+3.3VADC: C24.1, FB1.2, U7.43 (ADC_AVDD); also elsewhere on the board
+3V3: C9.1, C10.1, C14.1, C15.1, C16.1, C18.1, C20.1, C22.1, C23.1, C25.1, C26.1, FB1.1, J6.1 (VCC), U5.8 (VCC), U7.1 (IOVDD), U7.10 (IOVDD), U7.22 (IOVDD), U7.33 (IOVDD), U7.42 (IOVDD), U7.44 (VREG_IN), U7.48 (USB_VDD), U7.49 (IOVDD), U8.3 (~WP(IO_{2})), U8.7 (~HOLD(IO_{3})), U8.8 (VCC); also elsewhere on the board
+5V: C11.1, J5.A4 (VBUS), J5.A9 (VBUS), J5.B4 (VBUS), J5.B9 (VBUS), U6.5 (VCC); also elsewhere on the board
ADC_TEMP: U7.41 (GPIO29_ADC3); also elsewhere on the board
BUTTON1: U7.6 (GPIO4); also elsewhere on the board
BUTTON3: U7.39 (GPIO27_ADC1); also elsewhere on the board
GND: C9.2, C10.2, C11.2, C12.2, C13.2, C14.2, C15.2, C16.2, C17.2, C18.2, C19.2, C20.2, C21.2, C22.2, C23.2, C24.2, C25.2, C26.2, J5.A1 (GND), J5.A12 (GND), J5.B1 (GND), J5.B12 (GND), J5.S1 (SHIELD), J6.5 (GND), R5.2, R6.2, SW1.1, SW1.2, U5.4 (GND), U6.2 (GND), U7.19 (TESTEN), U7.57 (GND), U8.4 (GND), Y1.2, Y1.4; also elsewhere on the board
HEATER: U7.40 (GPIO28_ADC2); also elsewhere on the board
LED_LOAD: U7.37 (GPIO25); also elsewhere on the board
LED_OPEN: U7.35 (GPIO23); also elsewhere on the board
LED_PORT1: U7.9 (GPIO7); also elsewhere on the board
LED_PORT2: U7.32 (GPIO21); also elsewhere on the board
LED_PORT3: U7.11 (GPIO8); also elsewhere on the board
LED_PORT4: U7.34 (GPIO22); also elsewhere on the board
LED_READY: U7.7 (GPIO5); also elsewhere on the board
LED_SHORT: U7.36 (GPIO24); also elsewhere on the board
LED_THROUGH: U7.38 (GPIO26_ADC0); also elsewhere on the board
LED_WAIT: U7.8 (GPIO6); also elsewhere on the board
unnamed: J5.A5 (CC1), R6.1
unnamed: J5.B5 (CC2), R5.1
unnamed: J6.4 (SWCLK), U7.24 (SWCLK)
unnamed: J6.2 (SWDIO), U7.25 (SWD)
unnamed: J6.3 (nRESET), U7.26 (RUN)
unnamed: R7.2, SW1.3 (K), SW1.4 (A)
unnamed: U5.6 (CLK), U7.52 (QSPI_SCLK)
unnamed: U5.5 (DI(IO_{0})), U7.53 (QSPI_SD0)
unnamed: U5.2 (DO(IO_{1})), U7.55 (QSPI_SD1)
unnamed: R7.1, U5.1 (~CS), U7.56 (QSPI_SS)
unnamed: U5.7 (~HOLD(IO_{3})), U7.51 (QSPI_SD3)
unnamed: U5.3 (~WP(IO_{2})), U7.54 (QSPI_SD2)
unnamed: J5.A6 (D+), J5.B6 (D+), U6.1 (I/O1A)
unnamed: U6.3 (I/O1B), U7.47 (USB_DP)
unnamed: J5.A7 (D-), J5.B7 (D-), U6.6 (I/O2A)
unnamed: U6.4 (I/O2B), U7.46 (USB_DM)
unnamed: U7.2 (GPIO0), U8.2 (DO(IO_{1}))
unnamed: U7.3 (GPIO1), U8.1 (~CS)
unnamed: U7.4 (GPIO2), U8.6 (CLK)
unnamed: U7.5 (GPIO3), U8.5 (DI(IO_{0}))
unnamed: C12.1, U7.20 (XIN), Y1.1
unnamed: C13.1, U7.21 (XOUT), Y1.3
P1_V1: U7.28 (GPIO17); also elsewhere on the board
P1_V2: U7.27 (GPIO16); also elsewhere on the board
P1_V3: U7.18 (GPIO15); also elsewhere on the board
P2_V1: U7.29 (GPIO18); also elsewhere on the board
P2_V2: U7.30 (GPIO19); also elsewhere on the board
P2_V3: U7.31 (GPIO20); also elsewhere on the board
P3_V1: U7.15 (GPIO12); also elsewhere on the board
P3_V2: U7.16 (GPIO13); also elsewhere on the board
P3_V3: U7.17 (GPIO14); also elsewhere on the board
P4_V1: U7.14 (GPIO11); also elsewhere on the board
P4_V2: U7.13 (GPIO10); also elsewhere on the board
P4_V3: U7.12 (GPIO9); also elsewhere on the board

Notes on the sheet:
USB interface
Oscillator
Program memory Flash
Debug Interface (use TC2030-IDC-NL cable)
Bootsel switch
Calibration coefficients Flash (SPI0)

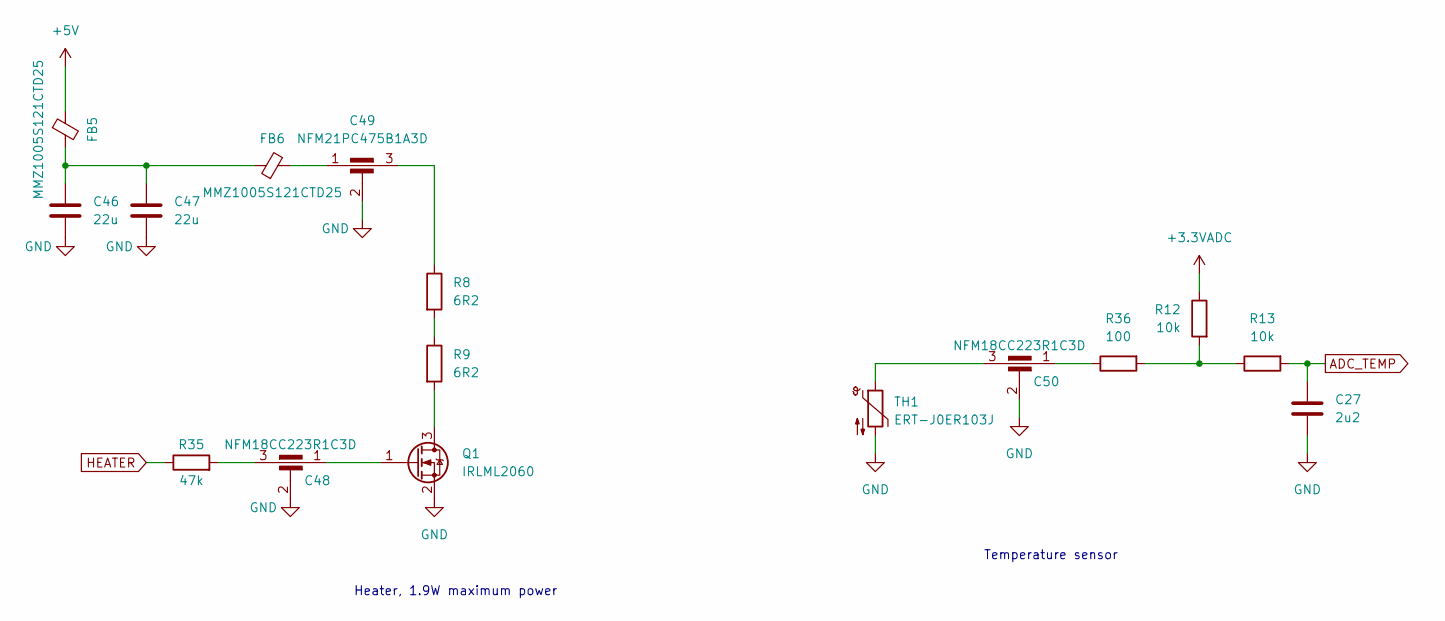
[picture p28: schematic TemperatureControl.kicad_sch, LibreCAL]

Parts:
C27: 2u2; C_0402_1005Metric; LCSC_Part C307418
C46, C47: 22u; C_0805_2012Metric; LCSC_Part C45783
C48, C50: NFM18CC223R1C3D; NFM18CC; LCSC_Part C98102
C49: NFM21PC475B1A3D; NFM21PC; LCSC_Part C96293
FB5, FB6: MMZ1005S121CTD25; L_0402_1005Metric; LCSC_Part C404693
Q1: IRLML2060; SOT-23; LCSC_Part C67275
R8, R9: 6R2; R_2512_6332Metric; LCSC_Part C147196
R12, R13: 10k; R_0402_1005Metric; LCSC_Part C723353
R35: 47k; R_0402_1005Metric; LCSC_Part C144757
R36: 100; R_0402_1005Metric; LCSC_Part C25076
TH1: ERT-J0ER103J; R_0402_1005Metric; LCSC_Part C153027

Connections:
+3.3VADC: R12.1; also elsewhere on the board
+5V: FB5.1; also elsewhere on the board
ADC_TEMP: C27.1, R13.2; also elsewhere on the board
GND: C27.2, C46.2, C47.2, C48.2, C49.2, C50.2, Q1.2 (S), TH1.2; also elsewhere on the board
HEATER: R35.1; also elsewhere on the board
unnamed: C46.1, C47.1, FB5.2, FB6.1
unnamed: C48.3, R35.2
unnamed: C49.1, FB6.2
unnamed: C49.3, R8.1
unnamed: C50.1, R36.1
unnamed: C50.3, TH1.1
unnamed: Q1.3 (D), R9.2
unnamed: C48.1, Q1.1 (G)
unnamed: R8.2, R9.1
unnamed: R12.2, R13.1, R36.2

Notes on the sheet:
Temperature sensor
Heater, 1.9W maximum power

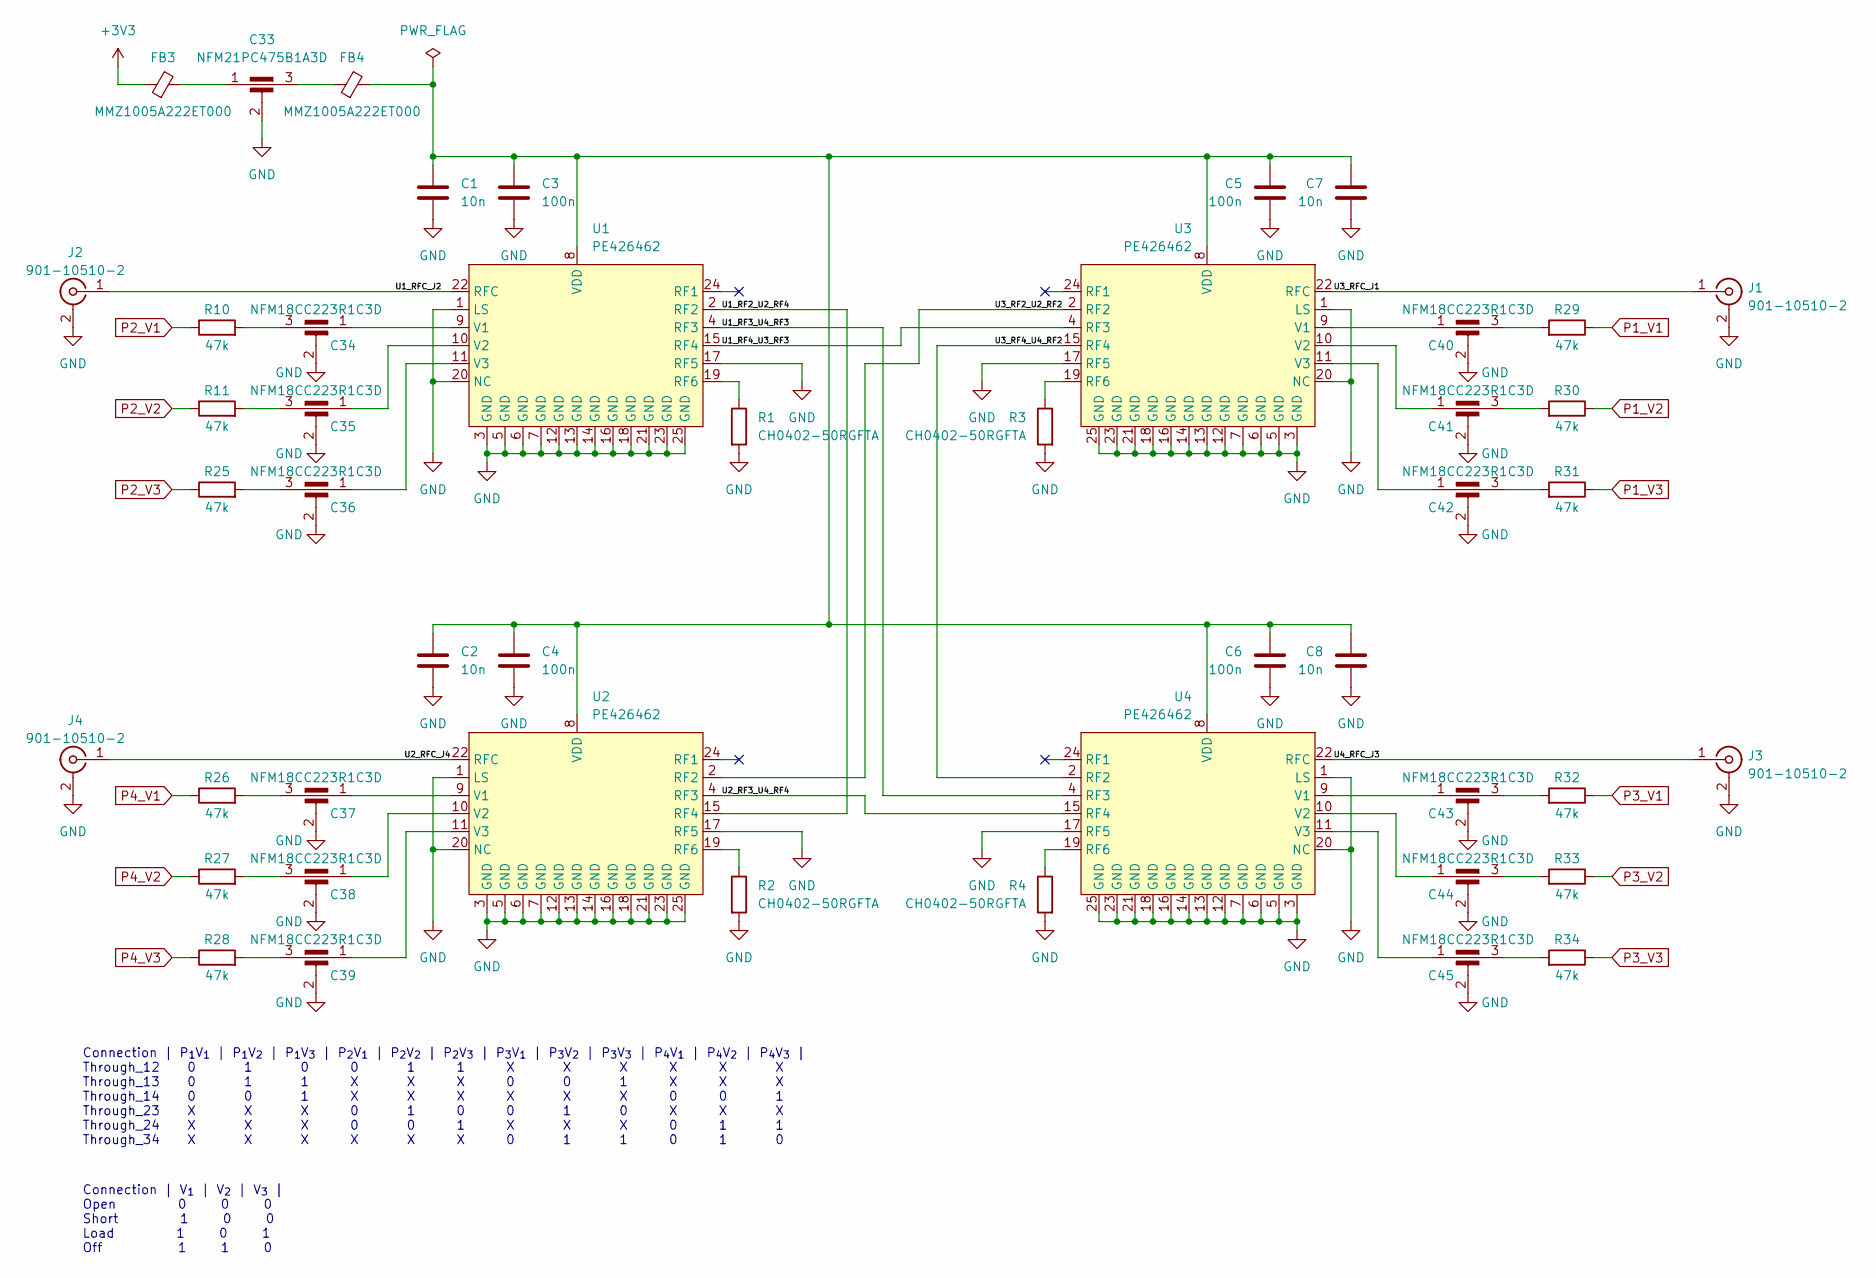
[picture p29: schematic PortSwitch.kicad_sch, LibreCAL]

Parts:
C1, C2, C7, C8: 10n; C_0402_1005Metric; LCSC_Part C15195
C3, C4, C5, C6: 100n; C_0402_1005Metric; LCSC_Part C307331
C33: NFM21PC475B1A3D; NFM21PC; LCSC_Part C96293
C34, C35, C36, C37, C38, C39, C40, C41, C42, C43, C44, C45: NFM18CC223R1C3D; NFM18CC; LCSC_Part C98102
FB3, FB4: MMZ1005A222ET000; L_0402_1005Metric; LCSC_Part C275411
J1, J2, J3, J4: 901-10510-2; LCSC_Part C3172623
R1, R2, R3, R4: CH0402-50RGFTA; R_0402_1005Metric; LCSC_Part C5349731
R10, R11, R25, R26, R27, R28, R29, R30, R31, R32, R33, R34: 47k; R_0402_1005Metric; LCSC_Part C144757
U1, U2, U3, U4: PE426462; QFN-24-1EP_4x4mm_P0.5mm_EP2.7x2.7mm; LCSC_Part C5349078

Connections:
+3V3: FB3.1; also elsewhere on the board
/PortSwitch/U1_RF2_U2_RF4: U1.2 (RF2), U2.15 (RF4)
/PortSwitch/U1_RF3_U4_RF3: U1.4 (RF3), U4.4 (RF3)
/PortSwitch/U1_RF4_U3_RF3: U1.15 (RF4), U3.4 (RF3)
/PortSwitch/U1_RFC_J2: J2.1 (In), U1.22 (RFC)
/PortSwitch/U2_RF3_U4_RF4: U2.4 (RF3), U4.15 (RF4)
/PortSwitch/U2_RFC_J4: J4.1 (In), U2.22 (RFC)
/PortSwitch/U3_RF2_U2_RF2: U2.2 (RF2), U3.2 (RF2)
/PortSwitch/U3_RF4_U4_RF2: U3.15 (RF4), U4.2 (RF2)
/PortSwitch/U3_RFC_J1: J1.1 (In), U3.22 (RFC)
/PortSwitch/U4_RFC_J3: J3.1 (In), U4.22 (RFC)
GND: C1.2, C2.2, C3.2, C4.2, C5.2, C6.2, C7.2, C8.2, C33.2, C34.2, C35.2, C36.2, C37.2, C38.2, C39.2, C40.2, C41.2, C42.2, C43.2, C44.2, C45.2, J1.2 (Ext), J1.3 (Ext), J1.4 (Ext), J1.5 (Ext), J1.6 (Ext), J1.7 (Ext), J2.2 (Ext), J2.3 (Ext), J2.4 (Ext), J2.5 (Ext), J2.6 (Ext), J2.7 (Ext), J3.2 (Ext), J3.3 (Ext), J3.4 (Ext), J3.5 (Ext), J3.6 (Ext), J3.7 (Ext), J4.2 (Ext), J4.3 (Ext), J4.4 (Ext), J4.5 (Ext), J4.6 (Ext), J4.7 (Ext), R1.2, R2.2, R3.2, R4.2, U1.1 (LS), U1.3 (GND), U1.5 (GND), U1.6 (GND), U1.7 (GND), U1.12 (GND), U1.13 (GND), U1.14 (GND), U1.16 (GND), U1.17 (RF5), U1.18 (GND), U1.20 (NC), U1.21 (GND), U1.23 (GND), U1.25 (GND), U2.1 (LS), U2.3 (GND), U2.5 (GND), U2.6 (GND), U2.7 (GND), U2.12 (GND), U2.13 (GND), U2.14 (GND), U2.16 (GND), U2.17 (RF5), U2.18 (GND), U2.20 (NC), U2.21 (GND), U2.23 (GND), U2.25 (GND), U3.1 (LS), U3.3 (GND), U3.5 (GND), U3.6 (GND), U3.7 (GND), U3.12 (GND), U3.13 (GND), U3.14 (GND), U3.16 (GND), U3.17 (RF5), U3.18 (GND), U3.20 (NC), U3.21 (GND), U3.23 (GND), U3.25 (GND), U4.1 (LS), U4.3 (GND), U4.5 (GND), U4.6 (GND), U4.7 (GND), U4.12 (GND), U4.13 (GND), U4.14 (GND), U4.16 (GND), U4.17 (RF5), U4.18 (GND), U4.20 (NC), U4.21 (GND), U4.23 (GND), U4.25 (GND); also elsewhere on the board
unnamed: C33.1, FB3.2
unnamed: C33.3, FB4.1
unnamed: C34.3, R10.2
unnamed: C35.3, R11.2
unnamed: C36.3, R25.2
unnamed: C37.3, R26.2
unnamed: C38.3, R27.2
unnamed: C39.3, R28.2
unnamed: C40.3, R29.2
unnamed: C41.3, R30.2
unnamed: C42.3, R31.2
unnamed: C43.3, R32.2
unnamed: C44.3, R33.2
unnamed: C45.3, R34.2
unnamed: R1.1, U1.19 (RF6)
unnamed: C34.1, U1.9 (V1)
unnamed: C35.1, U1.10 (V2)
unnamed: C36.1, U1.11 (V3)
unnamed: C1.1, C2.1, C3.1, C4.1, C5.1, C6.1, C7.1, C8.1, FB4.2, U1.8 (VDD), U2.8 (VDD), U3.8 (VDD), U4.8 (VDD)
unnamed: R2.1, U2.19 (RF6)
unnamed: C37.1, U2.9 (V1)
unnamed: C38.1, U2.10 (V2)
unnamed: C39.1, U2.11 (V3)
unnamed: R3.1, U3.19 (RF6)
unnamed: C40.1, U3.9 (V1)
unnamed: C41.1, U3.10 (V2)
unnamed: C42.1, U3.11 (V3)
unnamed: R4.1, U4.19 (RF6)
unnamed: C43.1, U4.9 (V1)
unnamed: C44.1, U4.10 (V2)
unnamed: C45.1, U4.11 (V3)
P1_V1: R29.1; also elsewhere on the board
P1_V2: R30.1; also elsewhere on the board
P1_V3: R31.1; also elsewhere on the board
P2_V1: R10.1; also elsewhere on the board
P2_V2: R11.1; also elsewhere on the board
P2_V3: R25.1; also elsewhere on the board
P3_V1: R32.1; also elsewhere on the board
P3_V2: R33.1; also elsewhere on the board
P3_V3: R34.1; also elsewhere on the board
P4_V1: R26.1; also elsewhere on the board
P4_V2: R27.1; also elsewhere on the board
P4_V3: R28.1; also elsewhere on the board

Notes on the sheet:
Connection | P_{1}V_{1} | P_{1}V_{2} | P_{1}V_{3} | P_{2}V_{1} | P_{2}V_{2} | P_{2}V_{3} | P_{3}V_{1} | P_{3}V_{2} | P_{3}V_{3} | P_{4}V_{1} | P_{4}V_{2} | P_{4}V_{3} | Through_12 0 1 0 0 1 1 X X X X X X Through_13 0 1 1 X X X 0 0 1 X X X Through_14 0 0 1 X X X X X X 0 0 1 Through_23 X X X 0 1 0 0 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
Connection | V_{1} | V_{2} | V_{3} | Open 0 0 0 Short 1 0 0 Load 1 0 1 Off 1 1 0

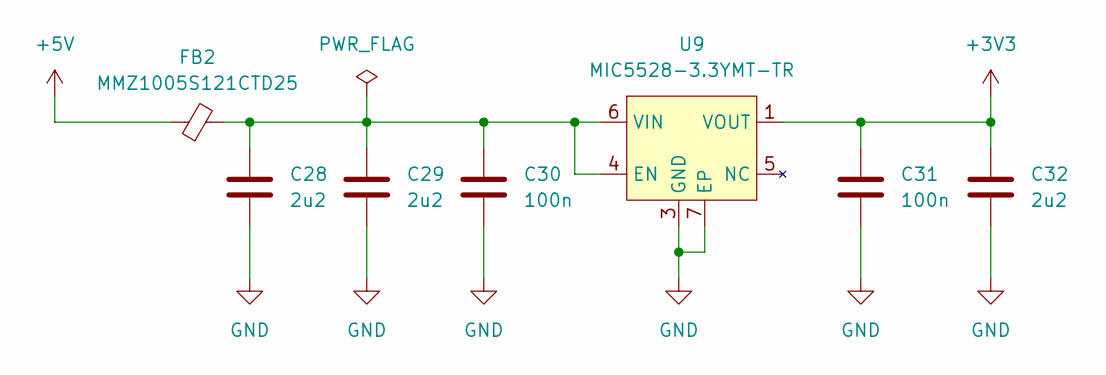
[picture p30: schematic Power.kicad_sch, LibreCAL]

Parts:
C28, C29, C32: 2u2; C_0402_1005Metric; LCSC_Part C307418
C30, C31: 100n; C_0402_1005Metric; LCSC_Part C307331
FB2: MMZ1005S121CTD25; L_0402_1005Metric; LCSC_Part C404693
U9: MIC5528-3.3YMT-TR; DFN-6-1EP_1.2x1.2mm_P0.4mm_EP0.3x0.94mm; LCSC_Part C622490

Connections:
+3V3: C31.1, C32.1, U9.1 (VOUT), U9.2 (VOUT); also elsewhere on the board
+5V: FB2.1; also elsewhere on the board
GND: C28.2, C29.2, C30.2, C31.2, C32.2, U9.3 (GND), U9.7 (EP); also elsewhere on the board
unnamed: C28.1, C29.1, C30.1, FB2.2, U9.4 (EN), U9.6 (VIN)

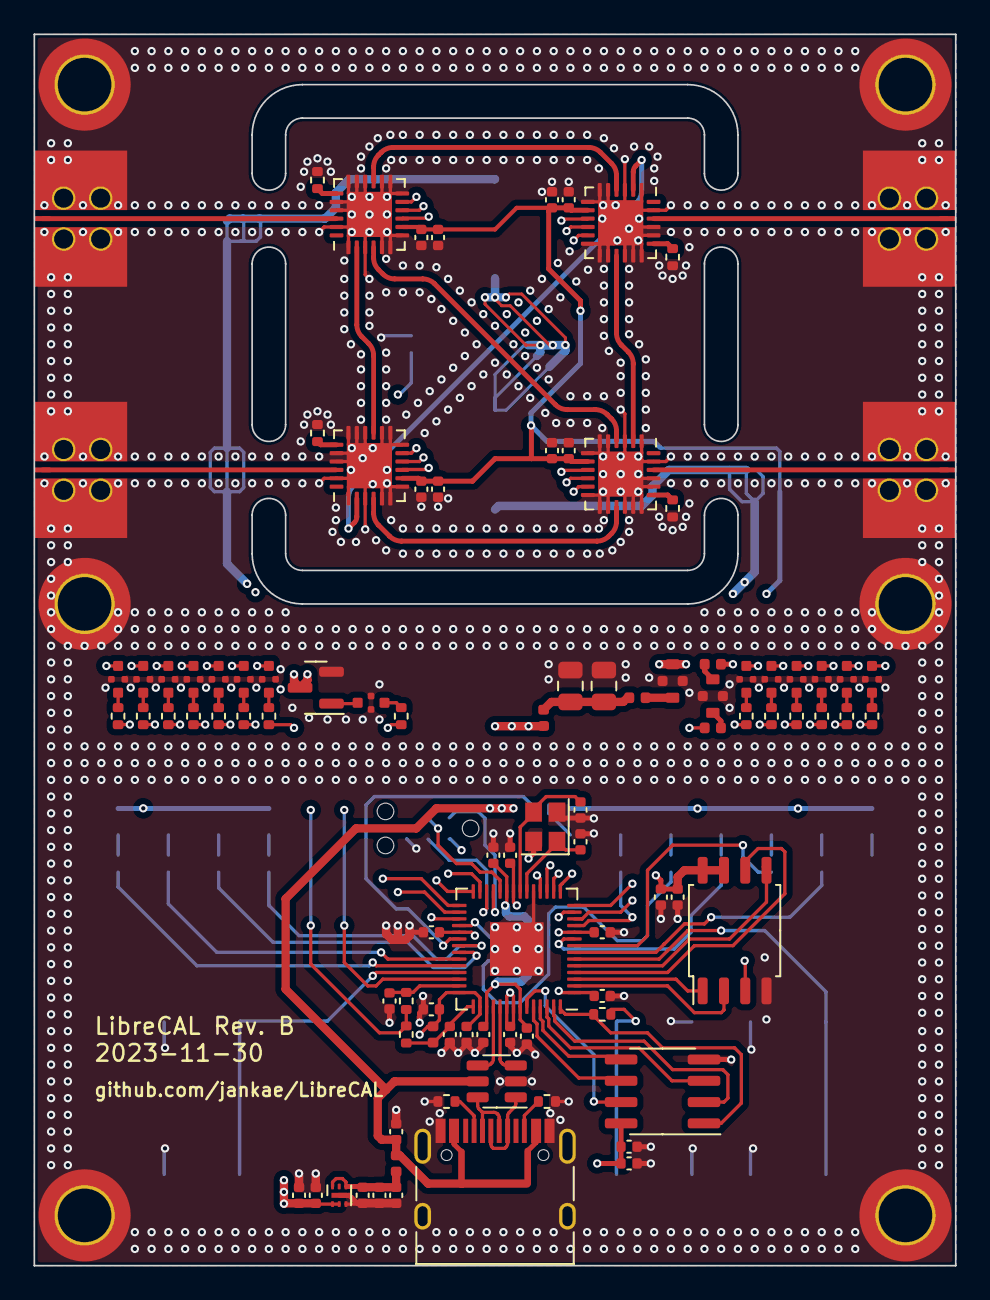
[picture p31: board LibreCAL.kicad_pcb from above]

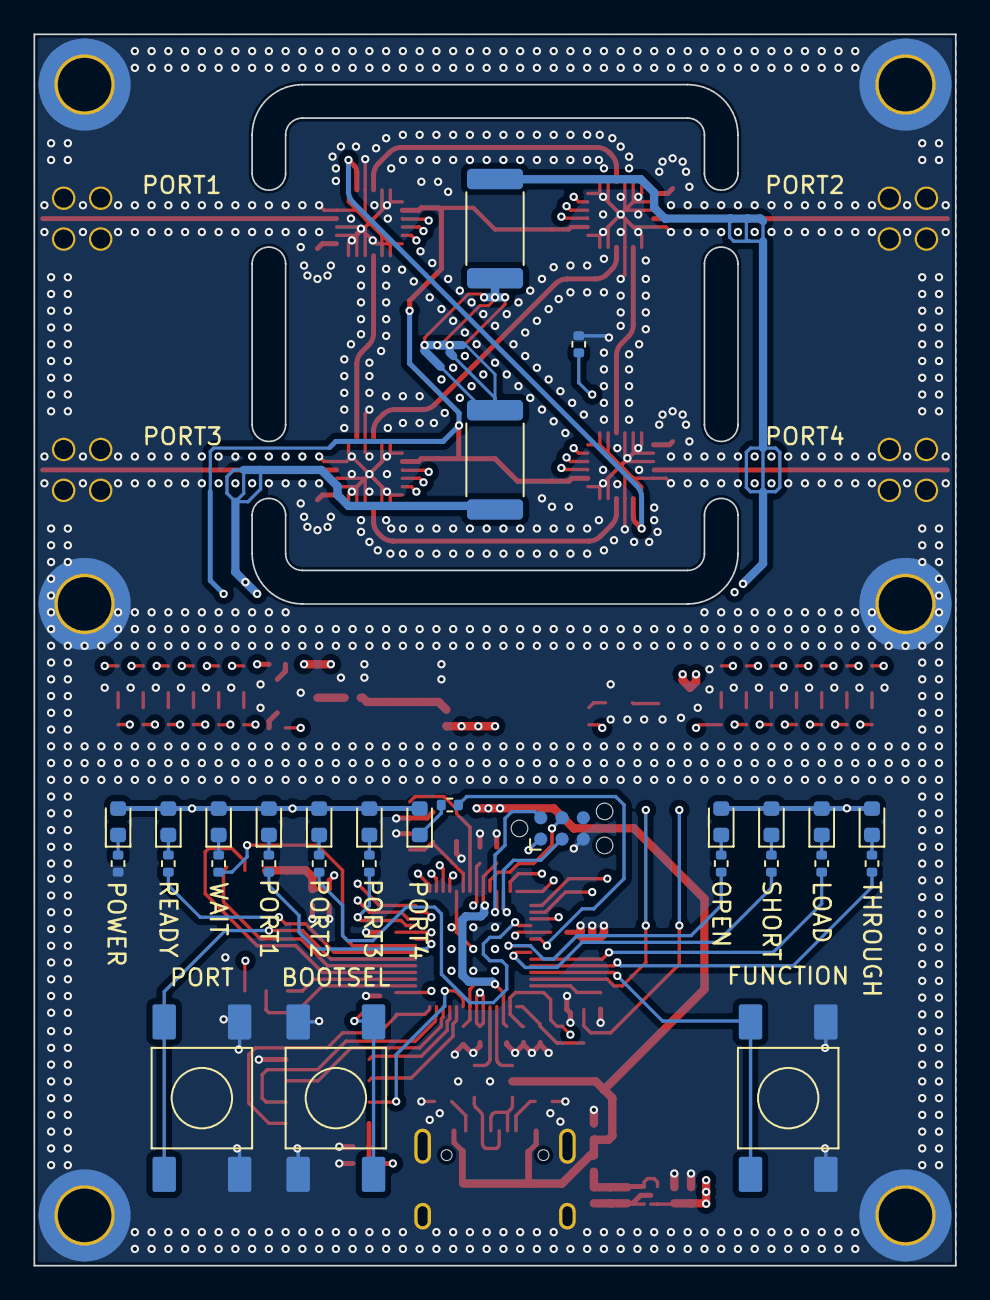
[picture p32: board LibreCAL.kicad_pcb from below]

Board: 4 copper layers, 55.0 x 73.5 mm, 132 parts (30 on the bottom side), 116 nets.

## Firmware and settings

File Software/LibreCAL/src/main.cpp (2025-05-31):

#include <ff.h>
#include <main.h>
#include <main.h>
#include <serial.h>
#include <usb.h>
#include <cstdio>
#include <cstring>

#include "pico/stdlib.h"
#include "pico/unique_id.h"
#include "hardware/spi.h"
#include "hardware/rtc.h"

#include "FreeRTOS.h"
#include "task.h"

#include "Switch.hpp"
#include "SCPI.hpp"
#include "Flash.hpp"
#include "UserInterface.hpp"
#include "Heater.hpp"

#define LOG_LEVEL	LOG_LEVEL_INFO
#define LOG_MODULE	"App"
#include "Log.h"

const char* date = __DATE__;
const char* time = __TIME__;

#define YEAR(date)  (date[7] == '?' ? 0 : ((date[7] - '0') * 1000) + \
					 (date[8] - '0') * 100 + (date[9] - '0') * 10 + \
					 (date[10] - '0'))

#define MONTH(date) (date[2] == 'n' ? (date [1] == 'a' ? 1 : 6) \
					: date[2] == 'b' ? 2 \
					: date[2] == 'r' ? (date [0] == 'M' ? 3 : 4) \
					: date[2] == 'y' ? 5 \
					: date[2] == 'l' ? 7 \
					: date[2] == 'g' ? 8 \
					: date[2] == 'p' ? 9 \
					: date[2] == 't' ? 10 \
					: date[2] == 'v' ? 11 : 12)

#define DAY(date)   ((date[4] == ' ' ? 0 : (date[4] - '0') * 10) + (date[5] - '0'))
#define HOUR(time)  ((time[0] - '0') * 10 + (time[1] - '0'))
#define MINUTE(time) ((time[3] - '0') * 10 + (time[4] - '0'))
#define SECOND(time) ((time[6] - '0') * 10 + (time[7] - '0'))


#define LED_PIN   		25
#define FLASH_CLK_PIN	2
#define FLASH_MISO_PIN	0
#define FLASH_MOSI_PIN	3
#define FLASH_CS_PIN	1

FATFS fs0, fs1;
FIL fil;
FRESULT fr;

static char usb_buffer[256];
static uint16_t usb_len;
static usb_interface_t usb_interface;
static xTaskHandle handle;

Flash flash(spi0, FLASH_CLK_PIN, FLASH_MOSI_PIN, FLASH_MISO_PIN, FLASH_CS_PIN);

static ecal_usb_mode_t mode = MODE_DEFAULT;

ecal_usb_mode_t getUsbMode() {
	return mode;
}

static void usb_rx(const uint8_t *buf, uint16_t len, usb_interface_t i) {
	if(len > sizeof(usb_buffer)) {
		// line too long
		return;
	}
	memcpy(usb_buffer, buf, len);
	usb_len = len;
	usb_interface = i;
	xTaskNotify(handle, 0x00, eNoAction);
}

bool createInfoFile() {
	/* Create a file as new */
	fr = f_open(&fil, "1:info.txt", FA_CREATE_ALWAYS | FA_WRITE);
	if (fr) {
//    	printf("f_open: %d\r\n", fr);
		return false;
	}

	/* Write a message */
	UINT bw;
	f_printf(&fil, "Serial: ");
	f_write(&fil, getSerial(), strlen(getSerial()), &bw);
	f_printf(&fil, "\r\nFirmware: %d.%d.%d\r\n", FW_MAJOR, FW_MINOR, FW_PATCH);
	f_printf(&fil, "Number of populated ports: %d", 4);
	/* Close the file */
	f_close(&fil);
	return true;
}

static void defaultTask(void* ptr) {
	handle = xTaskGetCurrentTaskHandle();

	fr = f_mount(&fs0, "0:", 1);
	if(fr != FR_OK) {
		BYTE work[FF_MAX_SS];
		f_mkfs("0:", 0, work, sizeof(work));
		f_mount(&fs0, "0:", 1);
		f_setlabel("0:LibreCAL_RW");
	}
	fr = f_mount(&fs1, "1:", 1);
	if(fr != FR_OK) {
		BYTE work[FF_MAX_SS];
		f_mkfs("1:", 0, work, sizeof(work));
		f_mount(&fs1, "1:", 1);
		f_setlabel("1:LibreCAL_R");
	}
	// Check info file
	fr = f_open(&fil, "1:info.txt", FA_OPEN_EXISTING | FA_READ);
	if (fr) {
		// failed to open, probably does not exist
		createInfoFile();
	} else {
		bool correctFirmware = false;
		char line[128];
		while(f_gets(line, sizeof(line), &fil)) {
			int major, minor, patch;
			if(sscanf(line, "Firmware: %d.%d.%d", &major, &minor, &patch) == 3) {
				// check firmware
				if(major == FW_MAJOR && minor == FW_MINOR && patch == FW_PATCH) {
					correctFirmware = true;
				}
				break;
			}
		}
		if(!correctFirmware) {
			f_close(&fil);
			createInfoFile();
		}
	}
	
	// Figure out which mode we should be in. The default mode is the normal LibreCAL mode.
	// You can always force that mode by pressing the function button when power is applied.
	// If that button is not pressed, the LibreCAL may emulate other electronic calibration
	// units it the necessary files are available
	if(UserInterface::IsFunctionHeld()) {
		mode = MODE_DEFAULT;
	} else {
		// default mode is not forced, check files
		if(!f_open(&fil, "0:siglent/info.dat", FA_OPEN_EXISTING | FA_READ)) {
			// we have data in Siglent format
			mode = MODE_SIGLENT;
			f_close(&fil);
		}
	}

	usb_init(usb_rx);

	while(true) {
		uint32_t notification;
		if(xTaskNotifyWait(0, 0, &notification, portMAX_DELAY)) {
			SCPI::Input(usb_buffer, usb_len, usb_interface);
		}
	}
}

static TaskHandle_t main_task;

int main(void) {
#ifdef ENABLE_UART
	Log_Init();
	LOG_INFO("Start");
#endif
	spi_init(spi0, 20000 * 1000);
	gpio_set_function(FLASH_CLK_PIN, GPIO_FUNC_SPI);
	gpio_set_function(FLASH_MOSI_PIN, GPIO_FUNC_SPI);
	gpio_set_function(FLASH_MISO_PIN, GPIO_FUNC_SPI);
	gpio_init(FLASH_CS_PIN);
	gpio_set_dir(FLASH_CS_PIN, GPIO_OUT);
	gpio_put(FLASH_CS_PIN, true);

	// For default Date / Time use the preprocessor macro __DATE__ / __TIME__
	int16_t year = YEAR(date);
	int8_t month = MONTH(date);
	int8_t day = DAY(date);
	int8_t hour = HOUR(time);
	int8_t minute = MINUTE(time);
	int8_t second = SECOND(time);

	datetime_t t = {
			.year  = year,
			.month = month,
			.day   = day,
			.dotw  = 0, // 0 is Sunday, so 5 is Friday => not used
			.hour  = hour,
			.min   = minute,
			.sec   = second
	};
	// Start the RTC
	rtc_init();
	rtc_set_datetime(&t);
	// clk_sys is >2000x faster than clk_rtc, so datetime is not updated immediately when rtc_get_datetime() is called.
	// the delay is up to 3 RTC clock cycles (which is 64us with the default clock settings)
	busy_wait_us(64);

	Switch::Init();
	UserInterface::Init();
	Heater::Init();
	Heater::SetTarget(35);
	SCPI::Init(usb_transmit);

	xTaskCreate(defaultTask, "defaultTask", 16384, NULL, 3, &main_task);

	vTaskStartScheduler();
	return 0;
}

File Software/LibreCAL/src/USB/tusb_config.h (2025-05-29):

/*
 * The MIT License (MIT)
 *
 * Copyright (c) 2019 Ha Thach (tinyusb.org)
 *
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
 */

#ifndef _TUSB_CONFIG_H_
#define _TUSB_CONFIG_H_

#ifdef __cplusplus
 extern "C" {
#endif

//--------------------------------------------------------------------
// COMMON CONFIGURATION
//--------------------------------------------------------------------

// defined by board.mk
#ifndef CFG_TUSB_MCU
  #error CFG_TUSB_MCU must be defined
#endif

// RHPort number used for device can be defined by board.mk, default to port 0
#ifndef BOARD_DEVICE_RHPORT_NUM
  #define BOARD_DEVICE_RHPORT_NUM     0
#endif

// RHPort max operational speed can defined by board.mk
// Default to Highspeed for MCU with internal HighSpeed PHY (can be port specific), otherwise FullSpeed
#ifndef BOARD_DEVICE_RHPORT_SPEED
  #if (CFG_TUSB_MCU == OPT_MCU_LPC18XX || CFG_TUSB_MCU == OPT_MCU_LPC43XX || CFG_TUSB_MCU == OPT_MCU_MIMXRT10XX || \
       CFG_TUSB_MCU == OPT_MCU_NUC505  || CFG_TUSB_MCU == OPT_MCU_CXD56 || CFG_TUSB_MCU == OPT_MCU_SAMX7X)
    #define BOARD_DEVICE_RHPORT_SPEED   OPT_MODE_HIGH_SPEED
  #else
    #define BOARD_DEVICE_RHPORT_SPEED   OPT_MODE_FULL_SPEED
  #endif
#endif

// Device mode with rhport and speed defined by board.mk
#if   BOARD_DEVICE_RHPORT_NUM == 0
  #define CFG_TUSB_RHPORT0_MODE     (OPT_MODE_DEVICE | BOARD_DEVICE_RHPORT_SPEED)
#elif BOARD_DEVICE_RHPORT_NUM == 1
  #define CFG_TUSB_RHPORT1_MODE     (OPT_MODE_DEVICE | BOARD_DEVICE_RHPORT_SPEED)
#else
  #error "Incorrect RHPort configuration"
#endif

#ifndef CFG_TUSB_OS
#define CFG_TUSB_OS               OPT_OS_NONE
#endif

// CFG_TUSB_DEBUG is defined by compiler in DEBUG build
// #define CFG_TUSB_DEBUG           0

/* USB DMA on some MCUs can only access a specific SRAM region with restriction on alignment.
 * Tinyusb use follows macros to declare transferring memory so that they can be put
 * into those specific section.
 * e.g
 * - CFG_TUSB_MEM SECTION : __attribute__ (( section(".usb_ram") ))
 * - CFG_TUSB_MEM_ALIGN   : __attribute__ ((aligned(4)))
 */
#ifndef CFG_TUSB_MEM_SECTION
#define CFG_TUSB_MEM_SECTION
#endif

#ifndef CFG_TUSB_MEM_ALIGN
#define CFG_TUSB_MEM_ALIGN          __attribute__ ((aligned(4)))
#endif

//--------------------------------------------------------------------
// DEVICE CONFIGURATION
//--------------------------------------------------------------------

#ifndef CFG_TUD_ENDPOINT0_SIZE
#define CFG_TUD_ENDPOINT0_SIZE    64
#endif

//------------- CLASS -------------//
#define CFG_TUD_HID               0
#define CFG_TUD_CDC               1
#define CFG_TUD_MSC               1
#define CFG_TUD_MIDI              0
#define CFG_TUD_VENDOR            1
#define CFG_TUD_USBTMC               1
#define CFG_TUD_USBTMC_ENABLE_INT_EP 0
#define CFG_TUD_USBTMC_ENABLE_488    0

 // CDC FIFO size of TX and RX
 #define CFG_TUD_CDC_RX_BUFSIZE    (TUD_OPT_HIGH_SPEED ? 512 : 256)
 #define CFG_TUD_CDC_TX_BUFSIZE    (TUD_OPT_HIGH_SPEED ? 512 : 256)

 // Vendor FIFO size of TX and RX
 // If not configured vendor endpoints will not be buffered
 #define CFG_TUD_VENDOR_RX_BUFSIZE (TUD_OPT_HIGH_SPEED ? 512 : 256)
 #define CFG_TUD_VENDOR_TX_BUFSIZE (TUD_OPT_HIGH_SPEED ? 512 : 256)

 // MSC Buffer size of Device Mass storage
 #define CFG_TUD_MSC_EP_BUFSIZE   4096

//#define CFG_EXAMPLE_MSC_READONLY

#ifdef __cplusplus
 }
#endif

#endif /* _TUSB_CONFIG_H_ */

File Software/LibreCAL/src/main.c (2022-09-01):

#include "pico/stdlib.h"
#include "pico/unique_id.h"

#include "FreeRTOS.h"
#include "task.h"

#include "USB/usb.h"
#include "ff.h"
#include "serial.h"

#define LED_PIN   (25)

FATFS fs0, fs1;
FIL fil;
FRESULT fr;


static void defaultTask(void* ptr) {
	while(true) {
		vTaskDelay(1);
	}
}

static void usb_rx(const uint8_t *buf, uint16_t len, usb_interface_t i) {
	printf("USB RX\r\n");
	usb_transmit(buf, len, i);
}

int main(void) {
	stdio_init_all();
	gpio_init(LED_PIN);
    gpio_set_dir(LED_PIN, GPIO_OUT);
    gpio_put(LED_PIN, 1);

    printf("Unique ID: %s\r\n", getSerial());

    fr = f_mount(&fs0, "0:", 1);
    if(fr != FR_OK) {
    	printf("mount error disk0 %d\r\n", fr);
    	BYTE work[FF_MAX_SS];
    	fr = f_mkfs("0:", 0, work, sizeof(work));
    	f_setlabel("0:LibreCAL_RW");
    	printf("Formatted disk0: %d\r\n", fr);
        fr = f_mount(&fs0, "0:", 1);
        if(fr != FR_OK) {
        	printf("mount error disk0 %d\r\n", fr);
        }
    }
    fr = f_mount(&fs1, "1:", 1);
    if(fr != FR_OK) {
    	printf("mount error disk1 %d\r\n", fr);
    	BYTE work[FF_MAX_SS];
    	fr = f_mkfs("1:", 0, work, sizeof(work));
    	f_setlabel("1:LibreCAL_R");
    	printf("Formatted disk1: %d\r\n", fr);
        fr = f_mount(&fs1, "1:", 1);
        if(fr != FR_OK) {
        	printf("mount error disk1 %d\r\n", fr);
        }
    }
    /* Create a file as new */
    fr = f_open(&fil, "1:serial.txt", FA_CREATE_NEW | FA_WRITE);
    if (fr) {
    	printf("f_open: %d\r\n", fr);
    }

    /* Write a message */
    UINT bw;
    f_write(&fil, getSerial(), strlen(getSerial()), &bw);
    /* Close the file */
    f_close(&fil);

    fr = f_open(&fil, "0:readwrite.txt", FA_CREATE_NEW | FA_WRITE);
    if (fr) {
    	printf("f_open: %d\r\n", fr);
    }

    /* Write a message */
    const char *str = "You can change this";
    f_write(&fil, str, strlen(str), &bw);
    /* Close the file */
    f_close(&fil);

    usb_init(usb_rx);

    xTaskCreate(defaultTask, "defaultTask", 1024, NULL, 3, NULL);

    vTaskStartScheduler();
    return 0;
}

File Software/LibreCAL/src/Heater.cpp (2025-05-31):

#include "Heater.hpp"

#include "pico/stdlib.h"
#include "hardware/pwm.h"
#include "hardware/adc.h"

#include "FreeRTOS.h"
#include "task.h"

#include <cmath>

static uint8_t target;
static bool stable = false;
static float temp;
static float power;

using namespace Heater;

static void setPWM(uint16_t power) {
	uint slice = pwm_gpio_to_slice_num(PWMPin);
	uint channel = pwm_gpio_to_channel(PWMPin);
	pwm_set_chan_level(slice, channel, power);
}

void HeaterTask(void*) {
	// Controller parameters
	constexpr float assumed_ambient = 22.0f; // in °C
	constexpr float thermal_resistance = 30.0f; // in °C/W
	constexpr float P = 0.4f; // in W/delta°C
	constexpr float I = 0.05f; // in W/delta°C/s
	constexpr float I_limit = 2.0f;
	constexpr float ControllerPeriod = 0.05;

	// Stable check paramters
	constexpr float allowedDeviation = 0.25f;
	constexpr uint16_t minStableTime = 60000;

	static constexpr float alpha = 0.95;
	float adc_avg = adc_read();
	float integral = 0.0f;

	uint32_t lastUnstableTime = xTaskGetTickCount();

	while(1) {

		adc_avg = adc_read() * (1.0f - alpha) + adc_avg * alpha;
		// Reference resistor is 10k, NTC has additional 100 Ohm in series
		float NTC_resistance = adc_avg / (4096 - adc_avg) * 10000 - 100;
		constexpr float NTC_nominal = 10000.0f;
		constexpr float NTC_B = 4300.0f;
		constexpr float T0 = 25.0f;
		constexpr float Tzero = 273.15f;
		temp = (T0 + Tzero) * NTC_B / ((T0 + Tzero) * logf(NTC_resistance / NTC_nominal) + NTC_B) - Tzero;

		float basePower = (temp - assumed_ambient) / thermal_resistance; // required power to hold current temperature
		float deviation = target - temp;
		if(power < maxPower || power > 0) {
			// only update integral term when not already at control limit
			integral += deviation * I * ControllerPeriod;
		}
		// anti windup
		if(integral > I_limit) {
			integral = I_limit;
		} else if(integral < -I_limit) {
			integral = -I_limit;
		}
		float p = deviation * P + integral;
		if(p > maxPower) {
			p = maxPower;
		} else if(p < 0) {
			p = 0;
		}
		power = p;

		// convert power to PWM, maximum power is approximately 1.9W
		int32_t pwm = power * UINT16_MAX / maxPower;
		if(pwm > UINT16_MAX) {
			pwm = UINT16_MAX;
		} else if(pwm < 0) {
			pwm = 0;
		}
		setPWM(pwm);

		// check if temperature is stable
		if(fabs(temp - target) > allowedDeviation) {
			stable = false;
			lastUnstableTime = xTaskGetTickCount();
		} else if(xTaskGetTickCount() - lastUnstableTime > minStableTime) {
			stable = true;
		}

		vTaskDelay(ControllerPeriod * 1000);
	}
}

void Heater::Init() {
	gpio_set_function(PWMPin, GPIO_FUNC_PWM);
	uint slice = pwm_gpio_to_slice_num(PWMPin);
	uint channel = pwm_gpio_to_channel(PWMPin);
	pwm_set_clkdiv(slice, 95.38f); // for 20Hz PWM
	pwm_set_wrap(slice, UINT16_MAX);
	setPWM(0);
	pwm_set_enabled(slice, true);

	adc_init();
	adc_gpio_init(ADCPin);
	adc_select_input(ADCPin - 26);

	xTaskCreate(HeaterTask, "Heater", 512, NULL, 3, NULL);
}

void Heater::SetTarget(uint8_t celsius) {
	target = celsius;
}

float Heater::GetTemp() {
	return temp;
}

bool Heater::IsStable() {
	return stable;
}

float Heater::GetPower() {
	return power;
}

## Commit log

2022-08-24 Partial routing
    [LibreCAL.kicad_pcb, LibreCAL.kicad_sch, MCU.kicad_sch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]
2022-08-30 Filters added, housing updated
    [BottomCover.step, HRO_TYPE-C-31-M-12.step, LibreCAL.kicad_pcb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]
2022-08-30 Production files
    [BottomCover.step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]
2022-08-30 PnP files, removed zipped gerber
2022-08-30 add BOM
    [BOM.csv]
2022-08-30 Basic compilable FreeRTOS port for raspberry pico
2022-09-01 Mass storage device test with fatfs and ramdisk
2022-09-06 USB thread decoupling, additional SCPI commands
2022-09-07 Use external SPI flash instead of RAM
2022-09-09 Save coefficient sets to device
2022-09-13 Buttons/LEDs handling
2022-10-02 device outline added + bug fixes
    [Switch.cpp, UserInterface.cpp, main.cpp]
2022-10-03 disable buttons when device disconnected
2022-10-03 Rendering of PCB
2022-11-10 replaced bootsel switch, adjusted covers
    [BottomCover.step, LibreCAL.kicad_pcb, LibreCAL.kicad_sch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]
2022-11-10 Various improvements
    - Improve temperature controller response
    - Detect disconnected device in GUI
    - Added command to enter bootloader mode
2022-11-10 Pictures of first prototype
2022-11-10 Match PCB picture sizes
2022-11-10 Schematic/PnP/BOM update
    [BOM.csv]
2022-11-13 remove printf, add command to clear factory coefficients
2022-11-16 Fix through configuration through switches
    [Switch.cpp]
2023-01-12 Fix HRO TYPEC-C-31-M-12 STEP which have issues with FreeCad/KiCadStepUp
    [HRO_TYPE-C-31-M-12.step]
2023-01-12 Improvements on LibreCAL KiCad: fixed minor errors/labels(cosmetic), improved BOM(Added LCSC_Part), improved Impedance JLCPCB 4Layer JLC7628 1.6mm
    [LibreCAL.kicad_pcb, LibreCAL.kicad_sch, MCU.kicad_sch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]
2023-01-12 Add TopCover 2D TextLaserEngraving (FreeCad Projet+DXF) using OpenSans-Light.ttf
    [TopCover_2D_TextLaserEngraving.FCStd, TopCover_2D_TextLaserEngraving.dxf]
2023-01-13 Add Laser Engraving for SMA PORT1/2/3/4
    [TopCover_2D_TextLaserEngraving.FCStd, TopCover_2D_TextLaserEngraving.dxf]
2023-01-13 Minor fix in LibreCAD KiCad 3D View for HRO_TYPE-C-31-M-12.step
    [LibreCAL.kicad_pcb, LibreCAL.kicad_sch, MCU.kicad_sch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]
2023-01-23 Allow higher I term for temperature control in colder environments
2023-03-17 Revert back to 1.4.0 of the pico-sdk
2023-03-26 Fix MONTH(date) macro bugs (now it is fully validated from Jan to Dec)
    [main.cpp]
2023-03-26 Prevent potential threading issue when loading coefficients
2023-03-26 LibreCAL-GUI modifications On LibreCAL connection (only with firmware v0.2 or more) set LibreCAL Date Time UTC with local PC Date Time UTC On Main view status (only with firmware v0.2 or more) add Da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
2023-04-17 Update to new VID/PID from pidcodes
2023-11-30 update to larger flash for calibration coefficients
    [BOM.csv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]
2023-12-15 PnP file
    [LibreCAL-all-pos.csv]
2024-01-13 remove accidentally added kicad locks
2024-06-27 update pick-and-place files
    [LibreCAL-all-pos.csv]
2024-08-03 Update main.cpp
    Fix macro DAY for case is less 10 (with space instead of expected '0' character)
    [main.cpp]
2024-09-24 switch to Qt6
2024-09-24 improve factory calibration scipts
2024-09-25 update to pico SDK 2.0.0
2024-11-01 factory calibration script improvement
2025-01-21 FTP upload option during factory calibration
2025-03-03 update to pico SDK 2.1.1
2025-05-13 switch FW build to Ubuntu 24.04
2025-05-29 Add support for Siglent eCal emulation.
    This patch allows a Siglent SVA1032X to calibrate using a LibreCAL. It
    adds support in the firmware to boot into a Siglent-compatible mode
    (removes USB MSC, to avoid the instrument's UI trying to write to the
    disk; adds a very limited USB TMC that knows how to speak the Siglent
    calibration commands) when Siglent calibration coefficients are present,
    and the unit has the FUNCTION key held while powering on.
    We also add a `convert_siglent.py` script, which converts the
    calibration data stored in the LibreCAL's native Touchstone format to
    the reverse-engineered header and ZIP+CSV format that a Siglent VNA
    requires. Some fields in the Siglent header are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
    [UserInterface.cpp, main.cpp, tusb_config.h]
2025-05-30 Improvements to Siglent emulation mode
    - handle *IDN? response and SET:PORT commands send by some VNAs
    - default to emulation mode if files are present (press function to force default mode)
    - Adjusted script to set number of ports and handle early LibreCALs with partially missing factory data
    - Add optional logging to LibreCAL firmware
    - indicate emulation mode by blinking wait/ready LEDs
    [Log.cpp, UserInterface.cpp, main.cpp]
2025-05-30 sw/usb_descriptors: support CDC in Siglent mode to make it possible to kick the device into bootloader mode without pressing buttons
2025-05-31 Further toolchain build tests/debugging
    - revert back to standard toolchain
    - Fix USB deadlock
    - Fix CS timing problem on SPI flash
    [Flash.cpp, main.cpp]
2025-05-31 prevent USB task from starving heater and UI task
    [Heater.cpp, UserInterface.cpp]
2025-07-20 Implement windows build fixes
    - Switch to windows-2025
    - Switch to Qt 6.2.4
    - Switch to v4 of jurplel/install-qt-action
2026-10-02 Switch from pcre (deprecated) to pcre2
